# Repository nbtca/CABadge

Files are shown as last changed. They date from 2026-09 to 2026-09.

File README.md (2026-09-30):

# CABadge · 计协电子吧唧

CABadge 是为计算机协会设计的可自定义电子徽章。项目希望将传统吧唧的身份表达与电子屏幕的可变内容结合，让佩戴者通过壁纸、图案和协会名片展示个人喜好与社团归属。

它以日常佩戴和内容展示为核心：平时展示喜欢的画面，需要时通过触摸操作切换内容，通过无线连接或电脑工具更新壁纸、管理设备。界面尽量简洁，让展示内容本身成为主角。

这里收录硬件设计、固件源码、配套电脑工具和实板测试记录，供复刻、改进和协作开发使用。

**当前正式版本：v1.2.0 / 内部固件 7.9.16-eaf-transition。** 包含统一缓存位图转场、Direct Compositor 和内存优化。已完成编译、烧录及基本功能检查；长期稳定性与完整人工验收仍在完善。

[下载 v1.2.0](https://github.com/nbtca/CABadge/releases/tag/v1.2.0) · [发布与升级说明](docs/RELEASE-v1.2.0.md) · [已知问题](docs/KNOWN_ISSUES.md) · [实板测试记录](首板测试记录.md)

当前 `main` 源码版本为 **7.9.16-eaf-transition**，包含 BlueMap 下载/缓存改进、统一壁纸库、EAF Direct 动态壁纸与逐资源 timing、冻结当前帧的页面转场，以及 [动态壁纸转换说明](docs/EAF_TIMING.md)。上方 v1.2.0 下载链接对应同版固件；最新源码构建方法见 [BUILD](docs/BUILD.md)，验证范围见 [HANDOFF](firmware-v7/HANDOFF.md)。

## 可以做什么

- **展示与切换壁纸**：圆形触摸屏展示静态图片，支持浏览、选择和保存上传的壁纸。
- **展示协会名片**：内置计协风格名片页面。
- **连接与管理设备**：Wi-Fi、BLE 连接管理，通过 USB 或本地 HTTP 上传壁纸。
- **基础交互**：触摸操作、亮度设置、息屏后摇晃唤醒，以及可选 FPS 显示。
- **小应用**：Grok 表情、MC 二维地图、奶蛙矿工；使用说明见 [应用](firmware-v7/APPS.md)。
- **电脑端调试**：Windows 原生 NBTCA Badge TOOL 提供固件安装与设备联调入口。

44ebd1ad073642b58210a89b23977e9f
2ba59d724997cc1bf2ca568b1a78c989
10e58efb694e944809ac0757480d7f42

当前源码支持在电脑上将 GIF/视频转换为 EAF 动态壁纸，设备不直接播放 GIF/视频。BLE 传图和 OTA 尚未提供。完整的异常场景和长期稳定性测试仍在完善中。

## 硬件概览

|部分|当前方案|
|---|---|
|主控|ESP32-S3R8，8 MB Octal PSRAM|
|外部 Flash|W25Q128JVSIQ，16 MB|
|显示与输入|360×360 圆形 ST77916 屏幕、触摸输入|
|运动传感器|SC7A20|
|主电源|SGM62117 升降压至 3.3 V|
|充电|TP4056-MS，配合外围供电分配与充电使能电路|
|PCB|直径 50 mm、四层板、名义板厚 1.6 mm|

当前配套硬件为 **JXBadge_EVT_20260909_c7c59dff**。完整器件型号、封装及采购编号见 [BOM](hardware/BOM-DRAFT.csv)。

## 如何开始复刻

复刻需要自行采购、焊接和调试。板上包含 QFN 主控和细间距 FPC 连接器，建议具备贴片焊接与万用表排查经验，并准备放大观察工具及合适的焊接设备。

**流程：下载配套资料 → 核对采购 → PCB 打样 → 分阶段焊接与上电 → 烧录 → 功能检查。** 已有装配完成的同版硬件，可以从第 5 步开始。

### 1. 下载固件与配套硬件

固件下载 [v1.2.0 Release](https://github.com/nbtca/CABadge/releases/tag/v1.2.0)，硬件生产包沿用 [v1.0 Release](https://github.com/nbtca/CABadge/releases/tag/v1.0)。固件版本与 PCB 修订独立编号，v1.2.0 没有改板。

|文件|用途|
|---|---|
|`CABadge-v1.2.0-firmware.zip`|当前三个 BIN、安装说明、原始验证清单与校验值|
|`CABadge-v1.2.0-debug.zip`|ELF、有效构建配置，仅排查问题时需要|
|`CABadge-v1.0-hardware-c7c59dff.zip`|冻结 PCB 生产包、可选钢网文件与下单说明|
|v1.2.0 的 `Source code (zip)`|该次发布源码、硬件设计与文档|

首次点亮直接使用发布固件，无需先搭建编译环境。下载后可通过 Release 的 `SHA256SUMS.txt` 核对附件完整性。

### 2. 核对器件与装配

先查看 [BOM](hardware/BOM-DRAFT.csv)、[采购料号表](hardware/LCSC_IMPORT_LIST.csv) 和 [交互式 BOM](hardware/bom/ibom.html)。交互式 BOM 下载到本地后用浏览器打开，可对照板上位置检查元件。

需要看电路时，用 KiCad 10 打开 [JXBadge_V1.kicad_pro](hardware/JXBadge_V1.kicad_pro)，保留同目录的原理图、符号库、封装库及 3D 模型。

采购时重点核对屏幕完整型号、排线引脚定义、FPC 座的接触方向与封装，不能仅凭“360×360”或“18 针”判断兼容。电池也需核对极性、保护、尺寸与安装空间。BOM 文件保留 `DRAFT` 名称，采购前应结合原理图和 [首板测试记录](首板测试记录.md) 复核，不能当作已验证的即买即装套件清单。

### 3. PCB 打样

解开硬件附件，将其中的 **`JXBadge_EVT_20260909_c7c59dff_PCB.zip`** 交给板厂；不要上传外层发布压缩包，也不要把钢网包当作 PCB 包。

按 [下单说明](hardware/fabrication/JXBadge_EVT_20260909_c7c59dff/下单说明.md) 核对四层、1.6 mm 板厚、50 mm 圆板及目标叠层 `JLC04161H-7628`。叠层、孔工艺和局部间距要求需由板厂确认。需要钢网时，另外使用 `TOP_STENCIL.zip`。

### 4. 分阶段焊接与首次上电

按 [焊接与分阶段上电检查](焊接与分阶段上电检查_首板.md) 分组完成：USB 输入 → 3.3 V 电源 → 主控与 USB 下载 → 屏幕与触摸 → 电池与充电。

首次排查可以只用 USB 供电、不接电池。每增加一组先断电检查焊接与短路，再上电测量；不要带电插拔屏幕排线。确认主电源和主控正常后再接入屏幕。

首板换装的 J1 规格为 **FFC/FPC 0.5 mm、18P、抽屉式上接触**，换座后已成功显示。当前 [BOM](hardware/BOM-DRAFT.csv) 与 [采购表](hardware/LCSC_IMPORT_LIST.csv) 已按截图更正；厂家型号和尺寸图仍未提供，采购前须核对封装与接触方向。**v1.0 旧源码、原理图和交互式 BOM 中仍有原 J1 条目，采购请以 [J1 连接器更正](docs/J1-CONNECTOR.md) 为准。**

### 5. 烧录当前固件 7.9.16-eaf-transition

解压固件包，按包内 `README.md` 或 [安装与构建说明](docs/BUILD.md) 操作。烧录前核对校验值和硬件版本，使用支持数据传输的 USB 线，并释放被其他程序占用的串口。

|文件|烧录地址|
|---|---|
|`bootloader.bin`|`0x0`|
|`partitions.bin`|`0x8000`|
|`firmware.bin`|`0x10000`|

可以用 esptool 直接烧录，也可以使用 v7 工作台的固件安装入口。使用工作台时，将固件解压到源码根目录下的 `outputs/cabadge-v7.9.16-eaf-transition/`；具体 Python 依赖见安装说明。

烧录完成后 RESET，确认启动的固件版本为 **7.9.16-eaf-transition**。不要为了普通升级额外执行全片擦除，以免清掉已有设置和壁纸。

### 6. 检查自己的板子

依次检查开机显示、触摸与翻页、壁纸切换、Wi-Fi/BLE 基本连接，再检查上传壁纸及重启后的保留情况。遇到问题时记录固件版本、触发步骤和现象，附上照片或串口日志，方便复现与修复。

当前背光已使用平方曲线调节实际 PWM，旧 5% 测试上限已取消；CHG_ALLOW 仍保持 LOW。成功开机不代表充电、电流温升或长期运行已完整验收。显示 TE 未连接，动态画面仍需观察是否撕裂；具体待办见 [已知问题](docs/KNOWN_ISSUES.md)。

## 继续开发

完成首次点亮后，再按 [安装与构建说明](docs/BUILD.md) 恢复开发环境。当前工程使用 LVGL 9.4.0；桌面预览基于 SDL2，板端使用 ESP-IDF / PlatformIO。构建脚本仍有 Windows 和 F 盘路径限制，尚未整理成跨平台的一键构建流程。

|目录|内容|
|---|---|
|`firmware-v7/`|当前固件、UI、工作台、协议与测试|
|`hardware/`|KiCad 工程、项目库、BOM 与生产文件|
|`tools/flasher/`|共用烧录工具|
|`docs/`|安装、构建、发布与已知问题说明|

历史实验固件、原始日志和本地备份没有全部随仓库上传，旧文档中的部分研究链接仅保留为历史出处。`v1.0`、`v1.2.0` 标签固定各次发布快照；主分支继续更新。文档分类见 [仓库索引](docs/INDEX.md)。

## 许可

本项目原创内容采用 [MIT License](LICENSE)。第三方字体、库、模型和素材仍遵循各自许可，不因本项目采用 MIT 而改变；字体许可见 [FONT-LICENSE.txt](firmware-v7/ui/FONT-LICENSE.txt)。

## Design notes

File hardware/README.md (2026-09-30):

# CABadge c7c59dff 硬件复刻

当前固件 v1.1.0 使用原硬件基线，未改板。KiCad 10 打开 [JXBadge_V1.kicad_pro](JXBadge_V1.kicad_pro)，保持本目录结构。

## 必须一起保留的文件

- 项目、根原理图、Controls_Test / Display_Sensor / USB_Power 子页、PCB 和设计规则。
- JXBadge.kicad_sym、JXBadge.pretty、JXBadge.3dshapes 及两份 lib-table：工程使用 KIPRJMOD 相对引用，不随意移动或删减。
- [BOM](BOM-DRAFT.csv)、[采购表](LCSC_IMPORT_LIST.csv)、[交互式 BOM](bom/ibom.html)：后者下载后在浏览器打开，辅助焊接定位。
- [冻结生产包与下单说明](fabrication/JXBadge_EVT_20260909_c7c59dff/下单说明.md)：PCB ZIP 和顶层钢网 ZIP 分开使用；MANIFEST 中的文件整组保持一致。

## 采购与装配

3D打印外壳：[V6 三个打印模型（STL）与实物照片](enclosure/releases/V6_20260930/README.md)。用户反馈总体可用、细节仍有瑕疵；打印及装配前先读包内的拨片入口修边说明。

首板换装 J1 为 FFC/FPC 0.5 mm、18P、抽屉式上接触。厂家精确型号及尺寸图仍待提供；[J1 连接器更正](../docs/J1-CONNECTOR.md) 优先于原理图/库/交互式 BOM 中的旧采购标识，不可直接将原 C2856802 当成已验证替代。

### 电池与屏幕连接器

2026-09-30 用户确认当前装配用料，已同步 [BOM](BOM-DRAFT.csv) 和 [采购表](LCSC_IMPORT_LIST.csv)：

- 电池：**450mAh，42×30×4mm，每台1只**；正负两根线直接焊接，**J3电池座不装**。`BAT_EXT` 是整机外购件的清单标识，不是PCB新增位号。容量及尺寸为用户提供，厂家型号、保护板参数和尺寸公差未提供，不推定料号，也不据此宣称充电或挤压验证通过。
- J1：**FFC/FPC 0.5mm、18P、抽屉式上接触，每板1只**，沿用首板换装规格，不是翻盖下接。现用件厂家型号和立创编号仍未提供，不以原 C2856802 代填。

BOM中J3标为DNP、采购数量为0；其旧料号和J1旧封装名仅保留追溯。原理图、PCB、交互式BOM及冻结生产包保持原设计快照，以当前两份CSV的采购/装配状态为准。

板为 50 mm 圆形、四层、名义 1.6 mm，目标叠层 JLC04161H-7628；订单工艺须由板厂确认。制造 ZIP 的正确性检查不等于机械适配、射频、充电或产品可靠性验收。

按[焊接与分阶段上电检查](../焊接与分阶段上电检查_首板.md)逐组断电检查与上电，使用板上 VBUS/3V3/GND/BAT/PWR/EN 丝印。不要带电插拔屏幕排线。

## 固件与证据

下载 [v1.1.0](https://github.com/nbtca/CABadge/releases/tag/v1.1.0)，按[安装说明](../docs/RELEASE-v1.1.0.md)烧录。当前实板结果与历史故障见[首板测试记录](../首板测试记录.md)，不把历史 CAD 检查等同于实板全部通过。

运行 `python docs/check_repository.py` 可核对制造 MANIFEST 文件字节数和 SHA-256。冻结验证目录中的原始源快照用于追溯制造包，不是另一个现行硬件版本。

[精简前硬件设计与 CAD 历史](https://github.com/nbtca/CABadge/blob/d1fe9716b383dcb6fd292d683265beacd92fde64/hardware/README.md)

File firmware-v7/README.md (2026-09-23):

# CABadge 当前实体固件

项目发布 **v1.1.0**，内部版本 **7.9.2-memory**；发布说明、安装与已知边界以 [Release](../docs/RELEASE-v1.1.0.md) 为准。`run.cmd` 打开原生工作台，默认包为 `outputs/cabadge-v7.9.2-memory`，不是旧 USB 画面预览。

## 使用入口

- 展示页：壁纸与蓝色名片；下拉控制中心，上滑功能面板。
- 功能面板：壁纸管理、设置和应用入口；[应用说明](APPS.md)、[Grok 操作](GROK.md)。
- 连接：Wi-Fi、BLE、手机管理；同网或开放直连热点上传/应用/删除壁纸，无授权码和倒计时。
- 设置：显示、设备信息和息屏；亮度驱动实际背光，减少动态直接切终态。设备信息包含外部 16 MB Flash 容量信息。
- USB 保留烧录、状态/控制和壁纸传输；旧像素投屏与壁纸读回已移除。

## 当前显示与内存架构

ESP32-S3R8、8 MiB PSRAM、ST77916 360×360 RGB565、QSPI 40 MHz、CST816D；ESP-IDF 6.1.0、LVGL 9.4.0、esp_lvgl_adapter 0.7.1。PARTIAL、双 360×360 PSRAM 绘图缓冲、DRAW_UNIT=1、DMA queue=2。

静止显示真实 LVGL 控件；静态/半静态转场使用单份 LCD-native RGB565 缓存与 Direct Compositor。缓存未 READY 时走安全路径，动态 App 本体实时绘制。缓存预算 NORMAL 最高 3 MiB，HIGH 软目标 1 MiB，CRITICAL 512 KiB；保护在用缓冲，内存压力下暂停预热。Flash L2 未启用。

LVGL 与 Direct 互斥共用两块 11,520 B 内部 DMA staging；最后 DMA 完成后才通知 LVGL。无 TE，不保证所有动态画面无扫描撕裂。LCD 提交次数不是面板扫描 Hz。

BlueMap 使用 16 KiB HTTP + Pngle 流式采样，不创建整张 RGBA；用户缩略图五项 LRU 加至多一张待提交图。内置壁纸使用 Flash 原图；名片没有独立常驻快照。

## 开发与验证

板端入口：`usb_screen/build.ps1`；[完整构建说明](../docs/BUILD.md)。源码路径：`ui/` 为页面/cache/compositor，`usb_screen/device/src/` 为驱动与服务。`usb_screen` 是沿用的目录名。

最小检查：`test_map_stream.py`、`test_physical_display.py`、`test_transition_compositor.py`。实板检查记录见 [R63/R64](../首板测试记录.md)，软件检查不能替代目视验收。

旧桌面模拟器、像素投屏与废弃测试已移出当前树。保留三个当前内存/DMA/compositor 最小检查和工作台 USB framing 自检；历史工具可从 Git 旧提交恢复。板端构建仍使用 `usb_screen/build.ps1`。

[当前交接与历史演进](HANDOFF.md) · [文档索引](../docs/INDEX.md) · [已知限制](../docs/KNOWN_ISSUES.md)

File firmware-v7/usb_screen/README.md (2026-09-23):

# CABadge 板端服务与 USB 工具

当前版本 **v1.1.0 / 7.9.2-memory**。本目录名称沿用早期 USB 屏幕阶段；现固件直接驱动实体 ST77916，旧 USB 像素投屏及壁纸读回已移除。

## 使用

- 安装：见 [正式发布与升级](../../docs/RELEASE-v1.1.0.md)，或运行 `../run.cmd` 的工作台安装入口。默认包为 outputs/cabadge-v7.9.2-memory。
- USB：烧录、状态/控制、壁纸上传；不提供实时画面镜像。
- 手机管理：在设备“连接 → 手机管理”打开。同一网络访问设备显示的地址；直连模式连接 CABadge-xxxx 开放热点并访问 http://192.168.4.1/ 。无访问码或 300 秒授权窗口。
- 壁纸：手机/电脑裁剪为 360×360 RGB565 后上传，支持保存多张、应用与删除。wallpaper 分区从 0x710000 起，长度 0x8f0000，最多 31 张用户图片；恢复默认不删除图库。旧分区升级注意事项见正式发布说明。
- Wi-Fi：扫描、连接、保存历史网络和重连；手机热点要允许设备访问所需网络。
- BLE：NimBLE 状态/控制、广播与扫描连接；不提供经典蓝牙音频或 BLE 图片传输。
- SC7A20：仅息屏时摇晃唤醒，亮屏不跳页；不是主控深度睡眠。

## 源码导航

|路径|职责|
|---|---|
|device/src/main.c|Adapter 接入、GUI 调度与 USB 服务|
|device/src/physical_display.c|ST77916、触摸、显示 ownership、共享 DMA staging|
|device/src/wifi_service.c / ble_service.c|无线任务与状态|
|device/src/wallpaper_service.c / wallpaper_store.c|HTTP/USB 壁纸库、异步缩略图与持久化|
|device/src/wallpaper.html|手机本地管理页面|
|device/src/app_service.c / map_png.c|BlueMap 网络与流式解码|
|../ui/ui_transition_cache.c / ui_transition_compositor.c|缓存、预热及 Direct 转场|
|../workbench.py / framing.py|当前原生工作台与 USB 编解码|

构建入口 `build.ps1`，实际环境见 [构建说明](../../docs/BUILD.md)。当前有真实背光 PWM 和 LCD/触摸驱动，不再采用早期“只在电脑显示”的接法。不要按旧说明拔屏或烧录 v4/v5 预览包。

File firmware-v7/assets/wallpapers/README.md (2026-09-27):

# EAF 动态壁纸

7.9.14-eaf-direct 保留 `espressif/esp_lv_eaf_player 0.3.0` 的底层格式解析、RLE 解码和调色板转换，旁路 `lv_eaf` 对象/定时器。目标 33,333 us/帧（30 FPS），无限循环；首页逐帧由 Direct Compositor 输出，不经过 LVGL renderer。完成提交率不等于面板扫描刷新率。

`live_test.eaf` 是 360×360 测试动画。资源**不编进应用**；导入后作为 `EAF` 条目存入现有 `wallpaper` 分区的普通壁纸槽，和静态壁纸一样选择、删除、保存当前选择。开机不会重新导入已删除资源。

在项目根目录使用：

```powershell
python tools/upload_eaf.py firmware-v7/assets/wallpapers/live_test.eaf --port COM3
```

其他素材的格式、转换与 timing 要求见 [动态壁纸转换说明](../../../docs/EAF_TIMING.md)。转换工具不随仓库发布，上传工具保留。7.9.15起可用配套 timing metadata 保留原始播放节奏；没有 metadata 的旧 EAF 默认30FPS。

## 读取与生命周期

- 组件的文件路径 API 会完整读文件入 RAM，因此本项目使用 `esp_partition_mmap` 和 `esp_eaf_format_init`，直接引用 Flash 压缩数据，不注册第二套文件系统。
- 正常只保存一张 259,200 B RGB565 解码帧及 8,640 B 可复用索引块；帧索引、后端及解析临时缓冲使用 PSRAM。每帧调用官方 RLE 解码器，按调色板直接写入 LCD 字节序的当前帧；不复制完整帧到 LVGL buffer。构建时仅对固定版本组件关闭分配失败后回退内部 RAM 的路径；软件 JPEG 关闭。
- 干净首页实时播放；按下开始手势、菜单/应用、转场、息屏，以及状态入口/提示/HUD 显示时暂停并交回 LVGL；返回干净首页恢复。切换壁纸删除旧播放器后再解除旧 Flash 映射。暂停保留当前解码帧，不重复创建播放器。
- 动态首页不进入 Raster Cache。需要该背景的转场安全回退到暂停帧的 LVGL 路径，其他静态页面的 Direct Compositor 不变。
- 动态缩略图在首次选择后从已解码帧生成，纳入已有缩略图 LRU；尚未选择/已淘汰的动态项仍可按文字选择，不在后台另开播放器制作预览。
- USB 管理状态 `wallpaper.types` 给出 STATIC/EAF；`wallpaper.eaf` 提供 loaded/playing/frame/creates 和创建时堆差额，便于基本检查，不开启串口文本日志。

Flash 格式：保留旧静态 `JXWL` 记录，新增 `JXWE` EAF 记录；每槽大小、已有图片 ID、分区表均不变。7.9.13 起，大 EAF 使用连续空槽（一个 3 MiB 文件占 12 槽），静态图片仍用一槽。空间不足或没有足够连续空槽时拒绝上传，不移动或覆盖其他壁纸。EAF 上传按接收进度逐扇区擦除、分块写 Flash，校验后才发布记录，不申请完整文件大小的 PSRAM；未完成上传在重启扫描时清理。删除正在播放的 EAF 时先暂停源读取，再擦除与释放。旧版固件不识别 EAF 槽，回退旧版后请勿继续上传，以免旧版把动态槽当作空闲覆盖。

## 直出所有权与内存（7.9.14）

复用 `ui_transition_compositor` 的现有 4 KiB 栈任务和 `physical_display` 的两块 11,520 B DMA staging。worker 在上一帧 DMA 排空后才解码下一帧；每帧按 16 行分块搬运到 staging，共 23 次 draw 提交。无另一张完整中转 framebuffer，不把完整压缩动画读入 RAM。

暂停由 GUI 发送停止消息并等待 worker 确认，依赖真实 LCD drain 完成；再恢复 LVGL 显示所有权。在 GUI 锁内把同一当前帧原地转为 CPU RGB565，供冻结画面、缩略图和转场使用。恢复后 worker 直接解码下一帧为 LCD 字节序。真实页面及触摸仍由 LVGL 管理，worker 不调用 LVGL。动态背景涉及的旧安全转场路径保留。

USB `wallpaper.eaf.timing` 提供聚合耗时，无逐帧文本日志：`decode_us`、`staging_us`、`submit_us`、`dma_drain_us`、`interval_us`。submit 包含前一块 DMA 等待；dma_drain 仅为最后一块剩余等待，不能当成整帧 DMA 时间。统计在每次直出恢复时重置。

本轮短时实板：罗小黑 210 帧素材，最后 180 帧完成间隔平均 33.378 ms（约 29.96 次/秒），最差 39.319 ms。菜单/息屏暂停、恢复不重建、静态/动态切换经 USB 状态确认；没有长期压力及物理扫描率测量，无 TE 下视觉撕裂仍需实屏确认。详见主测试记录 R79。

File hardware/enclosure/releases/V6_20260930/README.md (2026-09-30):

# CABadge V6 外壳打印文件

2026-09-30 实物试装版本。用户反馈：**“总体可以的，有些细节有瑕疵。”** 保留当次打印文件，不是消除全部瑕疵后的定版。

## 三个打印模型

- [上壳 V6_Upper.STL](V6_Upper.STL)
- [下壳 V6_Lower.STL](V6_Lower.STL)
- [电源拨片 V6_Slider.STL](V6_Slider.STL)

三个模型合计323252字节（约316 KiB）。单位mm，切片保持100%比例。不上传SW装配、PCB参考件或其他模型。

名义最大外径62mm、总高13.9mm，中段外鼓，两片壳体胶粘。叠层为屏幕—42×30×4mm电池—PCB，元件朝屏幕；不装电池座，两根线直接焊接。BOOT/RESET不留外部孔。这些是设计参数，不是照片实测。

## 已知装配注意

原上壳拨片外侧宽凹槽底部两侧各有约0.4mm薄挡边，CAD复核发现会阻挡装入。若拨片装不进去，仅将这两处薄边修通至下沿，不剪内导轨或拨片限位片；对空壳少量修整并去毛刺，不带着屏幕、电池剪。用户曾表示必要时修剪，但未明确反馈是否已剪。

先干装：屏幕FPC先穿过上壳并接好，整理绝缘片、电池及内部走线；**拨片先从外侧套到开关柄，再将上壳罩下**，最后屏幕落在背胶承托台阶。封胶前确认USB线插到底、开关两端到位、线不夹缝、电池不受压。

## 用户实物照片

照片展示打印外壳及装入点亮的屏幕，不单独证明内部无顶压、USB/拨片全功能或长期使用通过。具体瑕疵尚待反馈。

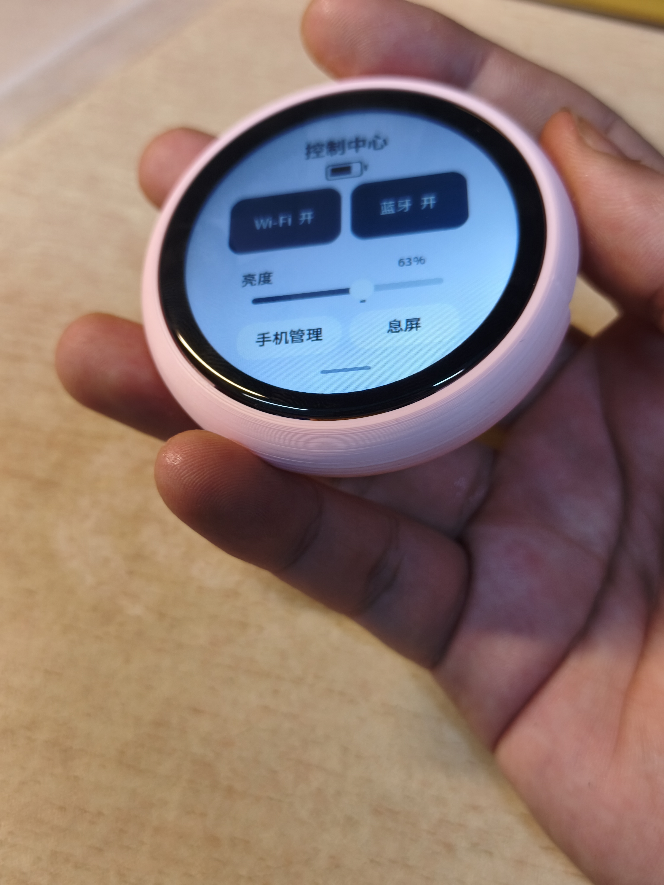
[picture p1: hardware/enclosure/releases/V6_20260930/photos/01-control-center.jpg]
控制中心与手持外观


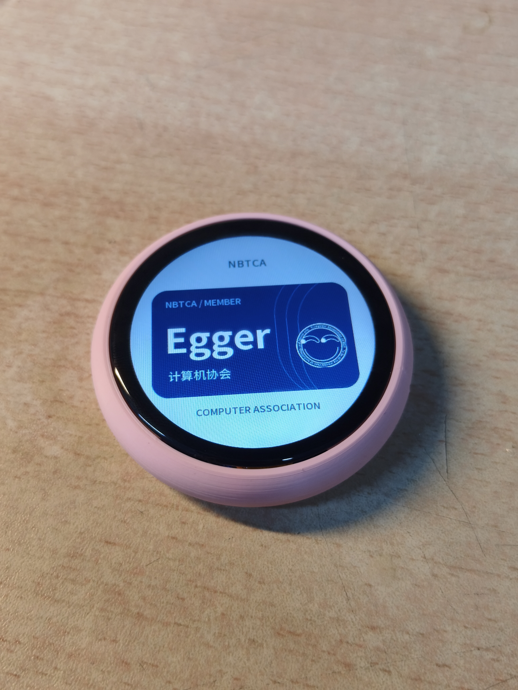
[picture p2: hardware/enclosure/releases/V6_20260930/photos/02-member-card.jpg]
会员名片与外壳正面


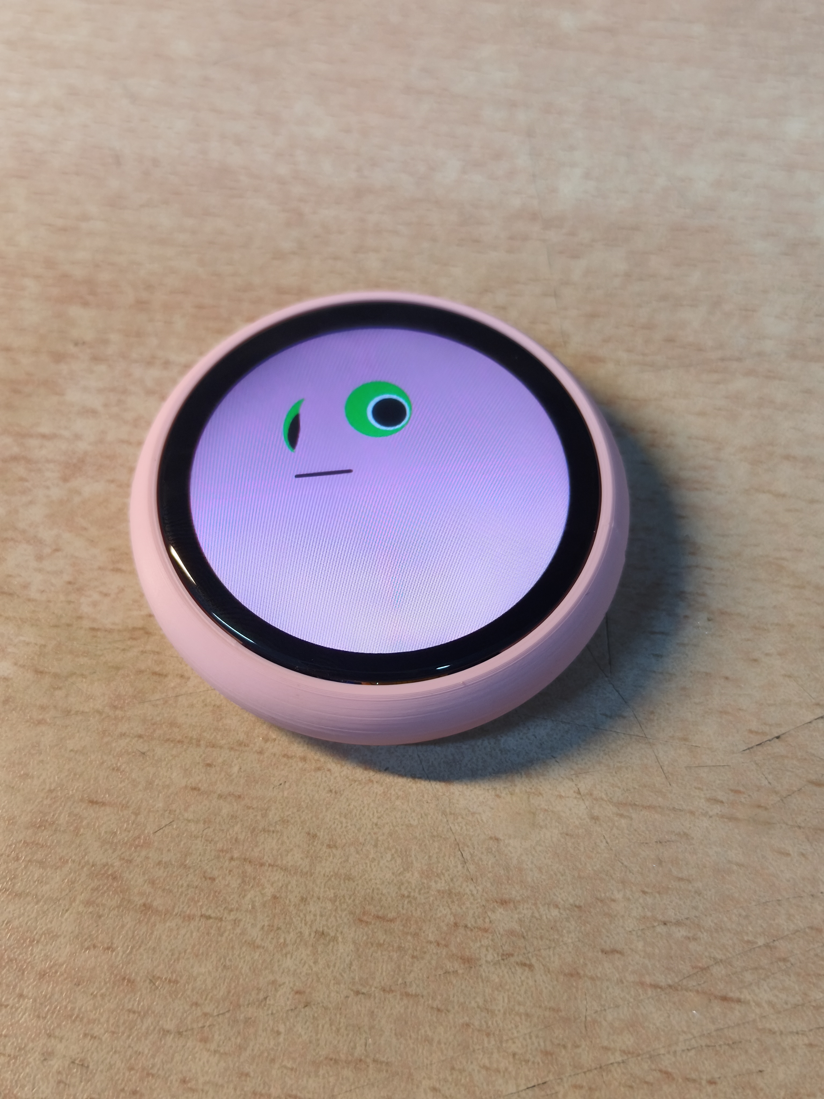
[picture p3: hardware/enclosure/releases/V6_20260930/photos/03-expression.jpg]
表情画面与外壳正面


`SHA256SUMS.txt`用于校验3个STL及3张原照片的下载完整性，不代表实物验收。本次不修改PCB或固件。

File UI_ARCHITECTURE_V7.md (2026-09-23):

# CABadge 当前 UI 与转场架构

版本：v1.1.0 / 7.9.2-memory。本文以当前源码为依据，描述实现和所有权，不是最初 PC 预览方案，也不宣称完整性能/交互验收。

## 运行链路

```text
CST816D / 服务状态
        ↓
GUI task：真实 LVGL 页面、输入、业务状态、缓存预热
        ├─ 静止/普通刷新 → esp_lvgl_adapter → physical_display → ST77916
        └─ 合适的页面转场 → 已就绪 LCD-native RGB565 cache
                            → Direct Compositor worker
                            → physical_display → ST77916
转场结束：排空 DMA → 交还 LVGL → 恢复真实目标页
```

平台为 ESP32-S3R8、8 MiB PSRAM、360×360 RGB565、QSPI 40 MHz；ESP-IDF 6.1.0、LVGL 9.4.0、Adapter 0.7.1。PARTIAL 模式、两个 360×360 PSRAM draw buffer、DRAW_UNIT=1、transaction queue=2。配置依据在 [sdkconfig.defaults](firmware-v7/usb_screen/device/sdkconfig.defaults) 与 [组件清单](firmware-v7/usb_screen/device/src/idf_component.yml)，发布实际配置同时保存在 Release 调试包。

## 页面职责与导航

展示页包括壁纸与蓝色名片；下拉控制中心、上滑功能面板。功能入口连接壁纸管理、设置和应用。设置/连接相关页面包含显示、设备信息、Wi-Fi、BLE、手机管理。应用包括 Grok、BlueMap 和奶蛙矿工。

[badge_ui.c](firmware-v7/ui/badge_ui.c) 中 `badge_ui_create()` 创建对象，`badge_ui_page()` 处理页切换，`navigation_prewarm()` 维护实际导航预热优先级。缓存 page ID 与业务页索引是不同概念，不应直接用同一数值猜测对象。

设置↔连接使用 `(50,28)`、250×272 局部 viewport；`connection_wrap()` / `connection_enter()` / `connection_leave()` 负责内容组织。其他页面按实际 surface 大小注册，不应把这个局部尺寸套给所有转场。

## 模块边界

|模块|责任|
|---|---|
|badge_ui.c / wifi_panel.c|真实页面、控件、手势与视觉状态更新|
|apps.c / grok.c / miner.c|应用页面与各自实时逻辑|
|ui_transition_cache.c|surface 注册、revision、预热、预算、淘汰、在用引用|
|ui_transition_compositor.c|offset 对应图层、裁剪/stride、分块合成、worker 生命周期|
|physical_display.c|LCD 提交、显示所有权、触摸和共享 DMA staging|
|main.c|Adapter 接入、GUI/service 调度、USB 协议|
|app_service.c / map_png.c|BlueMap 网络与解码 worker、结果交接|
|wallpaper_service.c|上传、持久化、后台缩略图与 GUI 提交|

模块路径及入口见 [板端服务说明](firmware-v7/usb_screen/README.md)。业务页面不直接调用 SPI API。

## 缓存生命周期

`ui_transition_cache_register()` 注册真实不透明 subtree；视觉变化调用 invalidate，导航调用 plan/request。`ui_transition_cache_poll(idle)` 在 GUI 线程空闲时每轮最多构建一张：布局 → LVGL snapshot RGB565 → 一次 byte swap → READY。

构建是 GUI 内的受控空闲工作，不是从独立线程调用 LVGL。存在触摸、动画、活动转场、暂停或高内存压力时停止预热。透明根/ext-draw 等不适用对象保留 fallback。

缓存仅长期保存一份 LCD-native RGB565；revision 匹配才有效。动画使用期间 pin，完成后才释放使用权。hide/show/reparent 不应直接等同于视觉变更。页面真正销毁或预算压力可以释放缓存。

当前 NORMAL 预算最高 3 MiB，HIGH 软目标 1 MiB，CRITICAL 512 KiB；优先保留当前/hot/在用资源，故软目标不是绝对占用上限。按 priority/LRU 选择淘汰，低空闲内存停止非必要预热。退出高内存 App 并确认 worker cleanup 后恢复导航热集。Flash L2 未启用。

相关实现：`ui_transition_cache_plan()`、`ui_memory_pressure_set()`、`ui_transition_cache_poll()`、`ui_transition_cache_direct()`。缓存 miss 不同步截图等待用户，回到现有真实控件安全路径；不能将 LCD-native 数据当普通 lv_image 像素使用。

## Direct 与 DMA 所有权

`ui_transition_compositor_begin/present/stop()` 接收最多四层不可变缓存描述，保留 stride、位置及裁剪信息。worker 按块读取/合成，不每帧分配完整 framebuffer。它仍有 staging copy，不能称为零拷贝。

`physical_display_transition_acquire()` 在实际传输完成后交接；`physical_display_transition_release()` 在 Direct 最后一批传输结束后交还。普通 LVGL 与 Direct 不能同时向 LCD 提交。

两条路径共享两块 11,520 B 内部 DMA buffer。普通 LVGL 路径逐 16 行复制/提交，只在最终块完成后通知 Adapter/LVGL；缓冲复用和所有权释放依赖真实 completion/drain，不用固定 delay 猜测。

Direct stop 等待 worker 完成后才能解除源缓存 pin。取消、cache miss、源不可用和内存不足走安全退化；减少动态直接到终态。转场结束恢复真实页及输入，状态变化不能被旧截图永久覆盖。

## 动态资源与服务

Grok、BlueMap、游戏本体不冻结为长期截图。进入/退出的转场仅在合法 surface 可用时使用缓存，否则走安全路径。

BlueMap：16 KiB HTTP 输入 → Pngle 增量解码 → 128×128 RGB565 tile（最多九张）→ 360×360 输出。保留上/下半图结构识别与完整性校验，不创建完整 RGBA。worker 完成后由 GUI 接收结果，退出等待实际 cleanup；旧/新 framebuffer 在交接期可并存。

内置壁纸使用 Flash 原图；用户缩略图采用五项 LRU、最多一张待提交图，三张可见图受保护。正常页面通过真实服务状态刷新，视觉变化使关联缓存失效。

## 调试与验证边界

正常使用直接观察实体屏；旧 SDL2/USB 像素镜像不是当前验收路径。详细性能统计由 CABADGE_DISPLAY_PERF 控制，正式包为关闭；轻量 cache debug 开启。无 TE，DMA 完成不等于面板扫描完成。

当前实板证据见首板记录 R63，构建/安装见 [BUILD](docs/BUILD.md)。旧桌面实验工具已删除；长期稳定性和人工目视范围见 [仓库检查（历史）](https://github.com/nbtca/CABadge/blob/d1fe9716b383dcb6fd292d683265beacd92fde64/docs/REPOSITORY_CHECK.md)。本架构说明不引入新的 API、参数或功能。

[重写前 PC 预览架构（历史固定快照）](https://github.com/nbtca/CABadge/blob/107f518cade6b85d44fc918d985363973a5d8b22/UI_ARCHITECTURE_V7.md)

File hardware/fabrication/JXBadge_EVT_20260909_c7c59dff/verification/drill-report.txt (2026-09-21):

Drill report for JXBadge_V1.kicad_pcb
Created on 2026-09-09T21:08:26

Copper Layer Stackup:
    =============================================================
    L1 :  F.Cu                      front
    L2 :  In1.Cu                    in1
    L3 :  In2.Cu                    in2
    L4 :  B.Cu                      back

Drill file 'JXBadge_V1-PTH.drl' contains
    plated through holes:
    =============================================================
    T1  0.200mm  0.0079"  (15 holes))
    T2  0.250mm  0.0098"  (219 holes))
    T3  0.800mm  0.0315"  (4 holes)  (with 4 slots)

    Total plated holes count 238

Drill file 'JXBadge_V1-NPTH.drl' contains
    unplated through holes:
    =============================================================
    T1  0.600mm  0.0236"  (6 holes))
    T2  1.000mm  0.0394"  (2 holes))

    Total unplated holes count 8

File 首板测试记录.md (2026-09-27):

> **当前索引（2026-09-24）：正式发布 v1.1.0 对应 7.9.2-memory；当前开发实板已烧录 7.9.7-maplod。** BlueMap LOD2/3 大图修复与一次实板检查见 R70，正式发布归档见 R64；[当前固件](firmware-v7/README.md)、[安装说明](docs/RELEASE-v1.1.0.md)。下面的 R39/R38 等摘要均为历史阶段。单次实板检查不代表长期稳定或完整目视验收。

> 2026-09-23 R39：直接迁移ESP-IDF 6.1的7.4.0候选已编译/烧录，但用户反馈仅背光、无图像，F11显示失败。已回退7.3.10-mem（IDF5.5.0），用户确认图像恢复；工作台仍默认7.3.10。正在排查6.1的SPI兼容性，不能把MCU提交计数当作实屏通过。

> 2026-09-23 R38：基于7.3.7完成分阶段内存优化，当前实板读回7.3.10-mem。13场景内部空闲最低采样36951→72511 B（增加34.73 KiB），静态BSS减少12288 B；壁纸/抽屉/名片提交FPS约28.21/25.09/21.71，无明显帧率提升。BLE授权读写/通知与USB上传取消通过；按用户要求移除工作台预览入口及固件壁纸读回。Wi-Fi未连接，真实HTTP及新版本目视/长期验证仍待测；保留F09，新增F10记录7.3.9一次USB采样超时。详见firmware-v7/MEMORY_OPTIMIZATION_REPORT.md。

> 历史v7实测：2026-09-21 R37：7.3.6-anim16实验失败并已回退7.3.5。动画周期33→16ms使壁纸28.38→51.31FPS，抽屉24.34→23.97、名片20.40→20.74基本不变；用户报告“壁纸页面壁纸缩略图有略微撕裂”，记录F08。已烧录7.3.5、校验哈希并读回版本；源码也撤销动画16ms，保留显示16ms，默认安装一直为7.3.5。本次回退后的目视恢复仍待确认。候选数据保留在firmware-v7/ANIM16_REPORT.md，不能作为通过版。

> 历史v7实测：2026-09-21 R36：7.3.5-refresh16已烧录/读回，实体显示刷新周期33→16ms，用户反馈没有撕裂、重复或触摸异常，工作台默认切换。观测壁纸28.08→27.74、抽屉19.10→24.23、名片21.07→20.82内容提交FPS；静态均0。旧Wi-Fi未连接、新版自动连接，且启动历史不同，非严格受控A/B；不将内存差异归因于改动。LVGL动画定时器仍33ms。详见firmware-v7/REFRESH16_REPORT.md，TE/长期/触摸仪器延迟仍有限制。

> 历史v7实测：2026-09-21 R35：独立v7双绘图缓冲异步版7.3.4-async已烧录/读回，用户确认“显示正常，没有发现撕裂或重复”。工作台默认安装已切换。基于同轮7.3.3，壁纸26.31→26.74、抽屉17.95→19.29、名片16.91→21.26内容提交FPS；静态0。两块整屏容量PSRAM PARTIAL缓冲、core1传输worker，保留40MHz连续CS及原DMA所有权。内部周期最低9027B、main/LCD剩余栈5168/2060B。第二轮受用户触摸干扰，保留但不纳入正式对照。详细探针有帧末等待，与常态异步FPS分开解释；未运行模拟器。无线扫描通过，手机连接上传/长期稳定仍待测，TE未接不承诺绝对零撕裂。证据见firmware-v7/ASYNC_DMA_REPORT.md；Article分支R34失败/待测记录保持独立。

> 历史实测：2026-09-21 R33：流畅度优先版 7.3.3-fluid 已烧入 COM3 并读回版本，工作台默认安装已切换。取消 Carousel，改为原生定尺寸横向分页；保留蓝色名片、无线/壁纸/USB服务和FPS开关。PSRAM改80MHz/64字节缓存行，LCD仍40MHz。实板壁纸浏览5.55→28.40、抽屉13.42→17.61、名片11.90→17.37内容提交FPS；不是面板Hz。内部32行绘图试验变慢已回退，原DMA完成后复用规则保留。10/10软件回归通过；无线扫描场景通过，手指跟手/目视、手机连接上传和长期稳定待用户验收。内部周期采样最低7331B，余量仍紧。详见 firmware-v7/FLUID_PERFORMANCE_REPORT.md 和主记录R33。

> 历史实测：2026-09-21 R32：用户要求定位影响帧率的无用任务并增加实体 FPS 开关。已烧录并读回7.2.3-monitor；静态 main 单核CPU 97.31%→4.51%，修正pdMS_TO_TICKS(5)=0忙轮询；旧USB像素投屏已移除，5Hz状态查询没有测出主要帧率影响。设置→显示→FPS可开关，默认关闭；排除自身刷新和LVGL内部取整事件，最终静态/HUD静态均0。Carousel/抽屉/名片完成提交率 6.6/13.72/11.88 FPS，未达30FPS；内部空闲最低11803 B。用户确认前轮跳页因自己触摸，菜单/名片静态重测为0。Wi-Fi/BLE扫描和广播通过；手机连接、上传、长期稳定与FPS目视待复测。详见firmware-v7/RUNTIME_PERFORMANCE_REPORT.md和outputs/performance/runtime-20260921-164334.json。

# JXBadge V1 首板测试记录

最后更新：2026-09-27 · 记录版本：R75（新增外壳试装反馈，未改变固件测试结论）· 持续维护的主测试文档

## R74机械补充索引（2026-09-27）

用户提供屏幕与PCB合拢侧照、卡尺读数8.4mm照片，并要求整机含电池和底壳厚度小于15mm、上下壳胶粘、取消螺丝柱、上壳Type-C缺口向下敞开。侧照可辨PCB元件面朝屏幕；8.4mm暂按不含电池的屏幕+PCB叠层解释，但卡尺照片未同时呈现测量接触面，不虚构精度或重复测量结果。此前反向叠层仅为CAD假设，本次撤销；不是硬件或固件故障。

原始图片：`F:/xwechat_files/wxid_0f7c15tbuo7i22_ef23/temp/RWTemp/2026-09/9e20f478899dc29eb19741386f9343c8/d17d4e78b8b9579f3fc5727e4318691e.jpg`（侧照）、同目录`d119063381486dc64ab04bf5b9f1212d.jpg`（卡尺）。电池42×30×4mm仍为用户设计假设，不升级为实测。

本机读取J2封装`hardware/JXBadge.pretty/TYPE-C-31-M-12_C165948.kicad_mod`及其STEP模型：模型外宽8.940mm、相对板面Z=-0.850到3.251mm（主体顶3.250mm，标记高0.001mm）；封装禁布区宽10.36mm不等于器件金属外宽。这是库数据，不是实物卡尺尺寸。V4设计预算14.6mm及Type-C下开口10.0×3.6mm属于CAD草稿，打印公差、插头塑壳空间、胶层和最终实装仍待确认。没有修改固件、PCB或烧录；电气与软件状态沿用历史记录。

R74本机CAD检查补充：V4名义总厚14.6mm、无螺丝柱、Type-C下开口已在SolidWorks实现。原生文件重开无错误；上下壳STEP及原KiCad整板模型等15组组合无实体重叠，两片STL为单个封闭实体。SW导入PCB参考件存在约1.01%体积差，未宣称等价；干涉检查使用原始PCB STEP而非该显示参考。证据`hardware/enclosure/sw_v4_glue/verification.json`、`native_audit.txt`、`mesh_audit.json`。上述均为软件检查，不代表实物装配通过。

R74外壳几何纠正：用户指出V4上壳排线处断成C形，以及两侧零碎槽。原贯穿切口属于建模错误，“封闭STL/无干涉”未覆盖环形连续性和局部结构合理性。现仅重建上壳该区域：排线位置下方保留3.1mm高连接壁，上方局部避让覆盖两侧台阶，消除槽和尖薄片；Ø53、14.6mm名义总厚及Type-C下开口保持。新增STEP连接壁实体检查和STL环形拓扑检查，原生上壳重开错误/警告为0。旧版保存在`hardware/enclosure/sw_v4_glue/before_fpc_fix/`；仍未进行实际打印、胶粘或排线弯折验收。

## R75外壳试装反馈（2026-09-27）

用户提供4张黄色上壳实物试装照片，报告电池导线被原壳卡住，必须手剪缺口才能引出；屏幕下部与排线区域侧向裸露，要求增加遮挡外圈。照片可见PCB背面外露、电池外置，不能视作上下壳和内置电池总装验收。用户更正已购电池为52×34×4mm，并补充导线含绝缘皮外径1.2mm；均按用户反馈记录，未冒充本机测量。

原照片位于`F:/xwechat_files/wxid_0f7c15tbuo7i22_ef23/temp/RWTemp/2026-09/9e20f478899dc29eb19741386f9343c8/`，文件为`f741140219e767d58c93557880fbb3c6.jpg`、`8ca7d282f60b786cbaa58be18b7b69be.jpg`、`07ff0e27b1b64bf9e2b596f8501fb6e7.jpg`、`cc729ebfa4b67eb0738ff1882dd3aafa.jpg`。这些反馈推翻“仅凭无实体干涉即可判断布线可用”的假设；R74的CAD结果保留其原始范围，不升级为实装通过。

V5在`hardware/enclosure/sw_v5_rim_wire/`另存修订：外径56.4mm、总厚14.6mm，恢复连续屏幕遮挡外圈，增设绕PCB边缘的内部双线通道，取消电池固定尺寸限位条并核算仓内最大长宽组合。保留V4文件。52×34矩形对角线约62.13mm，紧凑圆壳无法容纳；不默认扩大整机来迁就误购电池。实际打印、1.2mm导线弯折和胶粘装配仍待复测。本轮不修改固件或PCB。

R75本机CAD复核：初版检查发现绝缘片角部与定位台阶约0.398mm³重叠、线槽底转向包络约0.156mm³重叠，均修正后复查；装入路径复核还发现整圈定位环缩口问题，最终下壳改为90°/180°/270°三处PCB支撑/定位台。最终SW上下壳各1个有效实体，44/36个特征，重开错误和警告均0；6部件装配坐标检查通过。15组STEP部件交集为0，Type-C下开口、FPC连接壁、屏幕遮挡圈连续性、电池仓净空、两根1.2mm线的Ø1.6mm余量包络检查通过。六组电池包络42×30×4、46×25×4、43×30×4、40×34×4、39×35×4、37×37×4均通过仓内空间和从上方直放的扫掠检查；尺寸含封边/保护板，额外出线和实际弯折仍待实装。此处检查没有完整柔性线缆或FPC变形模型，不能代替物理装配验收。

电池仓名义Ø53.4mm；单边0.3mm余量下，宽30时长≤43.16mm，宽34时长≤40.07mm，正方形考虑所选走线出口约37.05mm边长；厚度预算4.0mm。52×34×4按相同余量/壳壁需最低约Ø65.96mm，此版不适配。证据为V5目录下`verification.json`、`native_audit.txt`、`mesh_audit.json`；用户4张原照片原样归档至`evidence/`。原PCB哈希仍为c7c59dff，PCB的SW导入差异沿用R74限制，干涉检查仍使用原KiCad STEP加U6包络。

## 当前结论

2026-09-23 R38：基于7.3.7完成分阶段内存优化，当前实板读回7.3.10-mem。13场景内部空闲最低采样36951→72511 B（增加34.73 KiB），静态BSS减少12288 B；壁纸/抽屉/名片提交FPS约28.21/25.09/21.71，无明显帧率提升。BLE授权读写/通知与USB上传取消通过；按用户要求移除工作台预览入口及固件壁纸读回。Wi-Fi未连接，真实HTTP及新版本目视/长期验证仍待测；保留F09，新增F10记录7.3.9一次USB采样超时。详见firmware-v7/MEMORY_OPTIMIZATION_REPORT.md。

历史R37：板端曾从7.3.6回退并读回7.3.5；7.3.6因壁纸缩略图撕裂判失败，回退后目视恢复待确认；以下Article记录属于另一条独立固件，不能把其中失败当作本版失败，也不能用本版通过结论关闭Article的F07。

2026-09-21 Article后续反馈：用户报告“滑动时上下画面错位，停下恢复”。按当前对话推定为8.0.0 Article测试版，未读回板上版本/哈希。记录动态显示失败F07；此前7.1.2恢复结论保留。源码确认Article每10行绘制后立即写屏，与旧整帧合成后连续传输不同；TE未接下的扫描/写入不同步是首要解释，尚无新视频或时序测量。8.0.1整帧提交候选已构建、两种配置各22/22通过，未烧录、实屏待复测，不能预先判恢复。

首板已完成供电直流初筛、USB 下载、Flash/PSRAM 诊断、加速度计基本读数、电池 ADC 对表，以及 Wi-Fi 连接收发和 BLE 连接/断开重连。Wi-Fi 与 BLE 同时保持连接期间，已提供的日志中未见异常重启。

**整机测试尚未完成。** 此前屏幕黑屏；2026-09-21 换座后用户反馈“正常显示成功”，显示点亮按用户反馈通过。后续 v7 实屏视频确认基础触摸交互能响应，历史曾出现动画撕裂、标题重复（D04/F04）；R26用户确认7.1.2已消失，主要剩帧率低；触摸全范围/中断、背光实际电流、完整充电过程、纯电池无线负载和长时间运行尚未通过验证。

本文件记录实际结果；[焊接与分阶段上电检查](焊接与分阶段上电检查_首板.md)是操作参考，两者不要混作一份实测报告。

2026-09-20 新反馈：用户报告 nRF 搜不到设备（L05）。代码确认 UI v1 未启动 BLE；当时板端版本未提供，不能据此断定硬件故障。已发布 UI v2，加入双角色 BLE 和仅息屏摇晃唤醒；软件验证归 T05，尚未烧录或取得新版实板复测结果，原诊断通过范围保持不变。

后续 02:47 用户截图复测：工作台 COM3 已连接并显示蓝牙页，累计接收 320 帧；页面显示“对方已连接本机”，来访地址 `7E:F3:BF:77:6F:3F`，附近设备列表可见“未命名设备”。据此确认该时刻实板 UI 投屏和 BLE 来访连接显示；没有固件哈希读回，按 v2 功能界面记录，不扩展为主动连接、摇晃或 Wi-Fi 图形配网通过。

2026-09-20 无线 P0 v4 软件更新：新增短时设备授权、Web 管理及 BLE 状态/控制协议；沿用既有上传和存储。只记录软件检查 T07，新实板项目 N16 待测。没有新增测量值、串口日志或自动烧录，既有实测结论不变。

2026-09-20 后续实板反馈（R12）：用户对上一轮四步操作整体回复“正常”。按该轮操作范围记录 v4 安装并连接 USB 屏幕、打开手机管理页、手机上传壁纸后在 USB 屏幕显示、完全断电再上电后壁纸保留为用户反馈通过。未提供逐项日志、截图、固件哈希或网络路径，不能分别认定同网和直连热点两条路径均通过；授权拒绝、Web 控制、BLE GATT 等仍待测。

2026-09-20 后续实板反馈（R13）：用户对手机网页控制四步整体回复“正常”。按该轮范围，设备页电池电压/Wi-Fi 状态与实际一致、网页息屏/唤醒作用于 USB 投屏且壁纸保留、预览亮度变化、工作台关闭管理后手机操作被拒绝及重新开启使用新入口恢复，记为用户反馈通过。未提供逐项日志或数值；不扩展为实体背光、自然满 5 分钟过期、错误码输入或 BLE 授权通过。

2026-09-20 后续实板反馈（R14）：用户对上一轮 BLE 四步整体回复“正常”。按该轮范围，nRF 连接 CABadge、未授权 Status 读取被拒绝、Session 写入当前授权码后读取 20 字节状态并收到状态变化通知、Control 息屏/唤醒/50% 预览亮度、断开重连后须重新授权，记为用户反馈通过。操作要求保持 Wi-Fi 连接，按此范围记录 BLE 基本读写时连接共存；没有同时 Wi-Fi 数据流、持续时长、原始 ATT 数据或错误码截图，不能升级为并发负载/长期稳定性通过。自然满 5 分钟过期未包含在本轮操作中，仍待测。

2026-09-20 UI v5 软件更新（R15）：依据《用户端设计准则.md》完成壁纸优先、三入口菜单、计协蓝配色和静态壁纸选择记忆。软件验证归 T08，新版实板回归 N17 待测；没有新增测量或实板通过结果，R12～R14 仍仅代表 v4 用户反馈。上轮提出的 5 分钟自然到期测试尚未收到结果。

2026-09-20 v7 核心预览软件更新（R16）：用户确认受限 PC LVGL + USB 实板服务架构后，独立发布 `7.0.0-preview`；新增 T09 软件检查和 N18 实板待测。原 v6 工作区及旧工作台入口未覆盖；未打开 COM 端口或烧录，本轮没有新增硬件通过结论。

2026-09-21 R24：核对用户Baidu目录厂家资料，9文件与项目旧资料一致。发布 **7.1.2-lcd**（`outputs/cabadge-v7-lcd-refresh-20260921`）：PSRAM完整帧合成，40MHz QSPI一次窗口/RAMWR、CS保持、双内部DMA排队，传完再复用缓冲；实体端省掉软件圆形裁切/亮度遮罩。新增含实体输出的性能采样，结果不覆盖无屏校准。构建、9/9 CTest、DMA生命周期/错误/字节序、协议和工作台检查通过。未打开COM、未烧录，F04/D04失败保留，N21待实测；TE仍未接，不承诺纯软件零撕裂。入口 `firmware-v7/run.cmd`；v6代码未改，仅同步交接摘要。

2026-09-21 R27：发布7.1.3-lcd（`outputs/cabadge-v7-render-fast-20260921`），工作台安装源已切换。实际编译UI/LVGL为-O2，内置壁纸RGB565/RAM缓存、180px圆角缩略图缓存、蓝色名片整页缓存；动效/手势保留。约新增1.11MiB缓存；QSPI40MHz和物理驱动与7.1.2相同。10/10 CTest、缓存替换/失败回退、DMA、协议、烧录预检/工作台烟测通过；PC对照仅为软件路径证据，实机提升待N22同场景采样。用户R26确认7.1.2撕裂已消失，历史失败保留。50MHz请求在当前80MHz APB整数分频下仍得到40MHz，未超频。本轮未打开COM、未烧录；v6代码未改。

## 1. 样机、环境与证据口径

2026-09-20 v7 联调反馈（R18）：用户 07:32 截图显示“实板已连接”，但点击 Wi-Fi、蓝牙出现“设备忙”。关闭旧 PC 预览后，通过 COM3 实际取得 v7 握手及状态：`reduced_motion=true`、板端报告 `7.0.0-preview`。Wi-Fi/BLE 扫描命令 ACK 均为 0；后续扫描结束，网络列表 6 项、BLE 列表 12 项，服务错误码均为 0（BLE 列表容量为 12，不代表周边设备总数）。代码及真实鼠标事件回归证实减少动态分支漏掉置顶操作，详情页被连接页遮挡；继续点击入口可能重复扫描而收到忙回执。PC 修复后 8/8 检查通过，用户界面复测待反馈；不重刷板子。本次实际访问串口、发起扫描，但未复位、未修改配网凭据或烧录。

2026-09-20 v7 安装失败反馈（R17）：用户截图 `屏幕截图 2026-09-20 072803.png` 显示 `No module named 'esptool'`。本机确认工作台误用不含 esptool 的编译虚拟环境；失败发生在导入阶段，未进入 esptool 烧录调用，不能认定 USB/下载模式故障。启动环境及安装前检查已修复，本机验证通过；真实安装与 v7 联调仍待用户重试，保留本次失败历史。

|项目|记录|
|---|---|
|样机|用户手焊首板；独立样机编号尚未指定，当前记录针对本次同一块板|
|PCB|JXBadge_EVT_20260909_c7c59dff，已打板版本；未修改生产文件|
|PCB SHA-256|`c7c59dff5e6f2065a2157a81414d9d21c5cb1196a7b277656e15007753801a8d`|
|主控|实读 ESP32-S3 QFN56，revision v0.2；8 MB 内置 PSRAM（AP_3v3）|
|Flash|实读 16 MB，厂商 ID `ef`、器件 ID `4018`；诊断使用 DIO 40 MHz|
|晶振|esptool 实读 40 MHz；未用仪器测频偏|
|识别信息|主控 MAC `7c:4f:ad:1c:eb:0c`；Windows USB Serial/JTAG，COM3|
|工具|万用表、Windows 电脑、USB 数据线、手机热点与 BLE 调试应用；ESP-IDF 5.5.0、esptool 5.4.0|
|供电|早期 USB；随后用户反馈完成电池供电检查；无线串口测试在电脑 USB 连接条件下进行|
|无线测试距离|用户补充：手机“就在旁边”；属于近距离条件，未提供厘米/米数及固定朝向|
|屏幕状态|历史诊断黑屏后拔除；2026-09-21 用户报告新座已焊好，随后按屏幕诊断 r2 流程反馈“正常显示成功”。新座型号、照片及串口日志尚未提供；历史无线测试均不接屏|
|装料记录|用户报告全部焊接完成；R14/R15 使用 5.1 kΩ；充电芯片实装型号、电池具体规格及其余采购替代未形成完整核对表|

证据分为：**日志**（用户贴出的实际输出或已有日志文件）、**用户测量/观察反馈**、**本机代码检查**。只有“符合区间”的反馈保留原表述，不反推具体测量值。对话贴文仅在下文摘录关键行，不冒充完整连续日志。时间统一记本次测试日期；未提供的具体时刻不补写。

状态：“通过”仅针对该行测试范围；“初步通过”表示仍缺少完整测量；“未通过/阻塞”保留失败现象；“待测”表示没有足够证据。编译成功不等于实板通过。

## 2. 测试项目与当前结果

|编号|项目 / 条件与检查方法|实际结果与证据|状态 / 范围|
|---|---|---|---|
|P01|断电，新增焊点检查与 3V3—GND、BAT—GND 明显短路初筛|用户对整组检查回复“这几项都通过”；未提供逐点阻值或焊点检查照片|初步通过；不证明所有隐藏焊点质量|
|P02|USB 供电，VBUS 对 GND|参考约 5 V；用户反馈符合区间，未给出具体值|初步通过；直流输入检查|
|P03|USB 供电开机，3V3 对 GND|第四组明确反馈 3.3 V；全部焊接后再次确认在 3.20～3.40 V 区间|通过；已检查状态下直流电压|
|P04|电源开关、PWR/3V3 开关响应及供电路径检查|用户对前序相关电压检查反馈符合区间；未保存每个开关状态的数值|初步通过；下次需定量比较时补表|
|P05|断 USB、仅接电池的供电检查|按前序交接记录，用户反馈电池供电相关电压符合指导区间；未给出完整逐点值|初步通过；不包含无线峰值负载|
|U01|电脑 USB 枚举|识别 Espressif USB JTAG/serial debug unit，USB 串口 COM3|通过；当前电脑/数据线组合|
|U02|ROM 下载通信与芯片识别|`flash-id` 成功，识别 ESP32-S3、40 MHz、8 MB 内置 PSRAM、16 MB Flash|通过|
|U03|烧录并校验诊断固件|多次 bootloader、分区表和 application 写入后 `Hash of data verified`；headless r1 三段日志完整提供|通过；新无线版随后成功运行，但未单独保存其完整烧录输出|
|U04|RESET 后从 Flash 启动并运行|用户手动 RESET 后多版诊断启动、持续 ALIVE；早期自动复位后需手动 RESET 才取得日志|通过；不表示所有自动复位情形均已验证|
|M01|Flash 容量检查|`FLASH detected=16777216 bytes`|通过：16 MB|
|M02|专用 Flash 末尾 4 KB 擦除、写入、读回比较|`FLASH last-sector erase/write/read: PASS (ESP_OK)`|通过；不是整片 Flash 全地址/寿命测试|
|M03|PSRAM 容量及数据测试|8,388,608 bytes；三轮各 8,192,000 bytes 模式测试 PASS，启动 SRAM memory test OK|通过；未覆盖系统占用区域及所有运行频率|
|S01|SC7A20 I²C 配置与三轴原始数据|拔屏后 `ACCEL=CONFIGURED`；例如 x=1152、y=-1472、z=16400，随后持续输出变化数据|通过；基本通信与采样，未做六面校准/轴向/中断验证|
|S02|I²C 线路拔屏后恢复|此前 SCL=1、SDA=0；拔屏后 R15 两端均实测 3.28 V，加速度计恢复通信|通过：拔屏条件下基本线路恢复；接屏故障未解决；R23 视频已见基础触摸响应，接屏原始 I²C 电平/加速度计共存仍待测|
|B01|电池分压链路，GPIO8 / R36=200 kΩ、R37=100 kΩ|前序检查反馈符合区间；软件按 BAT/3 输入、三倍换算；没有逐点分压原始测量值|初步通过；由 B02 对整条采样链路进一步验证|
|B02|电池 ADC 初始化、校准、32 点平均及万用表对照|`BAT calibration=ESP_OK`；首轮 4005～4020 mV；用户确认“准确的我测过了，误差忽略”|通过：本次电压点的用户对表；未给精确误差，不宣称全量程精度|
|C01|关机、接电池和 USB 的初步充电电压检查|用户回复“也通过，符合电压区间”；未提供电流/电压随时间变化曲线|初步通过；不能据此确认实际充电电流及终止行为|
|W01|无屏 r1，被动扫描 2.4 GHz 热点|`found=12 showing=10`，最强 RSSI -54 dBm|通过；基本接收|
|W02|连接手机热点 Egger，WPA2，DHCP|频道 6、BW20；IP `10.11.180.139`，网关 `10.11.180.51`|通过；本次热点组合|
|W03|向热点网关发送 20 次 ping|`sent=20 received=20`，本轮丢包 0%；日志时延 3～169 ms|通过；局域网双向收发，不包含公网/吞吐量测试|
|W04|Wi-Fi 连接维持|后续持续 `WIFI LINK=UP`，包括 BLE 首次连接、断开及重连前后；所贴日志无重启|通过：已观察片段；无连续长稳测试证据|
|L01|BLE 广播|`BLE advertising name=JXBadge-Test status=0`，随后手机成功连接|通过|
|L02|BLE 首次连接|`BLE CONNECT status=0 (0=connected)`；随后 ALIVE 与 Wi-Fi LINK=UP 继续|通过|
|L03|BLE 断开与恢复广播|用户操作后 `BLE DISCONNECTED reason=531`，紧接广播 `status=0`|通过；原样保留原因码，不据此推断其他故障|
|L04|BLE 再次连接|sample 76 后再次 `BLE CONNECT status=0`，sample 77～79 继续 ALIVE/Wi-Fi LINK=UP|通过|
|L05|2026-09-20 当前用户层使用期间，nRF 发现设备|用户反馈“为什么nrf搜不到设备了”；未提供当时板端版本/读回。代码核查 UI v1 没有初始化 BLE，若运行 v1 即会没有 JXBadge-Test 广播；不能据此认定天线或焊接故障|保留历史失败；L06 截图已确认后续来访连接，发现/断开重连完整流程仍见 N13|
|L06|02:47 用户截图：新 UI 的 BLE 来访连接和扫描列表|显示“对方已连接本机”、地址 `7E:F3:BF:77:6F:3F`，附近列表可见“未命名设备”。来源：用户本轮截图 `屏幕截图 2026-09-20 024757.png`|来访连接及列表显示初步通过；对 L05 追加复测，尚无本版断开重连、主动连接和双角色并存证据|
|U05|02:47 用户截图：实板 USB UI 投屏|工作台 COM3 已连接，计数 320 帧，蓝牙页完整可读|初步通过：该时刻板端画面与状态显示；无帧率、连续时长或全部输入检查数据|
|U06|v7 USB 服务握手与状态读取|07:32 用户截图和本机 COM3 帧验证：BR_READY 硬件/协议匹配，状态报告 7.0.0-preview|通过：此轮握手及状态读取；未读回固件全量哈希，不扩展为全部联调通过|
|W05|v7 通过 USB 服务发起 Wi-Fi 扫描|请求 1001 ACK=0；后续 scanning=false、列表 6 项、error=0|通过：该轮扫描；未测试 v7 配网连接/密码/重连|
|L09|v7 通过 USB 服务发起 BLE 扫描|请求 1002 ACK=0；后续 scanning=false、列表 12 项、error=0|通过：该轮扫描；列表上限为 12，未测试 v7 双角色连接|
|X01|Wi-Fi 与 BLE 同时连接及断开重连期间共存|BLE 连接/重连后 Wi-Fi 保持 UP；电池采样 4026～4032 mV；所贴片段无异常重启|通过：基础连接共存；20 次 ping 在 BLE 首次连接前完成，不算双链路同时数据压测|
|D01|显示面板初始化及实际点亮|历史：r1 SPI 参数错误重启，r2 写入完成但仍黑屏。复测：2026-09-21 换座并收到 r2 操作步骤后，用户反馈“正常显示成功”；未提供照片、串口日志或烧录哈希|通过（用户反馈、基础显示范围）；未分别确认全部图案、色序/方向、刷新率或长期稳定性|
|D02|触摸识别、坐标与中断|历史接屏 SDA 被拉低，拔屏后恢复。2026-09-21 换座后视频可见手指拖动/点击使抽屉和壁纸页响应；无原始坐标/中断日志|基础触摸交互初步通过（视频）；方向、四角/边缘精度、松手、中断及接屏加速度计共存仍待专项测试|
|D03|实际背光点亮、PWM 调光/关断、R13 电流|历史屏幕未亮；2026-09-21 用户已确认显示可见，未单独提供亮度、自动关断或背光电流结果。r2 程序设定 5%/60 秒不作为实测值|显示可见已获反馈；PWM 调光/关断、R13 电流仍待测|
|D04|v7 实体屏动态刷新完整性|用户提供 15.267 秒/30fps 手机视频，抽屉转场有分段混合及重复标题；随后确认肉眼也可见。冻结 PCB 的 J1 TE 未连接，当前 16 行串行绘制/发送无扫描同步；详见 `outputs/lcd-tearing-analysis-20260921/分析.md`|R26用户观察复测通过：7.1.2撕裂/重复标题已消失；帧率仍低，R25完成FPS 3.42/10.42/9.88。非全场景长期无撕裂证明，面板扫描频率未测|
|D05|v7实屏动画帧率|R37板端7.3.6：壁纸51.31、抽屉23.97、名片20.74完成提交FPS；本轮7.3.5为28.38/24.34/20.40；静态0|动画16ms提升壁纸，main约94%；无线状态一致，用户报告缩略图撕裂，已回退7.3.5；见ANIM16_REPORT.md|
|T01|Windows 图形烧录助手的软件检查|四版固件文件/哈希、固定写入地址、凭据边界、模拟串口分段与释放、模拟烧录成功/失败、原生界面热点交互与密码遮蔽、打包 EXE 启动和 ESP32-S3 stub 加载均已检查|软件检查通过；未用新应用实际烧录板子，不能替代 U03 实板回归|
|T02|2026-09-20 原生 LVGL 用户层重设计与 USB 日志处理的软件检查|编译及 `ui_interaction`、`usb_telemetry` 两项通过，最终 2/2、23.08 秒；五页四向导航、模拟状态、电压/RSSI、亮度、减少动态、摇动、息屏唤醒、图片导入，以及日志解析、未知状态、只读输入与 GUI 日志回放绑定已检查。修正优化编译关闭断言的问题，改用始终执行的 CHECK 后重跑；截图复核电压 4.03 V、Wi-Fi -31 dBm 和 BLE 连接回放，修正大字下沿裁切。证据：`firmware/build/R6-LastTest.log`、`ui-review.png`、`usb-replay.png`（后两图同在 build）|软件检查通过；当次没有检测到真实串口，日志回放不等于实板 USB 端到端通过，后者单列 N10；LCD/触摸继续按 D01～D03 跟踪|
|T03|2026-09-20 板端 UI / USB 替代屏幕 / 图形 Wi-Fi 的软件检查|新增共用列表/密码页、ESP32 Wi-Fi 服务、RGB565 USB 显示与鼠标/键盘回传、原生 Windows 显示端。ESP-IDF 编译成功；CMake 三项回归通过；Python 两项检查通过；软件串口替身收到握手/像素，RGB565 红绿蓝及输入报文检查通过。最终发布哈希/打包检查见 `outputs/usb-screen-v1-20260920/software-validation.json`|仅软件验证；没有检测到真实串口，未烧录，投屏、配网、重启记忆均待 N11 实测；不新增硬件通过结论|
|T04|2026-09-20 烧录与 USB 屏幕整合的软件检查|三个 Python 检查通过（含真实 Tk 控件、显示线程退出后烧录、重复点击阻止、烧录时关闭保护、成功自动连接、失败保留日志且不连屏）；原烧录助手回归通过。打包 EXE 检查加载五版固件与 ESP32-S3 stub 7832 bytes，默认 UI 固件与自动连屏开关正确，证据 `outputs/usb-screen-viewer/JXBadgeUSBScreen/integration-validation.json`；新增测试日志 `firmware/build/usb-screen-integrated-tests.log`|软件检查通过；本轮端口枚举识别 COM3，但没有打开串口或实际烧录。板端固件未修改，首次集成实测见 N12|
|T05|2026-09-20 UI v2 蓝牙双角色与息屏摇晃的软件检查|ESP-IDF 构建成功，启用 NimBLE peripheral/central/observer、两连接及 Wi-Fi 共存。四项 CTest 通过，覆盖 BLE 列表扫描/连接/两类断开/开关/拒绝仅广播设备、亮屏摇晃无页面和像素变化、息屏摇晃恢复原画面；独立检测检查静置、短促单次变化、有效两次变化、超时和清空状态。三个 Python 工作台检查通过。发布证据：`outputs/usb-screen-v2-20260920/software-validation.json`|仅软件检查；真实传感器阈值、BLE 双角色与 UI 投屏运行仍待 N11～N14；本轮未打开串口或烧录|
|T06|2026-09-20 NBTCA Badge TOOL 重构与 UI v3 壁纸上传|原生三页工作台，减少常驻说明、圆形屏幕显示、折叠安装日志；USB 应答上传、手机浏览器裁剪上传、独立 Flash 双槽存储、授权上传码、手动 WPA2 热点。验证产物见 `outputs/usb-screen-v3-20260920/software-validation.json`，包含 CTest 五项、Python 六项、Edge 手机视口、真实原生窗口截图、打包应用加载检查|软件验证，v3 未烧录；浏览器请求对本地 HTTP 替身、Flash 对内存替身，不冒充板端传输/掉电实测|
|T07|CABadge 无线 P0 v4 软件检查|ESP32/Windows 构建；管理协议窗口/参数；直接包含生产管理与 HTTP 服务的宿主检查（认证、撤销、过期、命令队列、长度/CRC、互斥、取消、失败回退）；手机浏览器状态与控制、恶意名称文本化、USB 和既有 UI 回归。原始结果见 `outputs/usb-screen-v4-20260920/software-validation.json`|仅软件；ESP I/O、任务与 Flash 在宿主检查中被替代，BLE ATT 栈/无线并发/手机上板链路未实测|
|T09|CABadge v7 核心预览与 USB 服务桥软件检查|Windows/ESP32 构建、8/8 CTest、原生工作台启动/关闭、固件清单校验、实际 LVGL 动效；证据 `outputs/cabadge-v7-preview-20260920/software-validation.json`|软件通过；命名管道和宿主 I/O 是软件替身，v7 实板 N18 待测；未扩大旧版实测结论|
|T10|v7 烧录运行环境修复|用户首次安装报缺少 esptool；修正启动器环境，新增 esptool/ESP32-S3 stub 检查、缺依赖拒绝及模拟烧录调用回归；证据 `outputs/cabadge-v7-preview-20260920/flasher-runtime-validation.json`|本机软件复测通过；未打开串口或烧录，实际安装待重试。T09 当时只检查固件清单，未覆盖此运行依赖|
|T12|v7.1 动效与性能诊断的软件验证|Liquid 反向/减少动态、Slosh 固定亮度、Notify 回执、三场景渲染、统计百分位、浏览器原地确认/取消/选中底板；串口替身验证完整采样/取消保留旧校准；证据 `outputs/cabadge-v7-motion-perf-20260920/software-validation.json`|软件通过；本轮未烧录新版、未取得 MCU 或 LCD 性能实测|
|T13|v7.1.1 实体屏适配软件检查|QSPI 40 MHz；r2 初始化表复用；16 行 DMA 中转与 RGB565 字节序；共享 I2C 触摸和加速度计；9/9 CTest、传输错误/触摸边界/背光上限主机检查、原烧录预检/本地控制/采样协议检查通过；证据 `outputs/cabadge-v7-lcd-20260921/software-validation.json`|软件通过；未烧录，本版实体显示/触摸/40 MHz 稳定性待测|
|T14|7.1.2刷新修复软件检查|全帧/40MHz连续DMA；9/9 CTest；延迟DMA读取验证缓冲生命周期、字节序、窗口/CS、失败排空关灯；实体采样/校准隔离、烧录预检、工作台烟测；证据 `outputs/cabadge-v7-lcd-refresh-20260921/software-validation.json`|软件通过；未访问COM或烧录|
|T15|7.1.3绘制优化软件验证|-O2编译选项、RGB565/RAM壁纸和缩略图/名片缓存；10/10 CTest，源替换/恢复/缓存失败回退、连续DMA、采样/烧录预检和工作台烟测；证据 `outputs/cabadge-v7-render-fast-20260921/software-validation.json`|软件通过；PC耗时对照非实板FPS，未自动烧录|
|T11|减少动态模式下的详情页层级修复|新增真实鼠标点击 Wi-Fi、BLE、手机管理入口及返回回归；修复前失败，修复后 8/8 CTest 通过；证据 `outputs/cabadge-v7-pc-panel-fix-20260920`|PC 软件通过，用户界面复测待反馈；ESP32 发布 BIN 保持原版，不将源码修改冒充板端更新|

## 3. 关键证据摘录与时间顺序

以下摘自用户本次对话日志，省略中间行；以此保留判定依据，不保存热点密码。

### 3.1 主控及存储

```text
Chip type: ESP32-S3 (QFN56) (revision v0.2)
Crystal frequency: 40MHz
USB mode: USB-Serial/JTAG
Manufacturer: ef
Device: 4018
Detected flash size: 16MB

FLASH detected=16777216 bytes, expected=16777216
FLASH last-sector erase/write/read: PASS (ESP_OK)
PSRAM detected=8388608 bytes, expected=8388608
PSRAM pattern 1: PASS (8192000 bytes)
PSRAM pattern 2: PASS (8192000 bytes)
PSRAM pattern 3: PASS (8192000 bytes)
RESULT: PASS | FLASH=PASS PSRAM=PASS
```

早期原始持续运行日志：serial-reset-check.log（本地历史资料，未入库：`outputs/bringup-20260919/serial-reset-check.log`）。对应本机验证记录给出的连续观察时间为 125 秒；不要扩大成长期稳定结论。

### 3.2 显示异常与拔屏后的传感器恢复

```text
STAGE4 r2: QSPI 10MHz; I2C 100kHz; charge/radio OFF.
I2C idle before driver: SCL=1 SDA=0 (both should be 1; external pull-ups only)
I2C line LOW: skip touch/accelerometer transactions; LCD test will continue.
LCD writes completed (not proof of visible display). BL=5% for 60s, then OFF.
```

用户观察：“没亮保持黑屏”；拔屏后 R15 两边均为 3.28 V。随后日志：

```text
ACCEL raw x=1152 y=-1472 z=16400
STAGE4 +13s | BL=5% TOUCH=NOT_DETECTED ACCEL=CONFIGURED touch_errors=0
```

### 3.3 无屏 ADC 与 Wi-Fi 扫描

```text
BAT calibration=ESP_OK; GPIO8; divider=3; compare with BAT-to-GND meter
BAT init=ESP_OK
WIFI scan OK: found=12 showing=10
WIFI result=ESP_OK; RESET repeats scan
BAT sample=1 raw=2981 voltage=4020 mV (battery must be connected)
BAT sample=7 raw=2973 voltage=4005 mV (battery must be connected)
```

用户对表结论：“准确的我测过了，误差忽略”。因此保留 `BATTERY_GAIN=1.0`；不填写未提供的万用表具体值或百分比误差。

### 3.4 Wi-Fi 收发

```text
WIFI CONNECTED IP=10.11.180.139 GATEWAY=10.11.180.51
PING reply seq=1 time=21 ms
PING reply seq=20 time=169 ms
PING SUMMARY sent=20 received=20; no replies alone do not prove a hardware fault
HEADLESS ALIVE sample=5 | BL=OFF CHG_ALLOW=LOW
WIFI LINK=UP RSSI=-35 dBm
```

日志中的密码长度/WPA2 阈值提示后已成功连接，没有据此认定认证故障。射频校准数据首次加载提示后已执行完整校准并保存，后续扫描/连接成功。

### 3.5 BLE 与共存

```text
HEADLESS ALIVE sample=53 | BL=OFF CHG_ALLOW=LOW
WIFI LINK=UP RSSI=-31 dBm
BLE CONNECT status=0 (0=connected)
HEADLESS ALIVE sample=54 | BL=OFF CHG_ALLOW=LOW
WIFI LINK=UP RSSI=-31 dBm

BLE DISCONNECTED reason=531
BLE advertising name=JXBadge-Test status=0 (0=OK)
HEADLESS ALIVE sample=69 | BL=OFF CHG_ALLOW=LOW
WIFI LINK=UP RSSI=-37 dBm

HEADLESS ALIVE sample=76 | BL=OFF CHG_ALLOW=LOW
WIFI LINK=UP RSSI=-33 dBm
BLE CONNECT status=0 (0=connected)
HEADLESS ALIVE sample=77 | BL=OFF CHG_ALLOW=LOW
WIFI LINK=UP RSSI=-32 dBm
BAT sample=79 raw=2986 voltage=4026 mV (battery must be connected)
HEADLESS ALIVE sample=79 | BL=OFF CHG_ALLOW=LOW
WIFI LINK=UP RSSI=-40 dBm
```

### 3.6 根据现有结果评估天线效果（2026-09-19）

**判定：手机就在板子旁边的近距离无线通信初筛通过；天线效率、匹配与有效距离尚不能定级。** 本节为已有数据的分析及用户补充的测试条件，不是新增距离测试。

|已有证据|支持的判断|不能由此推出|
|---|---|---|
|手机热点连接期间 RSSI 约 -27～-44 dBm；用户确认手机就在旁边|该近距离条件下收到的热点信号较强|未定量测距，也无固定方向、遮挡和对照板信息；不能由强信号判定天线高效率或匹配合格|
|20 次 ping 全回复，3～169 ms|该位置和条件下已完成 Wi-Fi 双向通信|样本少，不能证明远距离、低丢包长期通信；单次较大延迟也不能单独归因天线|
|扫描见 12 个热点，显示列表约 -54～-90 dBm|接收链路能够发现多个强弱不同的热点|不同热点的距离/发射功率未知，-90 dBm 扫描条目不等于该强度下可稳定连接，也不是灵敏度测量|
|BLE 能连接、断开重连，Wi-Fi 保持连接|BLE 基本通信与连接共存工作|没有 BLE RSSI、固定距离或数据流量记录，不能评定 BLE 覆盖能力|

用户随后明确补充手机“就在旁边”，因此本轮按近距离通信结果解释；具体距离和朝向仍未测量。手机很近时，即使天线系统存在较大损耗，也可能正常连接，故现有结果不足以排除匹配或效率问题；同样也没有证据表明天线性能差。屏幕尚未装回，电池最终安装位置和外壳/佩戴状态也未形成可复现条件；当前结果不能代表最终装配射频性能。强信号下可连接不能代替天线馈点、焊接和匹配测量，不能断言天线匹配已最优。

建议维持现有匹配元件，先补可复现对比：同一热点/频道，记录约 1 m、3 m、5 m 无遮挡位置；每个位置固定朝向后采集 RSSI，并以更多 ping 样本观察丢包/断连。现版仅启动时发送 20 次 ping，若做连续距离测试需先改为重复/持续发送，不可把后续 LINK=UP 当作持续 ping 通过。再比较板子四个方向、装屏装电池前后与实际佩戴状态；若有已知正常的同芯片开发板，可同位置同配置对照。该距离列表仅是建议测试点，不是已验证覆盖范围或产品指标。

如需量化匹配/效率，应分别做正确参考面的天线端口 S11/阻抗测量及辐射性能测试；S11 好也不能单独证明效率高。乐鑫说明射频匹配参数随板级设计变化，并建议结合实际测试验证天线：[原理图射频检查](https://docs.espressif.com/projects/esp-hardware-design-guidelines/en/latest/esp32s3/schematic-checklist.html)、[射频布局与天线验证](https://docs.espressif.com/projects/esp-hardware-design-guidelines/en/latest/esp32s3/pcb-layout-design.html)。

## 4. 问题追踪

|问题|发现与处理|目前状态 / 关闭条件|
|---|---|---|
|F01 LCD 命令触发软件 abort|display r1 对零长度命令仍给非空 tx_buffer，触发 ESP_ERR_INVALID_ARG；r2 在共享 lcd_tx 中修正。实际 C 传输回归覆盖 192 条命令、其中 3 条无数据命令及像素发送；后续实板已进入持续图案循环|软件故障已修复并复测；不代表屏幕已点亮|
|F02 屏幕黑屏、接屏 SDA=0|原 BOM 座子 FPC-05F-18PH20 下接触；用户确认金手指朝 PCB 插入。前序照片/脚序核对指出该装配姿态下脚序反向，板 SDA16 对屏 GND3，与拔屏后恢复的现象吻合。用户此前选购替换上接触座子；2026-09-21 报告座子已焊接完成，实际型号/装配照片未提供。随后用户反馈“正常显示成功”|黑屏子项按换座后用户复测恢复；SDA 低/触摸异常子项仍待日志与触摸复测，不将整条显示/触摸链路判为全部修复；R23 视频已见基础触摸响应，接屏原始 I²C 电平/加速度计共存仍待测|
|F03 早期接屏时触摸和加速度计 I²C 失败|接屏时总线异常；拔屏后上拉读数恢复，加速度计配置及数据恢复|传感器在拔屏条件下恢复；接屏总线问题仍归 F02，不能称整条显示/触摸链路修复；R23 视频已见基础触摸响应，接屏原始 I²C 电平/加速度计共存仍待测|
|F04 v7 实屏撕裂/重复标题|R23 视频及用户肉眼确认；手册 TE 同步机制、冻结 PCB TE 悬空和当前分块同步发送共同支持刷新不同步的判断；软件能先改善完整帧提交/传输间隙|R26按用户反馈已恢复：7.1.2撕裂/重复标题消失，历史失败保留；TE仍未接，不扩大为任意负载长期无撕裂保证。低帧率继续优化|
|F07 Article 动态画面撕裂|用户反馈滑动时上下画面错位、停下恢复；对话推定8.0.0 Article，无板端版本读回。源码为双10行PARTIAL缓冲，逐块立即发送，TE未接|失败待复测；8.0.1恢复整帧合成/连续DMA的候选，未烧录，不能写成已修复通过|
|F08 v7动画16ms壁纸缩略图撕裂|7.3.6已读回；用户直接反馈“壁纸页面壁纸缩略图有略微撕裂”。约51FPS提交率不等于无撕裂视觉帧；TE未接下扫描/写入不同步是待验证解释，无波形证据|本版验收失败，已烧录/校验/读回7.3.5；撤销动画16ms，保留显示16ms。回退后目视恢复待确认|
|F11 ESP-IDF6.1首轮黑屏|7.4.0-idf61编译、烧录与USB握手正常，但用户确认只有背光，没有图像|已恢复7.3.10，用户确认图像恢复。6.1兼容性排查中，候选未验收|
|F09 v7手机Web管理页面无法加载|7.3.5版本已读回；用户截图微信浏览器访问10.11.180.139停在空白加载页。USB确认Wi-Fi连接/IP正确、http=true、httpd任务存在；内部RAM历史最低283B、DMA最低279B，资源不足为重点嫌疑。首页无需授权，授权过期不能单独解释首页空白|未修复，系统浏览器复测待回复；PC在其他子网，HTTP连接超时不能据此定位手机链路。先处理/验证内存余量，再继续双绘图任务实验|
|F10 7.3.9一次USB采样超时|runtime-20260923-101659在前6场景后packet41→42超时，恢复命令也超时；随后新握手成功，未证明重启或根因|7.3.9整轮重测及7.3.10全部13场景通过；保留失败原始日志，长期与根因待核实|

### T08：CABadge v5 圆屏 UI 软件检查

共用 LVGL/SDL2 构建与 ESP32-S3 固件构建；7 项 CTest（新菜单/返回、左右换壁纸、浏览/应用/启动恢复、状态浮层到期、滑条隔离、无线/管理和既有协议/存储检查）；6 项 Python 原生窗口/输入/烧录交接/上传与真实浏览器替身检查；打包 EXE 离线启动。最终原始日志与哈希见 `outputs/usb-screen-v5-20260920/software-validation.json`。实际共用 UI 渲染截图见 `outputs/ui-v5-20260920`，设计说明见 `firmware/UI_DESIGN_V5.md`。

这些是本机软件检查，测试中的无线/电压为模拟输入或日志回放，HTTP/Flash 宿主替身不能证明实板行为。未访问串口或烧录；新版本实板状态仍为 N17 待测。

### T09：CABadge v7 核心预览软件检查

- 版本 `7.0.0-preview`，独立 `firmware-v7`；原工程 52 个基线文件哈希保持相同。
- 软件：CMake/ESP-IDF 构建成功，8/8 CTest。覆盖固定按钮 R176/44px、静态字库、真实鼠标手势、Carousel 预览/应用、唤醒不跳页、减少动态；Windows 命名管道运行生产异步 USB 客户端的分片握手/请求/失败回执/版本拒绝；既有协议、双槽与生产管理服务宿主回归。新增资源读回的 generation、范围、内容与 BLE 7/0 字段检查通过。
- 连续整屏 PC 刷新：30 FPS/40 MHz 候选预算档 29.31 FPS；10 MHz 保守档 18.66 FPS。本机测量，不是 MCU 渲染或实体 LCD 刷新。MCU 渲染附加耗时默认未校准。
- 链接期静态 RAM 98056 B，应用统计 3893497 B / 7340032 B。不是运行时 RAM/PSRAM 峰值。
- 工作台预览启动/关闭与固件文件/哈希/分区检查通过；只做端口枚举，未打开 COM3、未烧录。记录与录像见 发布目录（本地历史资料，未入库：`outputs/cabadge-v7-preview-20260920`）。
- 手机 Web 视觉、动态中文完整覆盖、二维码实扫和所有 v7 新实板链路待后续；不以此宣布完整 v7 或整机测试通过。

## 5. 待测项目与下一步

|编号|待测项目|完成时应留下的证据|
|---|---|---|
|N01|换 FPC 座子后复核连接|实际座子型号/照片、接触面、屏/板 1～18 脚对应及断电连通检查；随后记录接屏 SCL/SDA 状态|
|N02|显示、背光、触摸|部分通过：换座后基础显示及视频中的触摸交互可用；动画撕裂失败归 D04/F04。图案细节、PWM 关断、背光电流和触摸专项仍待测|
|N03|完整充电过程|实装芯片与电池条件、起始 BAT、实际充电电流、过程温升、满充/终止、开关机充电允许状态；约 300 mA 是设计目标而非当前实测|
|N04|纯电池无线负载及供电切换|无 USB 时无线连接/通信证据与 3V3；USB 插拔是否复位；先提供无需 USB 串口输入即可配置/观测的测试方式，不能直接拔线丢日志后声称通过|
|N05|BLE 服务读写/数据传输（基本读写通过）|R14：用户反馈自定义 Session 授权、Status 读取/通知、Control 息屏/唤醒/预览亮度及重连撤销授权正常，详见 N16。未提供原始 ATT 数据/吞吐量；Device Name 特征读取与持续传输未单独验证|
|N06|无线持续运行与并发数据|明确起止时间、连续日志、断连/重启次数，Wi-Fi ping/流量与 BLE 数据交换时间重叠；既有日志覆盖连接共存，R14 用户反馈在保持 Wi-Fi 连接的操作条件下 BLE 基本读写正常，仍无同时数据流或长期运行证据|
|N07|最终装屏装电池后的射频表现|相同距离/方向下信号、收发/丢包与必要的天线匹配测试；当前近距离结果不代表整机装配后的射频性能|
|N08|其他功能与电源性能|加速度计轴向/中断、充电指示灯等实际行为；待具备工具再测纹波、瞬态、峰值电流及温升，不能用万用表直流读数代替|
|N09|图形烧录助手首次实板使用|应用选择实际串口并烧录后的校验日志、自动打开串口、RESET 启动与热点输入结果；此前 CLI 烧录成功不算新 UI 全流程验证|
|N10|USB 实板日志驱动电脑用户层的端到端验证|复用板上现有无线诊断固件，不新增烧录；烧录助手完成热点输入并等到 Wi-Fi 已连接，关闭串口后模拟器接管同一端口，期间不按 RESET；记录实际串口、BAT/Wi-Fi/RSSI 对照、手机 BLE 断开重连事件、15 秒无更新标记及 USB 断线/重连清状态；未收到 BLE 新事件时等待状态正常。当前仅列待测，T02 回放不能替代|
|N11|ESP32 运行共用 UI，电脑替代屏幕；图形 Wi-Fi 配网|最初发布 v1，目前使用 NBTCA Badge TOOL 和 v4。记录完整画面、点击/滑动、实际网络列表、密码错误提示、正确密码后已连接、RESET/断电重启后自动连接、USB 断线重连。蓝色已连接项必须来自实际 DHCP 成功。U05 已提供旧 UI 投屏截图，其余图形配网/断电记忆和 v3 回归仍待实测|
|N12|整合工作台首次实板烧录与投屏交接|打开同一个 `JXBadge USB屏幕.lnk`，选择实际串口，在“固件烧录”页默认 UI 固件点击烧录，记录校验日志、成功后自动连接结果、板端画面与输入。若需要手动 RESET，记录现象；不将软件串口替身检查作为通过。N11 的图形配网/断电记忆继续在此新入口完成|
|N13|新 UI 双角色 BLE、nRF 发现与共存复测|L06 已有来访连接和附近列表显示的截图；继续测试 nRF 发现、断开重连，以及徽章主动连接外设、主动断开、关闭开关断开两类连接、恢复广播、一条来访与一条主动连接并存以及 Wi-Fi 同时保持。记录外设型号和错误，不以仅广播设备无法连接判断故障；其余及 v3 回归待测|
|N14|SC7A20 息屏摇晃唤醒|亮屏时摇晃应保持原页面和图片；点息屏后静置不应误唤醒，摇晃应恢复原页面/图片。先用工作台“模拟摇晃”验证 UI，再摇实物验证传感器链路，分别记录。阈值和两次变化时间窗尚未经实物调校；本版只是 UI 息屏，实际 LCD/背光仍关闭；当前待测|
|N15|NBTCA Badge TOOL / UI v3 壁纸与新工作台回归|新入口 `NBTCA Badge TOOL.lnk` 安装“日常固件 v3 · 壁纸”；USB 选图、裁剪、上传并应用，断电重启检查保留。取消/拔线后确认旧有效壁纸可用；恢复默认后再断电确认。手机同网扫码上传，再开启直连热点、手机连接后扫码上传；测试错误/过期上传码及同时请求。关闭 Wi-Fi 确认热点停止；回归投屏输入、Wi-Fi/BLE、息屏摇晃。记录每种传输成功/失败、耗时与固件哈希；当前均待实板验证|
|N16|CABadge 无线 P0 v4 上板联调（部分通过）|R12：v4 安装/USB 投屏、手机管理页、上传显示、完全断电后保留。R13：Web 电压/Wi-Fi 状态、息屏唤醒/壁纸保留、预览亮度、主动关闭管理后拒绝及新入口恢复。R14：nRF 未授权读取拒绝、Session 后 Status 20 字节读取/通知、Control 息屏/唤醒/50% 预览亮度、重连须重新授权；在保持 Wi-Fi 连接条件下操作。以上均为各轮四步整体反馈“正常”，无逐项日志/截图/板端哈希，网络路径未注明。剩余待测：错误授权码/自然过期拒绝、USB/HTTP 互斥、两种网络路径分别覆盖、Wi-Fi/BLE 关断/并发负载、旧 UI/摇晃回归|
|N17|CABadge v5 圆屏 UI 回归|新版烧录/投屏、上滑菜单和返回、左右切换/浏览后应用、内置与上传壁纸选择后完全断电恢复、从 v4 升级保留上传壁纸、Wi-Fi/BLE 状态及 Web/USB 上传/控制回归、亮度/减少动态/息屏摇晃。软件 T08 不代替上板；当前全部待测，N16 未完成的授权自然到期/错误码、异常与无线负载项目继续保留|
|N19|7.1.0-preview 实板无屏性能采样及新动效复测|待测：安装新版后通过工作台采集 Carousel/抽屉/蓝色名片，核查样本完整性、取消/断连恢复及校准档；实屏仍断开。此前 7.0.0 的扫描成绩不扩大为新版通过|
|N20|7.1.1-lcd 40 MHz 实屏联调|部分通过/存在失败：视频显示壁纸、抽屉及壁纸页能响应触摸，用户确认肉眼撕裂、同标题频繁重复；无固件哈希/实际时钟或 FPS 测量。F04 待修复复测；无线并行、息屏关灯/摇晃、触摸精度、LED 电流仍待测|
|N21|7.1.2-lcd刷新修复复测|部分通过：三场景采样完成，R26用户确认撕裂与重复标题消失，主要剩帧率低；完成FPS 3.42/10.42/9.88，30FPS目标未达。触摸专项/息屏等仍待测|
|N23|7.2.3日常任务与实体FPS复测|R32：13场景实板采样完成，静态及HUD静态均0；Wi-Fi/BLE扫描有列表、error=0，广播正常。FPS开关软件回归通过、板端已开启；实体目视、手机连接/上传和长期稳定仍待复测。每秒抽样内部最低11803 B，启动以来多堆最低汇总3179 B，峰值余量紧|
|N22|7.1.3-lcd绘制优化复测|部分通过：R28三场景实体采样完整，FPS为6.59/11.15/12.56，确认性能有所改善；30FPS未达。新版撕裂是否复发、触摸、外观、上传/默认恢复及长期稳定仍待观察|
|N18|CABadge v7 Preview 实板联调|部分通过：U06 握手/状态、W05 Wi-Fi 扫描、L09 BLE 扫描。详情页遮挡已修 PC、待用户复测；配网密码、BLE 双角色、摇晃、壁纸同步/保存/重启、错误与过期、可靠断连重连等仍待测。真实 LCD/触摸/背光及 MCU 渲染时延仍未验证|

N18 安装尝试历史（R17）：首次尝试被 PC 端 `esptool` 缺失阻塞，未进入烧录调用；启动器和环境检查已修复，等待用户重新打开工作台后重试。不得以本机 T10 通过提前标记实板安装成功。

当前入口为 NBTCA Badge TOOL，最新预设 CABadge v5 · 圆屏界面；N11～N17 延续验证。R12～R14 记录 v4 用户反馈，U05/L06 只覆盖截图当时的投屏/来访连接范围。N10 保留历史定义，旧串口手输流程不再作为操作入口。连接器到达后继续 N01；相关固件改动需要回归，保留旧结果。

2026-09-20 用户提出先以 USB 连接实板、在电脑模拟用户层。本轮为原生 LVGL/SDL2 模拟器增加只读诊断日志入口，界面和鼠标触摸在电脑运行；亮度、息屏与图片仍仅供电脑预览。未编写或烧录新板端固件，未新增实板测量结果。当前无线诊断固件等待热点输入时尚未进入持续遥测，复用烧录助手的“仅打开串口 / 发送热点信息 / 关闭串口”完成交接；两应用不能同时打开 COM3，不要求 RESET。桌面验证归 T02，真实 USB 链路归 N10，均须取得对应证据后更新状态。

2026-09-20 后续纠正：用户要求板端运行 UI、电脑只替代显示和触摸，并要求手机式图形 Wi-Fi 配置。本轮已编译新固件并打包独立电脑显示端；Wi-Fi 扫描、连接及成功配置保存由板端执行。没有检测到真实串口，未烧录、未新增硬件实测。软件验证归 T03、实际验证归 N11；旧 N10 流程不再作为当前入口。新固件不启动 BLE，保持背光/充电允许 LOW，不驱动实际屏幕。

### 2026-09-21 14:48 实体屏性能采样（R25）

用户反馈“采样完了”，读取工作台保存的 原始 JSON（本地历史资料，未入库：`outputs/performance/20260921-144846-577025.json`），采集时间 `2026-09-21T14:48:46.576747+08:00`。设备报告 `7.1.2-lcd`、PCB `c7c59dff`、`lcd_transfer=true`，三个场景顺序及结束标志完整；协议校验、帧数字节量一致性检查通过。由用户操作设备采样，本轮助手只读文件，未打开串口或烧录；版本为设备报告，未做Flash哈希读回。

|场景|采样时长|完成帧数 / FPS|绘制 P50 / P95|flush P95|整帧 P95|最大完成帧间隔|
|---|---|---|---|---|---|---|
|Carousel|4093 ms|14 / 3.42|252.977 / 260.892 ms|14.862 ms|275.651 ms|295 ms|
|上下抽屉|4029 ms|42 / 10.42|42.941 / 88.372 ms|14.649 ms|102.978 ms|242 ms|
|蓝色名片|4050 ms|40 / 9.88|59.261 / 108.628 ms|14.624 ms|123.080 ms|159 ms|

全部刷新为259200字节整帧。字节序拷贝P95分别12.311/12.077/12.057ms，已包含于flush并与另一缓冲DMA重叠，不能再加到flush上。CPU/QSPI配置报告240/40MHz，不是示波器测频。

结论：本次场景中绘制墙钟耗时显著高于传屏，尤其Carousel；当前动画更新未达到30FPS目标，下一步应定位并优化绘制热点，而非仅提高QSPI。渲染计时包含线程调度干扰，不能据此认定某一个缩放/透明函数已被单独测定；整帧合成的性能代价需要继续评估。SPI完成FPS不是面板扫描Hz；没有旧版相同采样对照，也不能由新数据定量宣称相对7.1.1提速。TE未连接，是否还撕裂/重复标题仍待用户观察；F04保持未闭环。

每场景结束状态：Wi-Fi开启但未连接、BLE关闭，无线并发负载没有覆盖。完成帧采样点内部最少空闲31355B（约30.6KiB）、PSRAM最少7860440B（约7.50MiB）；不是瞬时峰值，也不能据此判内存已不足。三个场景采样流程通过，N21更新为部分通过，图像质量/触摸/息屏等仍待复测。

原JSON SHA-256：`81d47886f8ba609eaa01084ff2c50fe73012f4a0b16338fde76bd38588f2338d`。不修改原始采样、历史发布verification.json或PC无屏校准。

### 2026-09-21 15:06 7.1.3实体采样与7.1.2对比（R28）

用户反馈“采好了”。读取 7.1.3原始JSON（本地历史资料，未入库：`outputs/performance/20260921-150631-457426.json`），采集时间15:06:31；设备报告7.1.3-lcd/c7c59dff、lcd_transfer=true。三个场景与结束标志、帧数字节一致性均通过；对比 7.1.2基线（本地历史资料，未入库：`outputs/performance/20260921-144846-577025.json`）。本轮助手仅读文件，未打开COM或烧录；版本由设备报告，未做Flash哈希读回。

|场景|7.1.2 FPS|7.1.3 FPS|本次相对提升|绘制P95：旧→新|新版flush P95|新版整帧P95|新版最大完成间隔|
|---|---|---|---|---|---|---|---|
|Carousel|3.42|6.59|92.7%|260.892→143.220 ms|14.510 ms|157.691 ms|259 ms|
|上下抽屉|10.42|11.15|7.0%|88.372→82.176 ms|14.597 ms|96.729 ms|229 ms|
|蓝色名片|9.88|12.56|27.1%|108.628→57.584 ms|14.467 ms|71.995 ms|143 ms|

新版各场景27/45/51帧，采样4097/4036/4062ms；绘制P50为108.934/43.742/55.522ms。每帧259200B。copy P95为10.571/10.636/10.430ms，属于flush内部、可与DMA重叠，不重复相加。

两次记录中CPU/QSPI配置均240/40MHz，各场景结束状态均Wi-Fi开启但未连接、BLE关闭。比较条件在已记录字段上相同；并非多次统计实验，也不能证明每次动画相位、环境干扰和无线状态全程完全一致。FPS为SPI整帧提交率，包含脚本停顿，不是面板扫描Hz。

结果：Carousel本次接近翻倍，名片改善，抽屉改善有限；三项都未达到30FPS目标，不将其称为已经流畅或优化完成。绘制仍明显慢于约14.5ms传输；后续应对实际绘制任务分项计时，再确定剩余缩放/混合/重复绘制/内存访问占比，不能仅凭总耗时断言单一根因。

新版最低观测内部空闲39047B（约38.1KiB）、PSRAM6680768B（约6.37MiB）；旧版相应31355B/7860440B，PSRAM多使用1179672B，符合新增缓存量级，但不是峰值分配证明。没有无线并发负载覆盖。

N22更新部分通过：实屏采样与性能改善获得数据支持；新版外观、触摸、上传后缓存正确性、长期稳定和撕裂是否复发仍待观察。R26“撕裂已消失”是7.1.2用户反馈，不自动扩大到7.1.3。

补充屏幕刷新能力核对：全志官方 [V821显示模组验证列表](https://docs.aw-ol.com/docs/soc/v821/hardware/support_list/) 将同型号W180TE010I-18Z（360×360 RGB565、QSPI、ST77916）列为60Hz，这是同型号在另一平台的正常刷新验证，不是本板实测，更不是厂家保证的绝对最高频率。当前厂商初始化C0=0x80/C1=0x10/C2=0x37；依ST77916手册p238公式，若取Y_Res=360、BPFPA=16、RTNA=55、tcon_clk=400ns，推算约60.44Hz；内部时钟条件未经本板测量，不能写成实测值。控制器表格列出更高数值不代表该玻璃模组允许超规格刷新。当前LVGL默认33ms调度约30次/秒为软件设定，屏幕60Hz和QSPI40MHz也不能代替实测UI FPS。

原文件SHA-256：`2f251997484145baf6296682562a14f00e915f8d699f743c3614b16b1269b4bd`。不改原始采样、历史发布verification.json或PC校准。

### 2026-09-21 LCD 性能专项，基线与新回归（R29，进行中）

- COM3 实读 7.1.3：`outputs/performance/20260921-151826-153443.json`，Carousel/抽屉/名片为 6.46/11.16/12.52 FPS，绘制 P95 143.725/82.284/58.095 ms，Flush P95 14.537/14.588/14.467 ms。
- 已实际烧录纯计时 7.1.4-profile，仅写应用 0x10000，esptool 哈希校验通过；分区、NVS、壁纸分区未重写。`outputs/performance/20260921-152831-450351.json` 六场景采样成功；静态壁纸预热后零重绘，动画 DMA 回调区间约 13.013 ms。第六场景扫描返回 MG_FAILED，扫描时间为零，不能算 Wi-Fi 扫描负载通过。
- 用户授权删除旧 USB 像素投屏，7.1.5-usb 已烧录和采样：`outputs/performance/20260921-153206-174527.json`。静态 RAM 104732→96516 B，减少 8216 B。两轮 BLE 状态不同（前轮未启用、后轮广播启用），不能直接归因 FPS 或运行堆变化。此时内部空闲内存最低仅 1411 B，需先解决无线内存问题。
- 用户配合实体触摸，`outputs/performance/20260921-153401-832857.json`：约8秒，29个输入变化样本，输入读取至下一次LCD提交完成 P95 186.987 ms。不是光学端到端触摸延迟，不包含触摸控制器扫描与面板扫描。
- 用户补充上一固件蓝牙无法使用，照片显示“蓝牙初始化失败，请重启”。记录为新增功能回归 F05；照片没有版本号，不能精确锁定到某次发布。内部 RAM 不足为待验证根因；正在构建无线主机内存迁移版本，尚不能判修复通过。
- 当前仍为单PSRAM整帧LVGL缓冲、内部双32行DMA缓冲、QSPI实际分频API读回40MHz、RGB565；TE未接，`completed_fps`仅统计SPI更新完成率，非面板扫描Hz。旧像素USB链路删除不影响实体屏输出、原生PC LVGL服务、烧录及壁纸USB上传。

### 2026-09-21 内存配置试验失败与回退（R30）

- 7.1.6-memory 同时启用 ESP-IDF 的 NimBLE 外部 PSRAM 分配及 Wi-Fi/LwIP 优先 PSRAM 分配。应用写入、哈希校验成功，但 USB 业务握手无响应并发生写超时，用户报告屏幕不显示。记录 F06：此试验版实机失败，不能作为正常发布。
- 原配置关闭应用控制台；串口仅取得 ROM `rst:0xc (RTC_SW_CPU_RST), boot:0x29 (SPI_FAST_FLASH_BOOT), Saved PC:0x40377694`。没有完整异常回溯，暂未确定具体失败函数，不武断归因于某一个分配选项。
- 已立即只回刷7.1.5-usb应用，日志 `F:/CABadgeBuild/temp/lcd-rollback-flash.log` 确认 `Hash of data verified`。实读服务握手和状态恢复：firmware=7.1.5-usb、asleep=false、Wi-Fi enabled=false/error=0、BLE enabled=true/advertising=true/error=0。证据 `F:/CABadgeBuild/temp/lcd-rollback-state.json`。用户随后回复“恢复”，实体屏目视恢复按用户反馈通过；BLE状态不等同手机连接通过。
- 工作台默认安装源已改到 `outputs/cabadge-v7-perf-usb-20260921`；失败试验包新增 REJECTED.md。源码撤回上述两项内存配置；暂停继续实板试验，先恢复可用状态。NVS、壁纸分区和分区表未重写。
- 电脑 Bluetooth 适配器存在但处于关闭状态；Bleak 实际扫描被系统以 POWERED_OFF 拒绝。这不构成板端扫描或连接失败的证据。

### 2026-09-21 小步内存与局部刷新复测（R31，研究暂停点）

- 延续R30：用户确认回退后屏幕恢复。失败的7.1.6-memory保留，不再使用其无线内存配置。
- 7.1.7-ram仅将USB协议解析/报文/状态缓冲移入PSRAM，保持无线默认内存策略。实读Wi-Fi与BLE均enabled=true、error=0，BLE广播正常；六场景采样内部空闲最低18699 B。此结果不是手机BLE连接或Wi-Fi数据通信复测通过。
- 7.1.8-partial将LVGL单PSRAM绘图缓冲改为PARTIAL；缓冲仍259200 B，双内部DMA传输块未变。PC十张FULL/PARTIAL对照图逐像素一致，属于软件绘制证据。实板六场景采样完成，内部空闲最低18703 B；实体目视、长期稳定及上传回归仍待测。
- 实板证据：`outputs/performance/20260921-154735-410345.json`（7.1.7）和`20260921-155121-266669.json`（7.1.8）。两次均Wi-Fi/BLE开启，场景5扫描请求返回0且记录实际扫描活动，未连接热点/未做吞吐测试。

|场景|7.1.7完成提交FPS|7.1.8完成提交FPS|7.1.7/7.1.8绘制P95 ms|
|---|---:|---:|---:|
|Carousel|6.73|6.39|137.853 / 137.869|
|壁纸与抽屉面板切换|10.91|15.00|83.985 / 82.717|
|蓝色名片切换|12.51|12.33|58.197 / 57.784|
|静态页面|0|0|0 / 0|
|菜单切换|10.34|10.02|82.468 / 75.377|
|Wi-Fi扫描时Carousel|6.34|6.22|140.987 / 142.122|

- 静态0表示采样窗口内没有新提交，不是面板停止扫描。单轮样本不能证明小幅升降有统计意义；抽屉提交率约提升37.5%，Carousel未改善。完整帧传输回调区间约13.013 ms，flush约14.5 ms；这些口径有重叠，不能机械相加。
- 源码定位：Carousel每次布局都依次move_foreground，LVGL9.4的move_to_index在实际改变层级时invalidate父对象；疑似持续扩大脏区。尚未修复或实测该项收益。不得写成已解决。
- 7.1.9-async异步NVS候选已完成一次编译，尚未烧录；之后USB延迟ACK缓存逻辑还有一处小修，当前源码不等同已编译包。原生10/10 CTest、LCD DMA检查及采样协议自检通过，但不代表候选实板通过。
- 用户要求先阅读两篇LVGL优化文章，暂停固件修改及刷写；板端最后一次已验证版本7.1.8-partial，工作台默认安装仍7.1.5-usb。文章研究见`firmware-v7/LVGL_OPTIMIZATION_REVIEW.md`。

### 2026-09-21 日常任务与实体 FPS（R32）

2026-09-21 R32：用户要求定位影响帧率的无用任务并增加实体 FPS 开关。已烧录并读回7.2.3-monitor；静态 main 单核CPU 97.31%→4.51%，修正pdMS_TO_TICKS(5)=0忙轮询；旧USB像素投屏已移除，5Hz状态查询没有测出主要帧率影响。设置→显示→FPS可开关，默认关闭；排除自身刷新和LVGL内部取整事件，最终静态/HUD静态均0。Carousel/抽屉/名片完成提交率 6.6/13.72/11.88 FPS，未达30FPS；内部空闲最低11803 B。用户确认前轮跳页因自己触摸，菜单/名片静态重测为0。Wi-Fi/BLE扫描和广播通过；手机连接、上传、长期稳定与FPS目视待复测。详见firmware-v7/RUNTIME_PERFORMANCE_REPORT.md和outputs/performance/runtime-20260921-164334.json。

保留7.2.0～7.2.2计数误差与手动干扰证据；仅最终7.2.3静态验证用于结论。10/10软件回归和专用计数检查通过；没有把传输完成率称作面板扫描Hz。发布时verification.json保持原义，新增hardware-verification.json记录烧录后验证。

### 2026-09-21 流畅度优先重构与逐项对照（R33，7.3.3 已烧录，人工验收待测）

用户明确授权以流畅和跟手为先，允许取消 Carousel 并重构；保留原有实际服务。COM3 完成以下应用分区烧录/哈希校验与自动采样，未覆盖用户手指主观体验或手机端完整回归：

|版本/改动|壁纸浏览提交 FPS|抽屉 FPS|名片切换 FPS|证据|
|---|---:|---:|---:|---|
|7.2.3 本轮基线|5.55|13.42|11.90|runtime-20260921-181902.json|
|7.3.0 原生定尺寸横向分页、RGB565 缩略图、输入定时器 10 ms|26.11|13.25|11.66|runtime-20260921-182601.json|
|7.3.1 复用内部 DMA 缓冲绘图试验|27.03|13.08|8.58|runtime-20260921-182858.json|
|7.3.2 恢复 PSRAM 绘图、实体根背景与抽屉取消大圆角|27.01|15.23|12.06|runtime-20260921-183145.json|
|7.3.3 Octal PSRAM 80MHz / 64字节缓存行、输入中断清理|28.40|17.61|17.37|runtime-20260921-183931.json|

基线及中间版每场景约 6 秒，最终版约 8 秒；是自动场景窗口内的内容提交率，不是面板扫描 Hz。7.3.1 名片性能退步，已明确否决并恢复原缓冲路径；不能把内部缓冲试验列为成功优化。第一阶段 Wi-Fi/BLE 扫描请求成功、错误码为 0；扫描期间壁纸分页约 26 FPS，不代表已验证手机连接/GATT/上传。历史失败与旧发布文件保留。最终版已烧入 bootloader 与 app、哈希校验通过并读回7.3.3；分区与用户数据未擦除。新版 Wi-Fi/BLE 扫描窗口27.59/27.89 FPS，静态/HUD静态内容刷新为0。基线BLE关闭、新版广播开启，不能声称完全同条件。

新版平均绘制：壁纸12.04、抽屉20.85、名片24.46 ms；对应 flush 5.11/7.79/13.97 ms。PSRAM周期空闲增加196608 B；内部周期最低7331 B，最大连续块最低4608 B，低水位汇总出现159 B（非同时瞬时总空闲），余量仍紧。10/10 CTest及驱动/输入取消/协议/工作台检查通过；真实手指延迟、目视、手机GATT/上传及长期稳定待验收。详情见 [FLUID_PERFORMANCE_REPORT.md（历史）](https://github.com/nbtca/CABadge/blob/d1fe9716b383dcb6fd292d683265beacd92fde64/firmware-v7/FLUID_PERFORMANCE_REPORT.md)，发布包独立保存hardware-verification.json。

当前候选入口：7.3.3-fluid 使用说明（本地历史资料，未入库：`outputs/cabadge-v7-fluid-20260921/使用说明.md`），[工作台](firmware-v7/run.cmd)。

### 2026-09-21 双绘图缓冲与异步 DMA 对照（R35，已完成本轮实板/目视复测）

用户授权继续基于7.3.3实现，明确要求防撕裂，并取消模拟器验收前置。开始时COM3实际读回8.0.0-article-dev；用户确认继续独立7.3.3后，恢复既有7.3.3 bootloader/app并取得本轮基线。8.0源码和发布包不改；版本握手不是8.0功能通过的证明。

基线 `outputs/performance/runtime-20260921-205348.json`：壁纸26.31、抽屉17.95、名片16.91内容提交FPS；静置0。使用本轮基线比较，不替换R33历史数据。

7.3.4-async候选编译/烧录哈希校验通过：两块360×360 RGB565 PSRAM绘图缓冲、core1传输任务，沿用40MHz连续CS内部双32行DMA；GUI通过等待回调/非阻塞轮询确认完成后通知LVGL。主任务栈16→12KiB（依据此前高水位余量），新增LCD栈3KiB；实测剩余栈高水位main5168B、LCD2060B。没有改UI页面/手势或带入8.0服务重构。

生产代码检查通过：显示worker所有权、GUI完成通知/失败路径、原DMA分块/字节序/错误排空、跨帧运行统计、采样器自检。未运行模拟器。本版首轮13场景完成：壁纸26.74、抽屉19.29、名片21.26内容提交FPS；静态/HUD静态为0，内部周期空闲最低9027B。证据runtime-20260921-210103.json/.jsonl。用户明确反馈“显示正常，没有发现撕裂或重复”，本轮目视复测通过，工作台默认切到7.3.4；不扩大为硬件同步或长期零撕裂保证。

第二轮runtime-20260921-210405.json/.jsonl静态场景跳页，用户确认“我刚刚在摸”，整轮保留但不纳入正式性能比较。专项20260921-210335-859618.json带帧末等待标记，与常态流水线FPS区分。手机GATT/连接上传和长期稳定仍待复测。详见[ASYNC_DMA_REPORT.md（历史）](https://github.com/nbtca/CABadge/blob/d1fe9716b383dcb6fd292d683265beacd92fde64/firmware-v7/ASYNC_DMA_REPORT.md)。

## 6. 固件与文件索引

|用途|入口与证据|状态|
|---|---|---|
|第 3 组最小系统|bringup-20260919（本地历史资料，未入库：`outputs/bringup-20260919`）、其中 verification.json 与 serial-reset-check.log|用户/日志确认运行通过|
|第 4 组显示诊断 r2|测试步骤（本地历史资料，未入库：`outputs/display-bringup-20260919/测试步骤.md`）|软件命令问题已修正；硬件显示阻塞，当前不按旧步骤接屏|
|无屏 ADC/扫描 r1|测试步骤（本地历史资料，未入库：`outputs/headless-bringup-20260919/测试步骤.md`）、发布检查（本地历史资料，未入库：`outputs/headless-bringup-20260919/verification.json`）|用户日志确认扫描和 ADC 读数，对表经用户确认|
|Wi-Fi/BLE r1，当前测试版|flash-and-connect.cmd（本地历史资料，未入库：`outputs/wifi-connect-20260919/flash-and-connect.cmd`）、测试步骤（本地历史资料，未入库：`outputs/wifi-connect-20260919/测试步骤.md`）、发布检查（本地历史资料，未入库：`outputs/wifi-connect-20260919/verification.json`）|连接、ping、BLE 重连及基本共存获本次日志验证|
|源码与交接|firmware/bringup（本地历史资料，未入库：`firmware/bringup`）、HANDOFF.md（本地历史资料，未入库：`firmware/HANDOFF.md`）|后续继续基于已打板引脚和当前源码|
|历史整片备份|flash-before-diagnostic.bin（本地历史资料，未入库：`outputs/bringup-20260919/flash-before-diagnostic.bin`）|早期 16 MB 空白 Flash 备份；不是当前运行固件的备份|
|Windows 烧录助手|JXBadgeFlasher.exe（本地历史资料，未入库：`outputs/flasher/JXBadgeFlasher/JXBadgeFlasher.exe`）、[使用说明](tools/flasher/README.md)、软件验证记录（本地历史资料，未入库：`outputs/flasher/JXBadgeFlasher/validation.json`）|可双击运行；内置四版固件，可选择新版输出目录；软件检查通过，实际烧录待用户验证|
|Windows 用户层预览|run.cmd（本地历史资料，未入库：`firmware/run.cmd`）、使用说明（本地历史资料，未入库：`firmware/README.md`）、自动开发预览（本地历史资料，未入库：`firmware/preview.cmd`）|原生 LVGL/SDL2；离线预览与只读 USB 诊断日志入口；软件检查见 T02，真实 USB 链路见 N10，界面尚未运行于实板|
|板端 UI 与 USB 替代屏幕 V1|USB 屏幕说明（本地历史资料，未入库：`firmware/usb_screen/README.md`）、新固件（本地历史资料，未入库：`outputs/usb-screen-v1-20260920`）、电脑显示端（本地历史资料，未入库：`outputs/usb-screen-viewer/JXBadgeUSBScreen/JXBadgeUSBScreen.exe`）|软件验证 T03；先烧录新固件再连显示端，真实链路与图形配网待 N11|
|板端 UI v2：BLE 与息屏摇晃唤醒|新固件（本地历史资料，未入库：`outputs/usb-screen-v2-20260920`）、软件验证（本地历史资料，未入库：`outputs/usb-screen-v2-20260920/software-validation.json`）、根目录 `JXBadge USB屏幕.lnk`|历史版本；软件检查 T05，用户截图 U05/L06 覆盖部分投屏与 BLE 显示；其余 N11～N14 待测|
|NBTCA Badge TOOL 与 UI v3|应用（本地历史资料，未入库：`outputs/badge-tool/NBTCA_Badge_TOOL/NBTCA_Badge_TOOL.exe`）、固件（本地历史资料，未入库：`outputs/usb-screen-v3-20260920`）、验证（本地历史资料，未入库：`outputs/usb-screen-v3-20260920/software-validation.json`）|历史 v3，软件 T06，实板 N15 待测；v1/v2 保留历史|
|CABadge 无线 P0 v4|应用（本地历史资料，未入库：`outputs/badge-tool-v4/NBTCA_Badge_TOOL/NBTCA_Badge_TOOL.exe`）、固件（本地历史资料，未入库：`outputs/usb-screen-v4-20260920`）、协议与审计（本地历史资料，未入库：`firmware/usb_screen/WIRELESS_P0.md`）|历史预设；软件 T07；实板 N16 部分通过（R12～R14 用户反馈上传/保留、Web 控制与撤销、BLE 授权/读写/通知/重连）|
|CABadge v5 圆屏界面|应用（本地历史资料，未入库：`outputs/badge-tool-v5/NBTCA_Badge_TOOL/NBTCA_Badge_TOOL.exe`）、固件（本地历史资料，未入库：`outputs/usb-screen-v5-20260920`）、设计说明（本地历史资料，未入库：`firmware/UI_DESIGN_V5.md`）|当前预设；软件 T08；新版上板 N17 待测|
|CABadge v7 核心预览|[工作台入口](firmware-v7/run.cmd)、[交接](firmware-v7/HANDOFF.md)、独立固件及软件证据（本地历史资料，未入库：`outputs/cabadge-v7-preview-20260920/software-validation.json`）|新增独立预览入口；软件 T09，通过范围不含新硬件；上板 N18 待测，旧预设未改|

无屏 r1 应用 SHA-256：`1129e0d6298dd4cf0f531a950388a51b3e861e3afc39ed113884776d6f9ef1e3`。

Wi-Fi/BLE r1 应用 SHA-256：`95510b96f38768fd5e9590372c479276f483af73b57dbebb839d18264417db49`。

上述是本机发布产物哈希，用于追溯对应目录；并非后来实板全片读回哈希。部分目录的 `verification.json` 中 `NOT_TESTED`/`flashed_this_run=false` 是当时编译发布时的快照，保留原样；发布之后的实板结果以本文件为准。每次诊断启动会擦写专用最后 4 KB 测试分区。

## 7. 后续更新规则与记录模板

用户要求：以后每次测试，在分析日志/测量结果的同时更新本文件；不另外生成互相冲突的“最终测试报告”。项目根目录 AGENTS.md 与固件交接已指向本文件。

每次更新：

1. 对照样机、PCB、供电、固件版本/哈希和装配变化，确认本次测试条件。
2. 更新第 2 节对应编号的当前状态；新项目追加编号，不重用旧编号。
3. 追加日期、操作、原始结果或日志摘录、结论与范围；如保存日志，链接真实文件。
4. 失败修复后保留失败过程，补上修复与复测证据；不能直接删除失败记录。
5. 更新待测清单和修订记录；若影响后续工作，同步 HANDOFF.md 的最新摘要。
6. 未提供的数值写“未记录”；用户自测通过注明反馈来源；仅有编译/模拟结果不能升级为实板通过。后续测量名称使用 **VBUS、3V3、GND、BAT、PWR、EN** 等真实丝印。

追加记录模板：

```text
日期/时间：
项目编号、样机：
PCB、固件版本/哈希：
供电与装配条件、与上次的变化：
操作与通过条件：
原始实测值/日志/照片或文件路径：
结果：通过 / 初步通过 / 未通过或阻塞 / 待测
证据来源与结论范围：
处理与复测、下一步：
```

## 8. 修订记录

|日期|版本|内容|
|---|---|---|
|2026-09-19|R1|汇总本次对话的供电、下载、存储、显示故障、传感器、电池/充电、ADC、Wi-Fi、BLE 与共存结果；BLE 已完成首次连接、断开恢复广播与重连；保留未验证边界，建立持续更新入口|
|2026-09-19|R2|根据已有 RSSI、ping 与 BLE 日志补充天线评估；明确距离/方向未知、功能初筛通过而天线效率/匹配/覆盖待测；新增固定距离、方向及最终装配对比建议，无新增实测结果|
|2026-09-19|R3|用户确认手机“就在旁边”，补记近距离条件；收紧为近距离通信初筛通过，不据此评定天线效率或匹配；具体距离仍未测量，无新增通信测试|
|2026-09-19|R4|新增 Windows 原生图形烧录助手的软件验证与首次实板待测项；四版内置诊断固件保持原内容，未新增硬件通过结论|
|2026-09-20|R5|新增原生 LVGL 用户层重设计的桌面软件检查项 T02，先记待运行；依据既有 ADC、加速度、近距离 Wi-Fi/BLE 结果整理界面范围，未新增实板通过结论，保留显示/触摸阻塞历史|
|2026-09-20|R6|补充 USB 只读实板日志与电脑用户层预览流程；T02 编译、始终执行的自检 2/2 和截图目检通过，新增真实 USB 端到端待测 N10；明确烧录助手配网后释放串口、不 RESET、BLE 事件等待及电脑预览边界，未新增实板通过结论或修改发布 verification.json|
|2026-09-20|R7|纠正为 ESP32 运行共用 UI、电脑经 USB 替代屏幕/触摸；增加手机式 Wi-Fi 列表与密码页，新增软件检查 T03 和实板待测 N11；保留历史 N10，不再作为当前流程；原诊断通过结论未扩大，新固件尚未烧录|
|2026-09-20|R8|烧录整合进 USB 屏幕工作台，默认内置 UI 固件，复用旧校验/烧录逻辑，成功自动连接；新增 T04 软件证据与 N12 实板待测。本轮识别 COM3，未访问板子或改动板端固件；保留 R7 发布验证含义|
|2026-09-20|R9|记录用户反馈 nRF 无法发现 L05，核对 v1 未启动 BLE 但不假定用户当时固件。发布 UI v2：图形 BLE 开关/广播/来访连接/主动扫描连接，取消摇晃跳转并接入 SC7A20 仅息屏唤醒。四项 CTest、三项 Python 检查、ESP32 编译及打包应用五预设/stub 检查通过；新增 T05、N13、N14，未烧录、未新增实板通过。当前工作台验证文件随 v2 更新，历史 v1 固件 verification.json 保留原样|
|2026-09-20|R10|新增用户 02:47 截图实测 U05/L06：USB UI、BLE 来访连接及扫描列表显示；保留 L05 失败和其余待测边界。按用户要求重构原生工作台、更名 NBTCA Badge TOOL，发布 USB/Wi-Fi 壁纸上传与双槽保存 v3；软件 T06、实板待测 N15。没有自动烧录，历史 v1/v2 发布清单保留|
|2026-09-20|R11|按用户确认先执行无线 P0：短时授权、真实状态、Web/BLE 控制、上传会话完善与后台提交；软件 T07、实板待测 N16。不自动烧录、不新增硬件通过结论，v1/v2/v3 历史证据保留|
|2026-09-20|R12|用户对上一轮四步整体回复“正常”：v4 安装/USB 投屏、手机管理页、手机上传并显示、完全断电重启保留按反馈通过；N16 更新为部分通过。网络路径、固件哈希和逐项日志未提供，Web 控制、授权边界及 BLE GATT 等继续待测；同步 HANDOFF|
|2026-09-20|R13|用户对手机网页控制四步整体回复“正常”：状态对照、息屏唤醒/壁纸保留、预览亮度、关闭管理后拒绝及新入口恢复按反馈通过。N16 更新，BLE GATT、自然过期等继续待测；同步 HANDOFF，不修改发布 verification.json|
|2026-09-20|R14|用户对 BLE 四步整体回复“正常”：未授权拒绝、Session 授权、Status 读取/通知、Control 三项控制、重连重新授权按反馈通过；同步 N05/N06/N16 和 HANDOFF。没有新增原始日志/时长/并发流量证据，自然过期等仍待测|
|2026-09-20|R15|按 UI 准则及计协品牌色重构 v5 共用界面，新增软件检查 T08、新版上板待测 N17；旧 v4 实板证据和发布元数据保留。未收到自然到期的新反馈，未自动烧录；同步 HANDOFF 与设计说明|

|2026-09-20|R16|发布独立 v7 核心预览、受限 PC LVGL 与 USB 实板服务桥；新增 T09 软件证据和 N18 实板待测。记录 PC 帧率与链接期占用，明确不是实屏或运行时峰值；未打开 COM 端口、未烧录，旧硬件结论保留|
|2026-09-20|R17|记录用户 v7 安装因缺少 esptool 失败；纠正启动器 Python 环境，新增烧录依赖/stub 预检与缺模块回归 T10，本机通过。失败保留，真实安装和 N18 仍待重试；未自动烧录或新增硬件通过结论|
|2026-09-20|R18|追加用户 v7 握手后无线入口忙提示；实际 COM3 探测确认握手、Wi-Fi/BLE 扫描通过（6/12 项）。减少动态层级回归先失败后修复，PC 8/8 通过；N18 更新为部分通过。保留 R17 安装失败历史；本轮未重烧，原固件清单不改|

|2026-09-20|R19|发布独立 7.1.0-preview：补齐既定动效，新增板端绘制时间/脏区字节/内存采样与 PC 校准入口。新增 T12 软件检查、N19 实板待测；区分实际 PC 更新率、板端待测绘制与 QSPI 估算。未打开串口采样、未自动烧录；R18 实板证据及旧发布清单保留|

|2026-09-21|R20|用户报告屏幕座子已焊接完成，记录为维修进展；未提供新型号、连通/电压或显示触摸复测。核对 v7.1 源码仍为 USB 服务/无屏采样，背光 GPIO1 LOW、无实体 LCD 输出，不能用该固件黑屏判定换座失败。D01～D03/N01/N02 继续待复测，未改代码或烧录|

|2026-09-21|R21|换座后用户在收到屏幕诊断 r2 烧录/测试步骤后反馈“正常显示成功”。D01 基础点亮按用户反馈通过，F02 黑屏子项恢复，N02 部分通过；无新照片、日志、固件读回哈希或具体测试时长，不扩大为触摸/背光电流/PWM 关断/帧率通过。同步交接；未改固件或发布时 verification.json|

|2026-09-21|R22|用户要求直接复用昨天 v7 固件并使用 40 MHz QSPI；发布 7.1.1-lcd，新增 T13 软件证据及 N20 实板待测，工作台安装入口切到新包。原 r2 点亮通过不扩大为本版通过；未自动烧录、未改变历史发布清单；同步交接|

|2026-09-21|R23|分析用户测试视频并收到肉眼确认撕裂/重复标题；D02 基础触摸按视频初步通过，新增 D04/F04 失败项，N20 部分通过但动态刷新不通过。核对手册 QSPI Max50MHz、TE 同步及冻结 PCB J1 TE 悬空；记录分块同步发送事实与后续测量/优化方向。未测实际 FPS、未改固件、未烧录；同步交接|

|2026-09-21|R24|核对用户新增资料目录与厂家驱动，发布7.1.2-lcd完整帧/连续DMA候选及实体采样；新增T14软件通过、N21实板待测，D04/F04失败保留。更新工作台与交接；未访问串口、未自动烧录、未改历史发布证据|

|2026-09-21|R25|读取用户14:48实体采样JSON，7.1.2-lcd三场景完整，记录绘制/flush/整帧/内存及无线状态。N21部分通过，完成FPS为3.42/10.42/9.88，主要耗时在绘制；无撕裂结论仍待观察，F04保留。仅读文件、更新记录，未访问COM、未改固件或历史发布证据|

|2026-09-21|R26|用户确认7.1.2撕裂/重复标题已消失，主要是帧率低。D04/F04按用户观察恢复，保留历史和TE边界，N21部分通过；开始针对绘制热点优化，后续新固件另记待测|

|2026-09-21|R27|发布7.1.3绘制优化：-O2、RGB565/RAM壁纸、圆角缩略图和名片缓存，保持40MHz与7.1.2物理驱动；T15软件通过、N22实板待测，D05低帧率待改善。记录PC对照边界和50MHz分频事实。未开COM、未自动烧录、未改历史发布证据|

|2026-09-21|R28|读取15:06的7.1.3实体采样，与7.1.2比较：Carousel/抽屉/名片6.59/11.15/12.56FPS，提升92.7%/7.0%/27.1%；仍未达30FPS。更新D05/N22部分通过与内存/条件边界；新版撕裂视觉复测待反馈。本轮仅读文件/维护记录，未开COM或修改固件|

|2026-09-21|R29|LCD专项测量开始：新增实际基线、六场景DMA计时及手动触摸数据；删除旧USB像素投屏并实测。发现内部RAM不足与用户报告BLE初始化失败F05，修复和后续优化进行中；扫描失败不计通过|

|2026-09-21|R30|新增F06：7.1.6-memory启动/黑屏失败；立即回退7.1.5-usb并读回版本、USB握手及BLE广播状态；用户已回复“恢复”，实体目视恢复按反馈通过。失败包撤离默认安装入口，保留全部失败证据|

|2026-09-21|R31|记录用户确认恢复、7.1.7/7.1.8六场景实测及边界；7.1.9未刷入。按用户指示暂停固件实验，核对两篇优化文章与LVGL9.4官方文档/本地源码|

|2026-09-21|R32|完成任务/内存对照和可关闭FPS；修复主循环忙轮询与HUD自计数；7.2.3已刷入，记录无线扫描、静态重测、内存余量及未测边界，未宣称动画大幅提速|

|2026-09-21|R33|完成流畅度优先7.3.3并烧录/采样；原生分页、PSRAM80MHz/64字节行、大圆角简化；小内部绘图缓冲退步已回退。人工跟手/目视、手机连接上传与长期稳定待测，保留内存余量限制|
|2026-09-21|R34|用户报告Article滑动时上下错位、停止恢复，新增F07；8.0.1恢复整帧合成后连续DMA提交，测试/Release各22/22及两套ESP32构建通过；明确偏离文章局部传输并增加约492KiB PSRAM。未访问COM或烧录，实屏待复测；保留8.0.0产物和历史失败|

## Article 独立固件软件阶段（2026-09-21，实板待测）

- 独立目录 `firmware-article`，开发版本 `8.0.0-article-dev`；本条不改变 R33 及其他固件的实测结论，也不替换默认烧录入口。
- 用户要求测试固件开启 LVGL 内置性能面板、正式固件关闭：已通过默认测试配置 / `-Release` 编译开关落实。两套原生、两套 ESP32 构建成功，CTest 各14/14通过；实际ELF符号检查证实测试版含监控面板和定时更新回调，Release不含。
- 证据：`firmware-article/build/profile-audit.json`，复核脚本 `firmware-article/check_build_profiles.py`；源码/产物哈希一致。测试和Release导出分别为 `outputs/cabadge-article`、`outputs/cabadge-article-release`，均为开发候选。
- 未访问COM、未烧录；本版实板启动、显示/触摸、监控可读性、无线并发、内存余量与性能全部待测。完整IO隔离及文章逐项验收未完成，不能宣称重写目标已完成。内置CPU值不是双核总负载，FPS不是屏幕扫描Hz。

## Article 独立固件 IO 隔离阶段（2026-09-21，实板仍待测）

- 仅更新独立 `firmware-article`：触摸/SC7A20/ADC后台采样，USB回复后台发送；GUI通过快照与有界队列交接。NVS/部分无线服务仍未隔离，整版文章对照未完成。
- 两套原生和ESP32构建成功；测试/Release软件检查各16/16通过。实际ELF、暂存源码和导出哈希检查通过，详见独立HANDOFF和 `build/profile-audit.json`。测试内置监控开启、Release关闭保持有效。
- 当前测试固件SHA256：`6c2ff2234c70e4a9252ad93b47347a14b550d58a1fde1357b7f7a135cdd32def`；Release：`93fdb7319729cd8dfd23124d9590c39807c8223effb6ed237d5fbbac43857e0e`。均为开发候选。
- 未访问COM、未烧录、无本版实测日志；新增任务栈/队列的实板余量、并发、触摸延迟、无线功能仍待测。其他对话固件及历史实板结论不变。

## Article UI 设置异步保存阶段（2026-09-21，实板待测）

- 独立 `firmware-article` 的亮度/动效/壁纸选择改为后台NVS保存，带版本单记录兼容读取旧键；USB ACK、手机结果及壁纸“已应用”等待实际完成。繁忙、重复、失败和新会话路径完成软件检查，失败恢复界面最后确认值，不据此保证Flash已撤销写入。
- 两种原生与ESP32构建成功；测试/Release各17/17检查通过，最终ELF/源文件/产物哈希审计通过。日志为 `F:/CABadgeBuild/article-save-*.log`；详细说明见 `firmware-article/HANDOFF.md`。
- 测试firmware.bin SHA256：`6420b367ab617cfb6ca0c6d552c01b9549345391d50084e393396d2a5b712925`；Release：`8a10a7bb60bbf3518333c635550eabd9ee741a424e48f3b1e09f915c385ab84b`。均为开发候选。
- 未访问COM、未烧录。实板启动/并发/内存余量/保存后重启及掉电恢复待测；Wi-Fi等剩余隔离和整版文章验收未完成，历史实板结论保留。

## Article Wi-Fi 与服务 IO 阶段（2026-09-21，实板待测）

- 独立分支已把Wi-Fi驱动/凭据NVS移到core0，GUI使用快照和延迟结果；热点关闭可覆盖在途开启。BLE复用NimBLE队列，USB壁纸读取复用RAM；管理锁内不再JSON格式化，壁纸worker创建失败不再让GUI等锁。
- 两种原生和ESP32构建成功，测试/Release各18/18检查通过，最终ELF/源/哈希审计通过；见 `firmware-article/HANDOFF.md`、`build/profile-audit.json` 和 `F:/CABadgeBuild/article-wifi-*.log`。
- 测试firmware.bin SHA256 `d9879a961801e8d7764baf6aa7d354fd77e0fbb6518ab5b5c7f135cc97142e7a`；Release `ec5dc4d2f7203c3f2aec7a482235d5db242db16b2572d2e20d71806f3dcb5c88`。开发候选未开COM、未烧录；真实无线并发、内存/任务栈余量、响应和持久化待测。严格调度、性能工具、页面/进阶项和最终文章验收仍未完成。

## Article 监控与并行采样阶段（2026-09-21，实板待测）

- 独立`firmware-article`测试配置默认开启LVGL内置性能面板，Release编译移除；专项采样暂停内置与自定义监控，完成/取消/错误后恢复。GUI按1000Hz RTOS每轮让出5ms，输入任务仍10ms；异步DMA探针不再把重叠耗时相加。
- 两套原生/ESP32构建成功；全量CTest各19/19通过，新增局部刷新检查后的定向复测各2/2通过，当前共20项注册。Python性能/运行期工具与工作台自检通过；ELF确认测试有内置监控、Release无，目标tick配置/源码/产物哈希核验通过。见独立HANDOFF、`build/profile-audit.json`及`F:/CABadgeBuild/article-probe-*.log`。
- 测试firmware.bin SHA256 `d244f0969840600fd0616edde04f2c91c4ed78895f3077b923890218f18f3b79`；Release `2f0bfd8a632e59d897af5f450b62824d55399bfe10ea24f43c404dac4861bfe4`。面板可读性只做本机LVGL渲染检查，未开COM、未烧录；本版真实帧率/触摸延迟、调度开销、任务栈/堆余量、并发和监控实屏仍待测。
- 历史板端结果保留，未改默认安装入口。外部面板生命周期、进阶条目结论及整版文章最终验收仍在进行，不能将本阶段记为整版或实板通过。

## Article 最终软件交付（2026-09-21，本版本实板待测）

- 独立目录 firmware-article 已完成文章基础优化的软件实现与逐项对照；详情及无线/手机管理控件按需释放，新增壁纸直接位置导航，验证纵向惯性与横向阈值/时序。语音翻页未实现，冻结硬件无板载音频采集链路。详见 firmware-article/FINAL_AUDIT.md、ARTICLE_COMPLIANCE.md。
- 两套原生LVGL/SDL2及ESP32构建成功；测试和Release完整回归各22/22。实际ELF/源码/哈希审计通过，测试内置性能面板有、Release无；工具自检和离线工作台启动/退出通过，无COM访问。证据归档 outputs/cabadge-article/evidence/；同目录有源码快照和交付哈希清单。
- 测试firmware.bin SHA256：8e9221a49d624948d0e97b679535bad42fe8dfcb260e338eba0ace54a6f1e9b3；Release：5ed16d41b3a4452da850ff70ea411edcc6037c4bef90d51b242856bf03f6c611。均为8.0.0-article-dev开发候选，Release只指关闭诊断的构建配置。
- 本阶段未烧录，无本版实板日志/测量值。真实帧率、触摸延迟、栈/堆余量、无线并发、保存重启/掉电恢复、监控实屏均记待测。静态RAM链接统计和PC截图FPS不得作为对应实测值；保留全部历史实板结论，不修改硬件与默认安装入口。

## Article 8.0.1整帧提交候选（R34，实屏待复测）

直接证据：用户描述“滑动时上下画面错位，停下恢复”；无新视频、日志或固件哈希。按上下文推定8.0.0测试版，新增F07失败，保留此前v7恢复记录。

软件处理：8.0.1-article-frame将双10行PARTIAL改为双整帧PSRAM FULL，先合成再连续发送；内部DMA暂存仍10行、QSPI40MHz、c7c59dff引脚/初始化不变。额外PSRAM504000字节；局部变化整帧更新的开销需实测，不宣称硬件双缓冲同步或彻底零撕裂。

软件验证：原生/ESP32两套构建成功，测试/Release各22/22；真实ELF监控开关、源码和产物哈希检查通过。新增整帧一次提交/静止不强刷断言；工具自检无COM访问。证据在outputs/cabadge-article-frame-8.0.1/evidence，细节见firmware-article/TEARING_FIX.md。测试firmware.bin SHA256为0ac5d17cd745104b80229a2bfc7bc843effc0bed00c292b0f4c3f9f1e353c0da；Release为e3e29cbf4b7a5365151000f03d6c41a183f73caff82a10dd78a4c52993b397ce。

本轮未烧录，F07仍待用户复测。后续检查同样滑动是否仍有上下断层、静止恢复及FPS/无线入口；不能根据构建成功写成实板通过。

|2026-09-21|R35|完成7.3.4双PSRAM绘图缓冲/异步DMA及实板对照，用户确认显示正常无撕裂或重复，默认安装切换；触摸干扰第二轮排除正式对比；不混用Article R34结论|

## 2026-09-21 实体显示16ms刷新试验（R36）

2026-09-21 R36：7.3.5-refresh16已烧录/读回，实体显示刷新周期33→16ms，用户反馈没有撕裂、重复或触摸异常，工作台默认切换。观测壁纸28.08→27.74、抽屉19.10→24.23、名片21.07→20.82内容提交FPS；静态均0。旧Wi-Fi未连接、新版自动连接，且启动历史不同，非严格受控A/B；不将内存差异归因于改动。LVGL动画定时器仍33ms。详见firmware-v7/REFRESH16_REPORT.md，TE/长期/触摸仪器延迟仍有限制。

|场景|7.3.4 / 33ms|7.3.5 / 16ms|
|---|---:|---:|
|壁纸浏览|28.08|27.74|
|上下抽屉|19.10|24.23|
|蓝色名片切换|21.07|20.82|
|壁纸＋USB状态5Hz|28.18|28.51|
|壁纸＋Wi-Fi扫描|27.72|28.16|
|壁纸＋BLE扫描|28.15|27.76|
|壁纸＋FPS显示|27.97|27.63|

证据：outputs/performance/runtime-20260921-211759.json与runtime-20260921-212042.json及对应jsonl。每场景约8秒，周期最低内部空闲5691→7163B，PSRAM同为6581876B；启动/无线状态不同，不归因于参数。用户在自动测试结束后回答“没有”，对应提问中的撕裂、重复和触摸异常。未运行模拟器，未复测长期并发与上传。

|2026-09-21|R36|7.3.5实体刷新16ms完成构建/烧录和13场景采样，用户反馈无异常，默认安装切换；记录无线条件差异，不夸大全面帧率收益|

## 2026-09-21 动画定时器16ms试验（R37）

2026-09-21 R37：7.3.6-anim16已编译/烧录/读回，仅将LVGL全局动画定时器33→16ms，显示刷新仍16ms。同轮7.3.5→7.3.6：壁纸28.38→51.31、抽屉24.34→23.97、名片20.40→20.74内容提交FPS；静态0，双无线状态一致，扫描通过。壁纸main单核78.32%→94.06%，内部周期最低6367B，PSRAM不变。自动阶段原记待确认；后续用户报告缩略图略微撕裂，已回退7.3.5；未运行模拟器。详见firmware-v7/ANIM16_REPORT.md。

|场景|7.3.5 动画33ms|7.3.6 动画16ms|
|---|---:|---:|
|壁纸浏览/吸附|28.38|51.31|
|上下抽屉|24.34|23.97|
|蓝色名片切换|20.40|20.74|
|壁纸＋USB状态5Hz|27.65|49.89|
|壁纸＋Wi-Fi扫描|28.35|50.70|
|壁纸＋BLE扫描|28.13|49.47|
|壁纸＋FPS显示|28.35|49.26|

证据：outputs/performance/runtime-20260921-212629.json与runtime-20260921-212927.json及对应jsonl。两版每场景约8秒，Wi-Fi连接/BLE广播状态一致，启动历史不同，非多轮中位数。只改动画定时器；抽屉/名片另由10ms自定义tick推进。静态页编号与0刷新核对通过。主任务余量及实屏撕裂/跟手、长期/上传仍须按实际证据验收，不把完成提交FPS当作面板Hz。

|2026-09-21|R37|7.3.6动画16ms完成构建/烧录与13场景实测，壁纸约51FPS，静态0；用户报告缩略图撕裂，已回退7.3.5；保留CPU/RAM余量限制|

### R37 用户失败反馈与回退

2026-09-21 R37：7.3.6-anim16实验失败并已回退7.3.5。动画周期33→16ms使壁纸28.38→51.31FPS，抽屉24.34→23.97、名片20.40→20.74基本不变；用户报告“壁纸页面壁纸缩略图有略微撕裂”，记录F08。已烧录7.3.5、校验哈希并读回版本；源码也撤销动画16ms，保留显示16ms，默认安装一直为7.3.5。本次回退后的目视恢复仍待确认。候选数据保留在firmware-v7/ANIM16_REPORT.md，不能作为通过版。

补充核对：当前7.3.5主任务/LVGL在core0，LCD worker在core1；Wi-Fi、BLE host/controller在core0。LVGL配置LV_USE_OS=LV_OS_NONE、默认单软件绘图单元。本轮7.3.5名片main85.80%、core1 idle71.04%，没有双核并行绘图。详见代码main.c、display_worker.c、sdkconfig.verified.h及runtime-20260921-212629.json。

## 2026-09-21 v1.0 发布基线：7.3.7-mem 用户反馈

用户明确确认“目前正式上板的固件是 7.3.7-mem，基本正常使用，但是要备注还存在相当多 bug 后续修复”，并指定作为项目 1.0 Release。

本次按用户反馈记录为“已上板、基本可用，仍有较多 Bug 待修复”。未提供逐项故障、复现步骤、时长或新的仪器测量，因此不关闭历史全部失败/待测项，不推断长期、无线并发、上传异常及所有触摸场景通过。7.3.6 回退记录保持历史原意，当前用户报告版本更新为 7.3.7-mem。

发布整理仅核对文件与校验清单、记录状态，不重编译、不连接 COM、不烧录。原发布 verification.json 保留构建时 PENDING，后续用户反馈另记于 v1.0 发布说明。项目标签 v1.0 不修改固件内部版本号。

## J1 换座采购规格补充（v1.0 发布后）

用户提供商品选项截图，选中“FFC/FPC 0.5mm-18P-抽屉上接（5只）”。结合此前询问实际换装连接器的上下文，记录为首板换装规格：0.5 mm、18P、抽屉式上接触；5只为包装数量，单板用量1只。截图未提供厂家型号、料号或尺寸图，不推定与原 C2856802 为同一器件。

当前 BOM 与采购表已同步该规格，原理图/PCB/封装和冻结生产包不变。换座后显示成功沿用 R21 用户反馈，本轮无新增尺寸、电气或长期测试。截图含个人信息，未上传原图。详细差异与历史文件边界见 docs/J1-CONNECTOR.md。

## 2026-09-23 内存优化及预览退役（R38）

2026-09-23 R38：基于7.3.7完成分阶段内存优化，当前实板读回7.3.10-mem。13场景内部空闲最低采样36951→72511 B（增加34.73 KiB），静态BSS减少12288 B；壁纸/抽屉/名片提交FPS约28.21/25.09/21.71，无明显帧率提升。BLE授权读写/通知与USB上传取消通过；按用户要求移除工作台预览入口及固件壁纸读回。Wi-Fi未连接，真实HTTP及新版本目视/长期验证仍待测；保留F09，新增F10记录7.3.9一次USB采样超时。详见firmware-v7/MEMORY_OPTIMIZATION_REPORT.md。

证据：outputs/performance/runtime-20260923-100928.json（基线）、101254/101922/102156同名前缀数据分别对应7.3.8、7.3.9复测、7.3.10；失败首轮101659保留。每场景6秒，启动历史及无线发现数不同，非严格受控A/B；采样最低空闲不等于启动以来历史最低。最终快照内部空闲74419 B、最大块31744 B、历史最低49899 B。

BLE实际授权读取及7次20 B通知通过，板端断开后恢复广播；USB上传begin/chunk/cancel通过，存储元数据未变。协议/存储/管理4项软件检查、工作台smoke及两个probe self-test通过。未修改显示/触摸/DMA/UI逻辑，未用模拟器。无手机热点连接，不能凭http=true关闭F09；未获得新版本撕裂/触控目视反馈。

本次仅应用区0x10000烧录且哈希验证通过，保留用户存储及7.3.7/v1.0发布包。完整报告与内部RAM排行见firmware-v7/MEMORY_OPTIMIZATION_REPORT.md、firmware-v7/INTERNAL_RAM_RANKING.md；实板验证追加到新包hardware-verification.json，原verification.json保留构建时含义。

|日期|修订|内容|
|---|---|---|
|2026-09-23|R38|7.3.10内存优化实测、预览及壁纸读回退役、F10超时历史与待验证限制|

## 2026-09-23 ESP-IDF 6.1 升级首轮失败与恢复（R39）

7.4.0-idf61（ESP-IDF 6.1.0）构建/哈希校验、烧录、USB版本读回成功，自动连接Egger，BLE报告广播开启。但用户实屏反馈“光有背光没有图像”，记为F11显示失败，不能以MCU提交计数判显示通过。已烧回7.3.10-mem的bootloader、相同分区表和应用，校验哈希并读回7.3.10；用户确认“图像恢复正常”。保留6.1候选与失败数据，工作台默认仍为7.3.10。

证据：outputs/cabadge-v7-idf61-20260923/hardware-verification.json；outputs/performance/runtime-20260923-110627.json仅用于分析MCU处理，不作为实屏成功证据。升级前连接Egger的同场景基线runtime-20260923-105932.json。后续先排查SPI/显示兼容性，尚未完成SDK迁移验收。

R39追加：7.4.1仅改SPI数据线空闲高电平，用户仍反馈只有背光；该假设被否定，已撤销源码试改并再次回退/读回7.3.10。其BLE实际授权读写及6次20 B通知成功。7.4.2增加1MHz面板寄存器回读，ID=0xFFFFFF、电源=0xFF、格式=0xFF，SPI API返回0；不能认为屏幕初始化成功。后续单独验证IOMUX/GPIO Matrix路径差异。

R39追加：7.4.3-idf61改用公开GPIO Matrix路由，仍为40MHz QSPI；屏幕电源状态读回0x9C，像素格式0x55，用户明确确认“图像恢复正常”。F11由此记录为恢复，保留7.4.0/7.4.1黑屏历史。显示差异缩小到6.1原生IOMUX路径，尚无示波器证据，不臆测具体硅片输出使能机制。继续同版本功能与性能复测。

## 2026-09-23 手机管理、历史 Wi-Fi 与壁纸图库（R40）

本轮基于用户已确认显示和触摸正常的 7.4.3-idf61，构建并烧录 7.5.0-library，bootloader/分区表/应用写入哈希验证通过。实板 USB 读回版本7.5.0-library；用户开启原名称、原密码的Egger热点后，设备自动连接，IP 10.228.162.139，RSSI -32 dBm，未重新输入密码。当前用户要求“停下吧我来测试”，已停止自动测试，不继续烧录或操控板子。

原壁纸已迁移至31张图库：selected=2、items=[2]、size=259200、CRC=117737445，与迁移前原图校验值一致。分区从0x710000起扩展到0x8f0000，原1MB区域保留，图库新槽不覆盖已有图。新增缩略图显式分配外部PSRAM，180×180 RGB565每张64800 B；最多31张合计2008800 B。设置子页面转场使用两张显式PSRAM快照，共518400 B，首次使用时分配。

实板启动快照：内部空闲83575 B、最大块31744 B；PSRAM空闲6516976 B。此为启动后单次采样，尚未覆盖31张图库及设置快照分配后的峰值。面板电源寄存器0x9C、格式0x55、读取error=0，不据此代替7.5.0实屏目视验收。

软件检查通过：旧存储掉电/损坏回退；新图库迁移、删除后不重新导入旧图、多张追加、31张容量边界、提交头中断；生产HTTP服务鉴权、取消、CRC拒绝、会话保持24小时和手动撤销、后台选择与删除。以上是本机生产代码替身测试，不是手机实测。构建通过。

待用户实测：开放热点实际连接与Web操作、授权超过300秒、连续上传不覆盖、删除与重启持久化、左右循环滑动、设置子页面触控/转场及目视撕裂。真实HTTP图库自动测试在启动时被用户中断，未产生通过报告，不标记通过。旧版性能基线outputs/performance/20260923-113920-606000.json已保存，新版对比未执行，因此不宣称FPS提升。

发布包：outputs/cabadge-v7-library-20260923。升级前NVS/壁纸备份仅保存在F:/CABadgeBuild/temp/v750-board-backup；含用户数据，不作为公开发布产物。工作台默认包尚未在本轮同步，避免误以为已经完成发布切换。

R39补充：用户已明确反馈7.4.3“触摸和显示都正常”，SDK6.1显示/触摸恢复确认；历史黑屏记录保留。

## 2026-09-23 移除管理授权码（R41）

用户明确要求移除授权码机制，7.5.1-direct已取消HTTP密钥、网页授权表单、屏幕授权开关/代码展示，以及BLE Session授权特征；二维码只包含普通HTTP地址。已编译、烧入应用区并验证哈希，实板读回7.5.1-direct。工作台默认发布包同步为outputs/cabadge-v7-direct-20260923。

实测：电脑实际连接开放CABadge热点，无密码；GET首页200且无授权输入框/密钥头代码；不携带任何密钥读取/status成功；不携带密钥提交/control并收到设备成功执行状态。测试仅提交原息屏状态，未切换用户页面；图库列表和当前图片CRC与测试前相同。证据direct-access-test.json全部通过。测试后电脑恢复原WLAN，吧唧热点保留开启供用户操作。

本机生产服务替身检查覆盖直接HTTP访问、跨来源请求拒绝、BLE直接状态/命令、数据长度/CRC、取消、连接关闭后丢弃排队操作和图库加载/删除，全部通过。未重新开展性能采样或其他范围测试；7.5.x新增图库操作/触感的完整目视验收继续等待用户反馈。

## 2026-09-23 手机浏览器管理页兼容性失败（R42）

用户提供手机截图，管理页报“AbortSignal.timeout is not a function”，设备信息全部为空。确认7.5.1网页直接依赖该API，在该浏览器发出请求前失败。R41电脑HTTP访问成功不代表手机浏览器JavaScript兼容性通过，保留该失败记录。

修改管理页统一api请求为XMLHttpRequest，沿用现有上传传输方式，保留8秒超时、HTTP错误和JSON校验，不引入依赖。浏览器回归测试注入AbortSignal.timeout=undefined：修改前复现连接失败；修改后状态读取、控制、图片上传/恢复默认、取消全部通过。此为桌面浏览器模拟API缺失的验证，手机复测仍待用户确认。

R42复测追加：7.5.2-web已完成构建、应用区烧录与哈希验证，USB读回版本正确；电脑实际连接开放热点，确认板端返回的HTML已无AbortSignal.timeout且使用XMLHttpRequest，无密钥/status和/control均成功。壁纸列表及CRC保持。浏览器兼容性注入测试通过；尚未收到用户手机新版复测反馈，不将电脑结果记成手机通过。证据outputs/cabadge-v7-web-20260923/direct-access-test.json、browser-regression.json及前后测试日志。

## 2026-09-23 HTTP连接占满导致新页面等待（R43）

用户在连接CABadge-2590时访问192.168.4.1，反馈白屏后“网页无法访问”。USB确认7.5.2正常运行，HTTP服务与AP均启用，同时STA连接Egger。受控实板复现：保留3个HTTP连接后，第4个首页请求超时；释放连接后首页恢复200。证据outputs/cabadge-v7-web-20260923/http-connections-before.json。此复现证明连接耗尽缺陷，但不据此排除用户手机链路上的其他问题。

用户明确要求不再用电脑连接热点。已确认相关自动网络测试进程结束；后续仅USB烧录/读回，手机网络访问交由用户复测，不再改变电脑WLAN。

修复范围：保持max_open_sockets=3，启用ESP-IDF6.1原生lru_purge_enable，满额时回收最久未使用的连接。本地SDK httpd_sess.c的HTTPD_TASK_FIND_LOWEST_LRU分支排除for_async_req，异步上传中的连接不参与回收。未增加连接数量或RAM预算。编译后交付7.5.3-http，实测结果待追加。

R43 用户补充：吧唧连接手机 Egger 热点时，扫码上传壁纸正常；手机连接吧唧热点时无法打开管理页。两种路径应分别验收，不能把前者成功当作后者通过。代码核对：wifi_service.c 使用 APSTA；wallpaper_service_poll 在热点开启时使用 http://192.168.4.1/；本地 ESP-IDF6.1 httpd_main.c 监听 INADDR_ANY。两接口共享同一 HTTP 连接池，连接耗尽是已复现缺陷；尚不能证明它是手机直连失败的唯一原因。7.5.3-http 构建成功，等待 USB 烧录与读回。

## 2026-09-23 7.5.3-http：直连热点访问修复候选（R43）

用户实测区分：吧唧连手机 Egger 热点，扫码上传正常；手机连吧唧热点，管理页打不开。已复现 HTTP 3 个闲置连接占满后新请求超时，启用 SDK 原生 LRU 回收，连接数不变；本地 SDK 排除正在异步上传的连接。已编译并仅烧录应用区，哈希校验成功，USB 读回 7.5.3-http。板端报告 HTTP 启动、STA 已连接 Egger（10.228.162.139）、开放热点 CABadge-dfc7 已开启。此次没有连接或修改电脑 WLAN。手机直连 http://192.168.4.1/ 复测待用户确认；USB 状态不是 HTTP 可访问证据，不宣称全部原因已排除。证据 outputs/cabadge-v7-http-20260923/hardware-verification.json、connection-fix.json；旧版本失败记录保留。

## 2026-09-23 连续上传失败（R44）

用户反馈两种网络方式均为首次上传成功、后续失败。USB只读取得7.5.3-http当前图库4张/容量31、PSRAM空闲6320396字节，未满；此时received=7221但phase=4，不能仅凭该快照判断失败的时序。代码检查发现HTTP每块接收使用零等待互斥锁，界面/状态短暂持锁即可中止上传。新增生产C服务回归：首次成功后，在后续上传第8192字节注入短暂锁竞争，旧版非200；修复HTTP调用最多等待100ms后连续3次通过，逐张读回且首张保留。USB/GUI仍零等待，不改LCD。证据outputs/cabadge-v7-upload-20260923/upload-regression.json；手机真实连续上传待复测，不以软件替身当作实板通过。

## 2026-09-23 7.5.4-upload 已烧录（R44）

修复连续上传中HTTP零等待获取图片互斥锁、碰上GUI/状态短暂持锁即中断的问题：仅HTTP调用等待最多100ms，USB及GUI取消路径继续零等待。生产服务C回归先复现第2次上传非200，修改后连续3次注入竞争均成功，逐张读回且旧图保留；同一网页连续上传红/绿/蓝三图不刷新验证通过，并保留恢复默认、取消和控制检查。均为本机软件验证，未连接电脑到热点。

最终源码重新构建成功，USB仅烧录应用区并校验哈希，实板读回7.5.4-upload。原4张自定义壁纸、当前选择5和CRC750792874保持。HTTP状态已启用，Egger链路IP10.228.162.139，恢复开放热点CABadge-b0a6。手机连续上传效果仍待用户复测，不保证已排除所有手机链路问题。证据outputs/cabadge-v7-upload-20260923/upload-regression.json、hardware-verification.json、service-test.log、web-test.log。工作台默认发布包同步。

## 2026-09-23 用户复测通过：连续上传（R44）

用户在7.5.4-upload烧录后明确反馈“修好了”，据此将本次“首次上传成功、后续无法上传”问题标记为用户实板复测通过。未提供具体上传次数、持续时间或分别采用的网络模式，不补写这些覆盖数据；R43两种网络入口的独立验收不据此扩大。保留此前失败、软件验证及烧录记录。本轮仅更新记录，未修改固件或再次烧录。

## 2026-09-23 应用页：二维 MC 地图与奶蛙矿工（R45）

用户要求新增应用入口，明确 MC 实时地图不是游戏，吧唧需显示可拖动、缩放的二维地图；矿工移植以提供的 frog-miner 仓库为准。基于当前 7.5.4-upload 增加 7.6.0-apps，保留既有 LCD/DMA、无线、手机管理和壁纸功能。地图直接读取 BlueMap 瓦片/玩家数据，游戏使用原仓库素材和原规则改编；音效及大型剧情动画未移植。

本机规则回归通过，ESP-IDF 6.1/LVGL 9.4 编译通过（应用 4,049,307 B / 7,340,032 B）。检查本地 LodePNG 返回绘图缓冲对象，修正 API 和释放方式；网络与解码在独立任务，主要图像数据放 PSRAM。烧录前 USB 实测 7.5.4-upload，图库 6 张 [2,3,4,5,6,7]，选择 7，CRC 1173692038；PC 网络未改变。新固件实板加载与目视交互待测，不以本机回归判实屏通过。证据 outputs/cabadge-v7-apps-20260923/before-flash.json，规则及限制见 firmware-v7/APPS.md。

R45 首轮失败及修复：7.6.0 首次实板可读玩家数据，但地形瓦片为 0；本机用真实 PNG 与相同 LodePNG 复现 error 83，拒绝的预测扩容为 3,013,525 B。为 LodePNG 字节向量增加“预测扩容失败后按实际所需容量重试”的回退，保留 2,100,000 B 分配上限；三张服务器瓦片（含负坐标和 LOD2）解码通过。当前构建脚本包含该补丁的重现步骤，未关闭 HTTPS 校验。

R45 最终 USB 实板复测：重新构建并仅烧录应用区，哈希校验通过；读回 7.6.0-apps。主世界初始视野实际加载 4 张地形瓦片，玩家 JSON 返回 1 名在线玩家，无地图错误。地图加载期间 PSRAM 历史最低空闲 736,748 B，退出后空闲 6,187,200 B；回到壁纸时内部 RAM 空闲 72,747 B。游戏采样约 8.35 秒，渲染约 26.12 次/秒，LCD 提交约 26.24 次/秒，这是无实际出钩输入时的实板计数，不是液晶扫描频率或满负载游戏结论。原图库 6 张 [2,3,4,5,6,7]、当前选择 7、CRC 1173692038 与烧录前一致。测试未修改电脑 WLAN。屏幕留在应用入口。

地图手指拖动、按钮缩放、维度切换、游戏触控命中和目视撕裂仍待用户验收；没有用模拟器代替实屏。证据 outputs/cabadge-v7-apps-20260923/hardware-verification.json、apps-runtime.json、apps-runtime-png-failed.json、build.log、flash.log；功能范围及改编限制见 firmware-v7/APPS.md。

## 2026-09-23 Grok 表情球及全屏修正（R46）

用户要求移植 Grok Ball，明确不要自旋和彩带。7.6.1 原生版已编译并仅烧录应用区；USB 进入/退出、息屏停止绘制、唤醒恢复、PSRAM 回收和图库保持通过，约 28.32 次/秒渲染及 LCD 提交。用户提供实体照片，确认图像实际显示，但明确指出未铺满：原先 256×256 图像中的球体直径约 240 像素，属于尺寸实现问题，不能记为最终视觉验收通过。

7.6.2-grok 将图像改为 360×360、球面半径 180、位置 (0,0)，眼睛同比放大，取消整幅上下移动造成边缘留白；普通表情仅刷新新旧眼睛包围区域，配色改变全图刷新。两块图像缓存共 518400 B，明确放 PSRAM。保留 25 组原始眼形和 32 状态数据；原版复杂序列非逐项复刻，无 JS 引擎，无新增任务。长按显隐操作，轻点切换，拖动注视。详情 firmware-v7/GROK.md；BlueMap 优化继续搁置。

最终 ESP-IDF 6.1 / LVGL 9.4 编译通过，应用区写入和哈希校验通过，USB 读回 7.6.2-grok。扫描转换测试覆盖 32 配色、25 眼形和 5 个裁切偏移，缓冲哨兵通过；未运行模拟器。实板 USB 自动采样：渲染及 LCD 提交约 27.98 次/秒（不是面板扫描频率）；表情页 PSRAM 空闲 5663612 B，末次退出 6187908 B；两轮退出后内存差在检查阈值内。息屏期间无新增绘制，唤醒恢复。原图库条目、选择及 CRC 保持。最终留在 Grok 页面，工作台默认包同步至 outputs/cabadge-v7-grok-full-20260923。

实屏全屏贴边、长按/注视手感、连续切换与撕裂仍待用户确认；照片只覆盖旧版尺寸问题，不作为新版视觉证据。原始日志与 before.json、hardware-verification.json、render-test.log 均在该发布目录。7.6.0-apps 发布包保留，可仅回退应用区，不擦除壁纸/NVS。编译期间新中文字形使 56 号字体位图索引超限的失败已纠正：新增 Grok 字形只补入实际使用的 18 号字库，最终构建通过。

## 2026-09-23 亮度范围反馈与源码核对（R47）

用户反馈当前屏幕亮度从 10% 到 100% 变化幅度太小。核对当前 physical_display.c 的 backlight_duty：仍保留首板上限 brightness*51/100、10 位 PWM，因此 UI 10% 为 duty 5（约0.49%），UI 100% 为 duty 51（约4.98%）。这是代码计算，不是光学亮度实测，不能单凭该限制解释全部主观差异。另确认 badge_ui.c 的滑条 VALUE_CHANGED 只改数字及已隐藏的 dimmer，RELEASED 才提交真实背光，因此拖动中并不实时调背光。D03 仍没有背光导通电流测量记录。本轮未提高 PWM 上限、未修改固件、未烧录；后续需要核对背光额定参数和现有电路后确定工作范围，并修正滑条实时预览。

R47 实施与 USB 实板复测：查阅供应商模组规格书第11页，明确允许 LEDA 接3.3V串5.1Ω；PCB Q1 源极+3V3、漏极BL_SOURCE，R13=5.1Ω连接BL_SOURCE与LEDA，接法一致。基于此取消首板测试5%限制，改10位PWM平方映射，保留1kHz；这不是背光电流或温升已测结论。物理滑条拖动即时预览，松手才保存，失去按压/退出页面/息屏撤销预览；手机管理共用映射。LCD/DMA配置未变。

7.6.3-light最终编译通过，只烧录0x10000应用区并通过哈希校验。烧录前实际保存亮度100%，先调到20%以避免升级后突然全亮。USB逐级读取LEDC：10→10、25→64、50→256、75→575、100→1023、20→41，六档均符合新公式；息屏读回0、恢复41；图库条目/选择/CRC保持，最后保留20%。这是实板寄存器读回，不是光学亮度/示波器或电流测量。生产显示驱动回归通过（映射单调性、边界/息屏、DMA生命周期、传输失败/触摸边界）。实体手指拖动实时效果、亮度观感和长期温升仍待用户复测。证据 outputs/cabadge-v7-light-20260923；实现/规格依据见 firmware-v7/BACKLIGHT.md。工作台默认包同步。

## 2026-09-23 Grok 应用列表入口遗漏修复（R48）

用户反馈应用页只有 MC 实时地图和奶蛙矿工，没有 Grok。USB 确认板上为7.6.3-light、当前在应用列表；核对实际 show_list 确实只有两个 button 调用。Grok 模块/路由已存在，但遗漏第三项的创建。R46的自动测试通过诊断直接打开Grok，只证明模块运行，未覆盖正常菜单入口；此前对用户说第三项已在列表中不准确，保留此失败并修正验证范围。

7.6.4-entry在 show_list 增加第三项Grok（60,236,240,54），沿用已有choose id=2→show_grok回调。补充 test_apps_menu.py，提取实际菜单构造与分发函数，验证三项存在、不重叠和点击路由，回归通过；不以此代替实屏点击。顺带修正该模块分配失败提示中的问号乱码为英文。

最终编译通过、只写0x10000应用区、哈希校验通过，USB读回7.6.4-entry并确认应用列表page=0。本轮读回亮度50%、PWM256；亮度全范围修正保持，未改回旧测试档位。最后停在应用列表供用户确认第三项；实际目视与手指点击仍待用户反馈。证据 outputs/cabadge-v7-entry-20260923 的build.log、flash.log、menu-test.log、hardware-verification.json。工作台默认包已同步。

## 2026-09-23 全场景帧率审计进行中（R49）

当前实板版本 7.6.4-entry。本轮暂未修改生产源码、未编译或烧录。用户要求覆盖全部使用场景；现有自动基线不代表全场景验收，真实触摸、手机传输和连接场景仍需分组采样。

首批 USB 运行计数：静态展示 0 次/秒内容提交（正常无变化）；Grok 两次分别 26.83、26.81 次/秒 LCD 提交，主任务单核心 CPU 93.98%、94.33%，core1 空闲约95.6%～95.8%；平均 LVGL render 5.18/5.21ms，Flush 1.90/1.95ms。GUI工作段约94%，包含自定义定时器；render事件计时不包含 Grok 自行生成像素，因此不能把5ms当作完整画面生成耗时。Grok 自定义扫描转换和整图 memcpy 是待进一步分段量化的热点，不能直接称已测得各函数耗时。

自动壁纸列表、抽屉、名片往返场景窗口平均 LCD 提交分别11.11、23.30、19.89次/秒；这些包含自动触发间隔/静止段，不作为纯动画瞬时FPS。USB采样期间USB工作墙钟占比约1.1%～1.8%，未发现USB传画面负载证据。LCD提交率不等于面板扫描频率，未取得目视撕裂或真实触摸延迟结论。

证据：outputs/fps-audit-20260923/baseline.json、raw.json、baseline.py。扩展自动场景和真实手指操作继续记录到同目录，未完成项必须保留待测。不得将诊断直达页面记为正常菜单入口已验证，也不得把静态游戏当作出钩/结算完整覆盖。用户已表示方便配合接下来的手动分组操作。

R49 扩展采样：实板地图加载返回 error=3、tiles=3、players=1；按 app_service.c/get_tile 与 apps.c 的错误映射属于部分地形未加载，不能记为地图通过，下载/解码具体原因尚未区分。设置自动往返及 Wi-Fi/BLE 扫描负载等数据保存在 extended.json、extended-raw.jsonl；各项覆盖及待测项见同目录 COVERAGE.md。真实触摸分组尚未完成。

R49 第一组真实操作：用户报告“第一组完成”，范围为展示/名片拖动、上下抽屉、壁纸列表/预览返回、设置子页与亮度滑条。采样窗口 131.77 秒，包含阅读、停顿及操作，窗口平均内容提交 8.01 次/秒，不能当作动画运行帧率。内部RAM最低空闲 66543 B，PSRAM最低空闲 5668656 B。原始记录 manual-raw.jsonl，标签01_navigation_touch；汇总manual-summary.json。用户未报告具体视觉异常，也未明确确认无撕裂/无误触，因此只记操作完成，不记全部体验通过。下一组将分应用独立标记。

R49 Grok真实操作：用户报告“Grok完成”；02_grok_touch窗口91.03秒，含进入/退出及停顿，平均内容提交10.69次/秒，不等于Grok动画运行FPS。内部RAM最低空闲64003B，PSRAM最低空闲5144360B。尚无用户明确的无撕裂/无卡顿确认。用户明确要求剩下地图和矿工不用测，本轮停止这两个应用后续手动测试；已有自动数据保留，不能标成完整通过。后续仅继续无线与手机上传负载。

R49 阶段收尾：用户要求无线及上传组也不用测，已停止manual采样并关闭COM3。03_sta_upload_touch仅为等待标签，不计上传覆盖。未改生产源码或烧录。设置往返绘制均值55～66ms、传屏约17～18ms；Grok主任务约94%单核心而LVGL绘制约5.2ms，需分段确认自定义像素生成耗时；33ms应用/内置动画timer也是已确认限制。完整证据、口径与未测限制见outputs/fps-audit-20260923/REPORT.md和COVERAGE.md。不是所有场景通过，不承诺已解决卡顿。

## 2026-09-23 官方双软件绘制线程对照（R50）

用户同意逐步实施，每完成一步报告。第一步7.6.5-draw2，仅启用ESP平台LV_OS_FREERTOS与两个软件绘制单元，LVGL组件增加freertos依赖；构建暂存适配atomic.h→freertos/atomic.h，未改上游vendor源。首编包含路径失败保留日志，修正后构建SUCCESS；显示DMA生命周期与应用入口回归通过。未改QSPI40MHz、刷新周期、Grok算法或显示缓冲所有权。发布目录outputs/cabadge-v7-draw2-20260923；此时正在烧录/待测，不能提前判性能提升或防撕裂通过。

R50第一步完成：候选双绘制线程成功运行但性能退步，已恢复7.6.4-entry，恢复版同脚本七场景完成。设置/连接原版15.37→候选8.00次/秒，设置/显示11.47→5.45，设置/设备信息12.33→7.05，抽屉22.99→20.51，Grok27.84→27.31；窗口平均不等于瞬时/面板FPS。候选没有保留为当前固件。壁纸状态一致、亮度86保持，COM3已释放。详见outputs/cabadge-v7-draw2-20260923/RESULT.md；候选视觉未验收，原版目视也不以自动计数替代。

## R51 — 2026-09-23 官方 LVGL Adapter 迁移（进行中）

用户要求底层切换至官方 esp_lvgl_adapter。旧版 7.6.4-entry 已通过 COM3 确认，亮度86；迁移前状态及同轮9场景基线保存在 outputs/cabadge-v7-adapter-20260923/before.json、baseline/。基线包含静止、设置/连接、显示、信息、抽屉、壁纸、名片、Grok、退出，不包含用户此前取消的地图/矿工/手机上传人工验收。

候选7.7.0-adapter锁定 esp_lvgl_adapter 0.7.1、esp_lcd_st77916 2.0.2、LVGL 9.4.0、ESP-IDF 6.1。使用官方显示注册/双PSRAM绘图缓冲/GUI调度/触摸注册/esp_lcd SPI DMA；保留屏幕原始初始化表、CST816D寄存器读取、业务服务。移除自建LCD worker，所有UI更新由Adapter任务处理。TE仍未布线，不启用TE_SYNC。构建及主机生命周期检查已通过，最终构建进行中，尚未烧录与实屏验收；不预判防撕裂或性能提升。

### R51 追加：2026-09-23 Adapter 显示基线统计

7.7.0-adapter 已烧录；本轮仅新增可编译关闭的 display_perf 聚合统计并烧录统计包。SDK 配置与前一迁移包逐字节一致，共享 UI 源码哈希一致。CPU240/QSPI40MHz/queue2/双PSRAM缓冲/PARTIAL/display16ms 均未调参。构建成功、应用烧录 hash verified；计时分离和原有 DMA 生命周期主机检查通过。

用户确认保持不触摸后，受控实板有效窗口约10–11秒/场景：主页0次完整提交/秒；抽屉19.71；设置↔连接10.11；设置↔显示7.44；壁纸切换11.87；Grok25.11；退出后主页0。数字是窗口平均 refresh/DMA完整提交率，不是面板扫描Hz；切换场景含400ms触发间隔。设置连接/显示绘制均值58.86/48.35ms，flush回调占用17.58/18.17ms，panel提交至DMA完成13.71/14.19ms；这些区间重叠，不能相加。Grok渲染5.97ms、完成1.56ms、CPU1约95.62%；自定义像素生成不在LVGL render事件计时内。

证据：outputs/display-audit-20260923/AUDIT.md、raw.jsonl、summary.json、build.log、flash.log。BlueMap不测；USB虚拟屏已移除、开启场景N/A；动态壁纸未实现，不以Grok冒充。真实列表滚动待手动采样，防撕裂与长期泄漏尚未验收。此前受触摸干扰的迁移后数据保留并排除。统计开启/关闭均未替换工作台稳定包。

R51 用户目视反馈：已查看当前实板 7.7.0-adapter，报告“显示和触摸正常，无明显异常”；提问范围包含转场撕裂、重复画面和触控异常。记录为本次目视反馈，不扩展为 TE 同步、所有场景或长期无撕裂验收；未提供仪器测量或持续时长。

### R52：2026-09-23 Reduce Motion 单变量 A/B 实板

仅增加每次转场统计，显示配置不变，同一统计固件完成 OFF/ON 各设置↔连接10次往返、设置↔显示10次往返，总计80次单向完整转场，无中断。400ms相同触发节奏，未改动画/驱动。连接 OFF→ON：wall376.87→60.28ms，refresh5→1，累计render218.70→28.33ms，累计dirty648000→129600px。显示：wall251.35→63.09ms，refresh3→1，累计render93.85→30.75ms，累计dirty388800→129600px；页面切换调用65.88→1.75ms（OFF含双快照生成）。两组单帧dirty都100%，单flush提交→DMA完成约14.2ms。

证实这些设置转场的多帧全屏绘制及显示页准备是明显额外成本，不等于所有页面已优化；没有修改下一阶段结构。ON单帧无帧间隔样本，N/A，不能写0ms延迟。CPU1在转场活动窗口连接86.60→82.43%、显示88.17→82.94%，窗口时长不同。测试后已读回验证减少动态、息屏、亮度恢复原值；返回主页、释放COM3。

构建30.54s成功，应用烧录hash verified；计时分离及DMA生命周期主机检查通过。证据：outputs/reduce-motion-ab-20260923/REPORT.md、TABLES.md、results.json、raw.jsonl、audit-verification.json。显示参数SDK配置与前一阶段逐字节相同。手指滚动/撕裂不属于这次自动A/B验收结论，BlueMap不测。

### R53：2026-09-23 设置↔连接局部内容转场实板验收

仅此页面对改为固定360×360背景、(50,28)处250×272裁剪viewport及两块同尺寸内容；标题/返回继续随内容运动，离开恢复原parent/坐标。设置↔显示、其他应用、动画spring参数及驱动/内存/时钟配置均未改。SDK配置与R52逐字节一致。

初次统计暴露静止弹簧尾段没有新RENDER事件，旧观察器缺最后摘要（19条）或误报中断（4条）；失败原始结果保留outputs/local-connection-20260923/initial-observer，不当作有效成绩。补齐只读pending dirty/render及DMA/motion完成判断后，最终400ms节奏OFF/ON各10往返、共40单向，全部零中断。

OFF旧→新，每单向均值：refresh5→5.95，累计render218.70→200.99ms，render均值43.74→33.78ms，累计dirty648000→407680px，平均dirty100→52.87%，flush bytes1296000→815360B；DMA完成区间均值14.25→8.05ms，最差完成帧间隔91.31→69.13ms。119次refresh中首次进入1次全屏、其余118次局部bbox[50,28,299,299]。最大dirty仍100%，不得隐去首帧。CPU1 busy86.60→90.24%，没有CPU占比下降结论。ON每次1个局部refresh，render25.97ms；单帧间隔N/A。

构建28.07s成功、0x10000应用烧录hash verified；viewport生命周期100轮、计时、DMA及显示路径四项代码检查通过。用户本轮明确反馈“看到了，显示正常”，记为当前目视正常，非所有场景或长期无撕裂认证。减少动态/息屏/亮度已读回恢复，COM3已关闭。完整对象树、对比及边界见outputs/local-connection-20260923/REPORT.md，原始results.json/raw.jsonl；已停止，不推广到其他页面。

### R54：2026-09-23 Draw Unit 1/2 单变量实板对照

前置审计发现原LVGL为LV_OS_NONE，数量1来自默认宏，未启用LVGL绘制线程；仅改2会#error。用户明确批准两组统一启用LVGL FreeRTOS及必要编译适配后重新测A。A=FreeRTOS+1、B=FreeRTOS+2，不用R53 OS_NONE数值冒充A。有效compiler预处理宏已归档，两个sdkconfig仅数量1/2不同，UI/Grok/服务及统计源一致；未改驱动/缓存/PSRAM/affinity/动画。

A/B均400ms节奏设置↔连接10往返、20完整单向且零中断，再测Grok。设置平均render22.975→24.449ms，累计render158.525→166.255ms/单向，wall317.602→322.943ms；max render34.335→32.469ms，worst完成帧间隔59.799→57.723ms，平均间隔44.425→45.857ms。平均dirty52.814%→52.819%，实际局部bbox同为250×272；138→136次refresh，各1全屏，其余局部，几何不变。CPU0活动段41.23→52.74%、CPU1 65.82→84.46%。B两个swdraw任务确实参与，优先级3、无绑核、各8192B栈；CPU增多不等于性能提升。

启动后首读internal空闲75775→67395B，设置结束73919→65571B，常驻多占约8.2KiB；整轮heap历史最低49340→27652B（包括启动/预热，非仅转场瞬时值；不将差额全归因栈）。最大连续internal采样仍31744B，PSRAM同阶段基本相同。Grok提交25.687→25.590/s、render5.907→6.093ms，B第二worker在该窗口CPU增量0，未见收益。

A/B完整构建143.61/143.96s成功、应用烧录均hash verified；计时/局部对象/DMA/物理路径四项检查通过。判定不推荐2默认开启，最终恢复已测A（FreeRTOS+1，不是原OS_NONE），恢复烧录hash verified，实板任务表确认仅1 worker；亮度29、减少动态/息屏/壁纸等与测试前一致，COM3释放。无新用户目视防撕裂验收，无长期压力结论。详细审计、表格、有效宏和原始记录：outputs/draw-unit-ab-20260923/REPORT.md、AUDIT.md、unit1/、unit2/。本阶段停止，不继续改其他变量。

### R55：2026-09-23 设置↔连接预生成RGB565缓存转场

保持R54最后FreeRTOS+1 draw worker，不使用更早OS_NONE的33.78ms冒充同配置基线。真实控件A和缓存图片B同源码、同SDK、同250×272区域，仅CABADGE_CONNECTION_BITMAP=0/1不同；同400ms节奏各10往返20单向，全部完成、零中断。两组均空闲预备容器，因此均无首帧全屏差异。未改驱动、XIP/cache/QSPI、动画参数或其他页面。

A→B：avg render22.30→14.20ms、max28.92→22.15ms，累计render157.22→132.10ms/单向；refresh7.05→9.30，dirty同为52.469%，累计pixels479400→632400、flush bytes958800→1264800。DMA均值7.951→7.979ms，平均完成间隔43.65→35.84ms、worst58.55→52.47ms；wall320.22→333.81ms，没有缩短。更多刷新使传输量增加，不能把单帧改善当作全部转场同比加速。CPU0 38.63→36.48%、CPU1 66.67→65.53%。

采用LVGL9.4 snapshot_to_draw_buf，250×272 RGB565 PSRAM每张136000B、共272000B。GUI空闲每次最多生成一张，触摸/运动期间跳过，点击只查READY，MISS沿用真实控件动画；动画时真实两树隐藏、结束恢复，缓存不被写入。预热4次build共76.795ms，单次均值19.199/max19.756ms；正式20转场全命中、0 miss、0 rebuild。结束PSRAM空闲减少272008B，internal减少448B，最大internal块31744B不变。

A构建146.81s成功；首次B CMake复用旧环境开关，预处理检查发现仍为0，未烧录，失败证据保留stale-build。强制重生成后B构建72.98s成功，宏1确认，两版烧录hash verified。代码生命周期检查通过，实板Reduce Motion bypass、状态失效后两张空闲重建、固定缓存大小及退出检查通过；脚本恢复设置并关闭COM3。用户明确反馈“显示和点击正常，没有残影”，记为当前实屏和点击验收，不扩展为长期全场景防撕裂保证。

当前保留缓存B。完整实现/失效范围/测试边界及回退见outputs/bitmap-transition-20260923/REPORT.md，原始widgets/、bitmap/、functional.json，主结果summary.json。当前缓存内标题/按钮静态，未来新增独立动态文本须接入失效判断，不是通用LVGL setter自动拦截。本阶段已停止。

### R56：2026-09-23 缓存转场精确帧流水线（仅观测）

保持R55缓存版共享UI/app哈希与全部sdkconfig不变；未改UI、动效、缓存、QSPI/queue、buffer、draw unit、XIP/cache或调度。新增CABADGE_DISPLAY_PERF条件下内存事件记录，转场结束后批量导出；20次完整单向、400ms节奏、Reduce Motion OFF；185帧、165个同转场连续间隔、零丢失/中断、20缓存命中/零重建。最终构建101.26s成功且无warning/error，烧应用Hash verified，四项软件检查PASS。首次编译的包装器等待参数类型错误已修正，保留失败日志。

原GUI消费完成口径35.803ms复现R55的35.839ms；直接DMA回调完成间隔35.531ms。统一165区间：render13.351ms、render到flush事件0.207ms、flush入口到提交返回9.253ms（前处理3.033+panel提交6.219）、提交后DMA1.772ms、ready开销0.032ms、DMA完成后至下一render10.331ms，总34.945ms/max50.681ms。所有185帧render均值13.841/max21.179ms。原约8ms为draw入口→DMA，包含提交中的等待，不能当提交返回后额外8ms。

间隙主要为service_poll4.482ms、触摸1.820ms、UI tick1.939ms、refresh准备1.744ms；handler外剩余均值0.164ms（含调度，非纯sleep）。最差间隔里service占16.834ms，未进一步拆分或归咎网络。SDK源码按last_run执行起点计period，过期返回0，不存在强制跳到下一16ms格点。Adapter仍夹到1–5ms后等待；216次handler中210次返回0。双PSRAM buf交替但本场景165次render(N+1)/DMA(N)重叠为0；SPI实际两个分块在途、每flush6块；回收描述符等待已含于提交。结论为绘制、flush前处理/分块提交及GUI回调/调度组合，不是单纯LCD速度或额外16ms。

本轮诊断常驻约8KiB内部RAM；结束internal free65271/min29384/largest31744B，PSRAM free5396944/min5395020B；最低值含启动全过程，不把低水位差全部归诊断。保持现有参数，恢复用户设置、返回主页、释放COM3。本轮未新增目视防撕裂验收；完整审计与原始数据：outputs/frame-pipeline-20260923/REPORT.md、connection.json、timeline-summary.json。阶段已停止，未执行任何性能优化。

### R57：2026-09-23 7.7.1-cached 正式包范围说明及复测

7.7.1仅正式集成设置↔连接缓存，并非全局缓存版。outputs/cabadge-v7.7.1-cached/hardware-verification.json记录20次命中、动画中Reduce Motion终态恢复、空闲重建及页面生命周期自动检查通过。第一轮读管理状态过早及亮度恢复断言未完成，保留first-check-inconclusive.log，随后轮询实际状态完成复测。构建与应用烧录hash通过；不将R55的目视确认扩大到其他页面。用户指出覆盖不足，本轮后续按全UI推广处理。

### R58：2026-09-23 通用转场缓存推广（进行中）

新增GUI任务拥有的ui_transition_cache，RGB565 PSRAM懒分配、1.25MiB上限、非活动LRU淘汰、单次空闲最多一张、MISS真实控件回退。诊断7.8.0-cache构建和烧录hash verified；sdkconfig.verified.h与7.7.1逐字一致。初编译两项错误（误导缩进和遗漏lv_cache头文件）已修正，未将失败构建烧录。主机生产逻辑100次缓存生命周期和4页reparent/restore检查、显示完成所有权检查通过。

实板对照先完成控制中心、设置↔连接，各A/B20次完整转场无中断；平均render分别16.64→14.18ms和21.95→13.97ms。功能面板400ms触发在真实控件组中产生10次未结束即反向，保留functions-widgets初始数据，不判通过。下一组统一600ms触发，不改变动画参数。其他页面仍在测量；尚无本轮用户目视/触摸验收。原始数据outputs/global-transition-20260923，对照采用同一固件缓存启用/禁用开关。

### R59：2026-09-23 Direct Compositor 全系统候选（进行中）

在通用缓存基础上新增 direct compositor 与 physical_display 显示权交接；仅暂停显示刷新/失效通知，输入、业务和动画计时继续运行。两个 360×16×2 内部 DMA staging 块仅转场期间分配；缓存同时保留 LVGL/native 字节序，两份总像素上限2MiB。未改变 sdkconfig：与7.8候选逐字相同，分区二进制相同。候选编译成功、烧应用 hash verified。首版 UI_VERSION 仍显示7.8.0-cache（项目/发布版本7.9.0-direct），下一候选修正标识，不能据此误判已回滚。

stride/圆角/块边界生产像素代码检查、缓存生命周期、DMA完成隔离及局部对象层级检查通过。首轮自动探测发现重复调用当前页面时过早结束 compositor，产生63条碎片化转场记录；数据保留 direct-smoke.json，不作为有效A/B。已在源码将接管结束放到页面确实变化之后，待重新编译复测。用户随后明确反馈“目前显示正常”；只记录本次目视反馈，不扩大为全页面点击/撕裂专项通过。全页面对照与动态App恢复测试未完成。

#### R59 续：候选修正与分组复测

初轮还发现两项影响测量的真实路径问题：隐藏的 Wi-Fi 密码框被反复取消导致缓存不断失效；LVGL layout REFR_REQUEST 可重新启动被暂停的 display timer。已分别在共享取消入口与物理显示刷新包装器修正；包装器在 Direct 所有权期间不进入 LVGL renderer。一次编译误用不存在的 lv_timer_get_cb，编译失败未烧录；按本地 LVGL 9.4 私有 timer 结构读取原 callback 后编译通过。

候选5完成连接、显示、设备信息、控制/功能面板、Wi-Fi、BLE等同固件 A/B，但手机管理组发生串口响应超时，不能判全系统通过。审查发现取消时普通排队帧和 STOP 均确认同一 semaphore 的竞态；现仅 STOP 响应确认，并增加生产逻辑回归。不能仅凭源码发现认定该竞态是实板超时唯一原因。候选7重新烧录 hash verified，手机管理、应用列表、名片各完成20次 Direct 转场且无 DMA 错误；名片原40条分裂记录由无位移抽屉误接管造成，亦已修正。壁纸候选7仅10/20 Direct命中，进入时无条件失效已定位，候选8改为实际图片/滚动变化才失效；同指针缩略图更新仍显式失效。

候选8编译31.18秒成功、应用 hash verified，开始13组全覆盖同固件 A/B；每组20次单向、双方统一600ms自动触发，未改动画持续时间/easing。新增功能面板↔设置/连接场景，保留完整设置页缓存并在子树重挂局部viewport时暂停重建，防止误缓存空壳。软件生产逻辑：cache生命周期、100次reparent/restore、stride/圆角分块、STOP单确认、DMA/刷新所有权检查均PASS。完整结果及后续压力测试仍待批次完成。用户的“目前显示正常”只对应其当时看到的候选，不代表本轮所有页面点击、无撕裂已人工通过。

#### R59 暂停点（用户要求“不测了”）

候选8完成13组同固件LVGL Cache/Direct A/B，每组20次单向；Direct总259/260命中，设置↔显示1次回退，汇总无DMA错误。设置↔连接完成间隔33.42→12.75ms，控制中心31.98→20.95ms，手机管理66.45→29.04ms；这些是提交完成间隔，不是面板扫描Hz。完整原始数据和口径见outputs/global-transition-20260923/DIRECT_BENCH.md、direct-summary.json及ab-*.json。

候选9仅追加Direct期间透明输入拦截与既有主页/抽屉手势转交，已烧应用hash verified；当前板上仍为此7.9.0-direct诊断候选。随后压力测试被用户主动停止，不能判冷缓存/Reduce Motion/动态App全套完成。已终止脚本、停止板上自动场景、返回主页(page0)、恢复正常cache模式与400ms诊断默认节奏，compositor active=false，COM3已释放，证据stopped-by-user.json。期间正式包已编译成功（17.38秒），但未烧录、未完成正式包实板验收，工作台默认发布指向未改。后续不继续测试或烧录，等待用户新指示。

## 2026-09-23 R60：7.9.1-prewarm 缓存生命周期优化与 Flash 可用空间

按用户新要求直接优化、编译、烧录，仅做短检查，不再跑 A/B/20次循环。原冷启动原因代码与此前生命周期日志显示：双副本压缩有效容量、子页离开主动 forget、低频页面挤占、状态轮询过度失效。当前改为单份 LCD-native RGB565（构建时原地换字节）；2 MiB 字节预算、优先级/LRU/hot保留、真实导航下一跳预热、visual revision 与 full/local alias。MISS回退真实控件，不在点击中截图；显示参数/Direct renderer/动画参数未改。动态应用暂停预热并按需要回收冷缓存，退出恢复导航预热。

Flash L2未启用，占用0 B：现有壁纸分区保留legacy迁移区及31个槽后仅余68 KiB，不能安全容纳典型136000 B缓存；未改分区/未牺牲用户壁纸。设备信息新增实际Flash总容量与壁纸可用MB/空槽张数，上传/删除后由库发布更新，仅数值变化才失效缓存。可用量是持久壁纸槽的可写像素容量，不把固件占用区算成用户空闲空间。

最终构建33.24秒成功，无编译warning；COM3应用0x10000烧录，esptool hash verified。native-cache/viewport/compositor生产逻辑小检查通过；新增存储API后management_service_test重新编译并通过。最初cmake不在PATH，改用现有绝对路径重新编译，未把旧exe输出作为本轮证据。
短导航检查涵盖主页/控制中心/功能面板/设置/显示/连接/设备信息返回，及Grok、BlueMap入口返回。USB报告版本7.9.1-prewarm，正常uptime递增，Direct命中与MISS回退均出现，DMA errors=0，结束owner回收active=false/page0；COM3释放。没有进行长测或网络地图加载验收。
结束时内部RAM free 88111 B、PSRAM free 5078856 B，历史内部最小15248 B、PSRAM最小3505388 B；这是短检查观测，不代表长时安全余量或无泄漏证明。缓存copies=1/budget=2097152。用户目视无花屏/残影、点击手感、首次进入流畅度待确认，不能沿用旧固件反馈判定本版通过。
证据：outputs/cabadge-v7.9.1-prewarm/basic-check.json、hardware-verification.json；F:/CABadgeBuild/temp/cache-prewarm-storage-build.log、cache-prewarm-flash.log。工作台默认包已指向7.9.1-prewarm。

## 2026-09-23 R61：应用退出后卡顿，短检查定位（未修改/未烧录）

用户反馈奶蛙矿工、MC地图退出后卡顿。按当前不跑大型benchmark的要求，仅短暂进入返回查看资源与缓存事件。矿工退出前后内部RAM可用54283→92339 B，PSRAM同为4288440 B；代码tick在visible=false时返回，clear_panel删除控件。不能据此认定PSRAM泄漏，也未解释矿工全部主观卡顿。
地图clear_panel提前reserve 6 MiB，日志直接出现APP_MEMORY_RESERVE淘汰设备信息/设置/控制中心/主页/功能面板；返回主页出现CACHE_MISS，随后四页分别耗时25.537/34.952/57.388/26.139 ms重建。已证实地图退出后的冷缓存回退与GUI重建，不是已证实内存泄漏。地图已有取消serial、worker释放tiles路径，但网络/PNG进行中的调用不保证立即中断，仍是待定位风险。未修改源码、未重新烧录，设备返回主页、串口释放。证据outputs/cabadge-v7.9.1-prewarm/app-return-inspection.json。

## 2026-09-23 R62：仅RAM审计（7.9.1-prewarm）

本轮用户明确只要RAM数据，不修改代码、不A/B。一次重启，主页/预热/无线/Grok/BlueMap首次请求/退出主页六场景通过既有USB接口采集；地图一次请求短采样，不反复切页。另开关控制中心一次以列出懒创建transition任务。
采样最低PSRAM free729224 B，地图完整请求后历史min697992 B；Internal历史min17088 B、DMA内部min9300 B。地图结果error3/tiles3/players1，不能断言OOM。回主页PSRAM free5078856 B、largest4980736 B，与开机预热一致，未见持续PSRAM泄漏。
报告RAM_AUDIT.md含任务栈余量、分配清单、DRAM64040 B/内部代码120763 B与组件排行。wifi allocated stack仍待核实，表中未猜值；现有capability带8BIT/INTERNAL过滤，min是boot累计，不能误当单场景峰值。
idf.py size/size-components最终返回0（早期依赖/路径错误已记录）；最终ELF与发布包SHA256一致未重链接，未烧录。官方esp_idf_size独立结果及ELF sections交叉证据在outputs/ram-audit-20260923；idf命令存在分类警告，不将其说成无warning。设备回主页、串口释放。未进行优化。

## 2026-09-23 R63：7.9.2-memory 内存架构优化与基本检查

按用户要求不做 A/B/多轮 benchmark。BlueMap 专用解码改用 vendored MIT Pngle，16 KiB HTTP 分块输入、PSRAM 解压窗口/扫描线、直接采样128×128 RGB565；保留全文件完整性/CRC验证，不保存完整RGBA或下半图。其他 LodePNG/JPEG 路径保留。地图 framebuffer 延后到 HTTP/TLS 清理之后分配，保留GUI新旧交接；取消由serial和worker完成状态确认，不用固定延时。后台低内存时延后启动，地图工作未完成不启动Direct返回转场。

清除旧诊断3×2072 B静态数组，最终静态RAM57964 B（旧64040 B）；栈未缩减。内置两张壁纸直接用Flash原图，去掉518400 B常驻复制；名片保留真实控件，统一转场缓存负责唯一快照，去掉独立259200 B副本。用户缩略图为5张LRU+至多1张后台待提交图，三张可见卡片固定，逐两行读Flash并校验整图CRC，generation校验避免删除/替换后的旧图提交。NORMAL转场预算3MiB、HIGH软目标1MiB（保留hot/current，故可略超）、CRITICAL512KiB；低内存停止预热，退出worker完成后恢复导航预热。

中间候选已确认地图4瓦片/1玩家/error0，PSRAM改善，但Internal/DMA历史min仍15248/7460 B，未将其当成安全完成。继续核查发现普通LCD自动PSRAM bounce与Direct staging交接峰值。最终采用两者互斥共用2×11520 B内部DMA staging；普通刷新逐16行copy/submit、真实DMA drain后复用，只有最终块完成通知Adapter/LVGL；Direct不再重复分配。此内存池常驻23040 B，换掉普通路径理论最多49104 B自动bounce；没有改QSPI40MHz、queue2、max_transfer_sz、双PSRAM draw buffer、DRAW_UNIT1、XIP/cache、动画参数。sdkconfig与7.9.1逐字节相同。新分块的实屏撕裂/残影仍需用户目视，不能由软件检查代替。

最终编译SUCCESS（29.73s，构建日志无warning/error），应用区0x10000烧录并哈希校验。主机最小检查：两张真实BlueMap PNG碎片输入/独立采样对照/CRC与截断拒绝通过；生产DMA staging生命周期/单次最终flush_ready/错误排空、compositor stride/clip/取消ACK通过。实板一次基本检查：主页、设置→连接→设置、壁纸列表、Grok、BlueMap→主页；地图4瓦片、1玩家、error0，Wi-Fi已连接/error0、BLE广播/error0，Direct errors0；返回page0，串口释放。8张用户壁纸与selected9/CRC3084797259未变。未进行真实手指滚动、BLE对端连接或目视画面验收，也不把一次检查称作长期无泄漏保证。

| 场景 | Internal free/min B | DMA free/min B | PSRAM free/min B |
|---|---|---|---|
| 主页稳定 | 87815 / 45612 | 80027 / 37824 | 6324092 / 6265916 |
| 地图加载结束 | 69703 / 39828 | 61915 / 32040 | 5782048 / 4219412 |
| 退出地图回主页 | 71915 / 39828 | 64127 / 32040 | 5916080 / 4219412 |

min为本次开机历史低水位，含之前页面/Grok/预热，不能称为PNG函数精确峰值。地图期间1秒级采样当前free最低Internal66215/DMA58427/PSRAM5782048 B。退出PSRAM+transition-cache bytes=7360880 B，主页为7360892 B，相差12 B，当前空闲差异主要是更多导航缓存保留，未见本次地图像素泄漏。SDK能力口径仍INTERNAL|8BIT、DMA|INTERNAL、SPIRAM|8BIT。

发布及证据：outputs/cabadge-v7.9.2-memory（verification.json、basic-check.json、build.log、flash.log）。initial-basic-check.json是中间候选历史，不代表最终版；工作台默认包已切换7.9.2-memory。RAM_AUDIT.md保留旧版原始审计含义。回退可只烧outputs/cabadge-v7.9.1-prewarm/firmware.bin到0x10000，分区和壁纸数据未改。后续由用户实际体验，不再自动长测。

## 2026-09-23 R64：正式发布归档 v1.1.0（无新增实板测试）

用户要求将当前固件作为正式版推送 nbtca/CABadge。检查发现已有v1.0（7.3.7-mem），因此使用v1.1.0，内部固件版本仍7.9.2-memory。复用R63的应用/bootloader/partitions/ELF，逐项SHA256匹配verification.json，记录的关键UI和内存源码哈希匹配当前文件。整理源码快照、安装/旧版分区升级说明、第三方来源、固件与调试ZIP及校验文件。本轮不重新编译、不连接设备、不烧录、不新增功能或测试结论。R63人工目视及长期验证待测项继续保留。发布地址 https://github.com/nbtca/CABadge/releases/tag/v1.1.0 ，附件本地outputs/release-v1.1.0。

## 2026-09-23 R65：复刻仓库精简（仅软件验证，无新增实板结论）

按用户要求删除65个无当前构建依赖的历史报告、旧模拟器、旧投屏界面与废弃测试；保留当前固件、硬件工程/库/模型、完整制造MANIFEST集合、素材来源/许可证和三项内存/DMA/compositor检查。旧资料仍在精简前提交d1fe971及发布标签中。为避免破坏工作台，从旧viewer原样提取packet/Decoder到usb_screen/framing.py；更新导入并通过分包/CRC恢复/边界自检与workbench模块导入检查。

生成器不再读取已删除的simulator/bridge，依赖初始化不再下载SDL2。板端C/H、生成资源、分区及显示参数未改。以现有build.ps1逻辑导出到独立临时目录F:/CABadgeBuild/temp/reproduction-build-check，完整构建SUCCESS（16.65s，静态RAM57964 B）；bootloader、partitions、firmware三BIN与正式7.9.2-memory SHA256全部相同。三个最小宿主检查、仓库链接/语法/制造哈希、23个板端源文件和本地PCB模型引用检查通过。

未烧录、未运行实板probe、未覆盖正式包verification.json；无需给现用设备重复刷入相同BIN。此次只证明精简未破坏上述软件依赖，不新增触控/撕裂/长期稳定性结论。

## 2026-09-23 R66：BlueMap USB运行时诊断（7.9.3-mapdiag）

按用户要求只增加诊断，不优化BlueMap策略、不启用ESP_LOG/UART console、不向USB混入裸文本。现有type41新增0x0a+cursor查询，type42返回协议帧内JSON；64条PSRAM历史保存Tile和完整Refresh记录，GUI结果接收/丢弃均记录。串行Tile下载、每请求close、同刷新仅复用client对象的行为保持不变。PNG/downsample融合，记录合并feed耗时；TTFB为首个已解析header回调近似上界，不伪造DNS/TCP/TLS分阶段数据。

软件：完整编译SUCCESS（157.38s）；补充chunked零字节结束检测后增量构建SUCCESS（28.64s），两份构建日志无warning/error。静态RAM57976 B；CONFIG_ESP_CONSOLE_NONE、LOG_DEFAULT_LEVEL_NONE、DRAW_UNIT_CNT=1核对通过。实际C诊断history的空队列/覆盖/非破坏cursor/输出边界检查通过；PC协议分包/耗时计算/HIT缺失时间/Refresh格式自检通过。未改显示参数、分区或地图算法。

实板：首次烧录因COM3被已有serial.tools.miniterm占用而未开始；仅关闭该串口读取进程后重试，应用写入0x10000、Hash of data verified、复位成功。USB读回firmware=7.9.3-mapdiag；新诊断available=true，旧状态/运行时查询正常。启动约41.8s时Internal free87991/min45356 B，DMA free80203/min37568 B，PSRAM free6312824/min6254648 B，仅启动检查，非性能对照。

PC工具tools/map_perf_monitor.py自动识别COM3，3秒只读检查通过，日志生成F:/CABadgeBuild/logs/bluemap-20260923-224446-896043.log及同名jsonl。此时latest=0，没有自动进入地图，没有模拟Tile数据，没有进行循环benchmark。真实联网Tile耗时、拖动缩放与目视验收由用户手动采集；本轮不预判其结果。结束时串口关闭。

证据：outputs/cabadge-v7.9.3-mapdiag/verification.json与basic-check.json；F:/CABadgeBuild/logs/build-7.9.3-mapdiag.log、build-7.9.3-mapdiag-final.log、flash-7.9.3-mapdiag.log（占用失败）、flash-7.9.3-mapdiag-retry.log（成功）。原v1.1.0/7.9.2-memory发布附件保持不变。

## 2026-09-23 R67：BlueMap有界缓存、持久连接与两路渐进加载（7.9.4-mapfast）

本轮只优化地图加载。原slot顺序覆盖改为world/LOD/X/Z键的9张LRU（仍288 KiB），当前视口pin，60秒有效期保留。旧refresh取消不清空cache，完成HTTP和PNG的Tile仍由协调任务入缓存；退出地图才清理。每个HTTP client仅被其所属任务使用，完整body且服务器允许持久连接时不close，失效空闲socket重连一次；错误/未完成响应关闭。Pngle及16 KiB流式输入保留，不产生完整RGBA。

第一路复用badge_apps；最多新增一个8192 B栈的map_http1，退出释放连接/缓冲及任务。新任务门槛Internal72 KiB/DMA64 KiB/最大Internal块12 KiB/PSRAM1.5 MiB；Internal<40 KiB或DMA<32 KiB触发第二路收缩，未完成Tile可由第一路重试，不强占内存。固定小队列可复用。地图画布仍只有GUI持有的一张259200 B，patch最多16行/11520 B、队列1条；GUI内复制并局部invalidate，不让worker修改GUI正在读取的图片。触摸拖动期间暂停patch接收，旧serial丢弃。

初次基本检查发现badge_apps栈最低余量764 B，因此未直接交付该候选。将新增临时结果移到约3 KiB PSRAM scratch，退出释放，不增大任何任务栈；同时补上第二路完成后的及时派工及闲置低内存清理。最终编译SUCCESS（33.55s），静态RAM58264 B，无新增warning/error；cache的LRU/pin/键隔离、六档zoom/负坐标区域采样、诊断history与PC格式检查通过。普通console/log关闭，显示驱动参数不变。

COM3最终应用烧录0x10000，Hash of data verified，读回7.9.4-mapfast。最终仅一次地图进入/加载/返回：4张HTTP200、2路请求时间区间重叠；两路后续请求connects=0且reused=true，整次2次建连、3次复用（含玩家请求）。加载未完成时apps.loading=1、tiles=1，证明GUI已接受第一张Tile的渐进patch；最终tiles=4/players=1/error=0。初次候选的同一cache实现已在下一次自动刷新得到4 HIT/0 MISS，证据另存mapfast-initial-check.json，不作最终版本速度对照。

最终实板历史最低：Internal39828 B、DMA32040 B、PSRAM5718740 B，未回到旧17 KB/9 KB危险区。加载结束当前free为Internal59803/DMA52015/PSRAM5828520 B。badge_apps栈最低余量2236 B、map_http1为2840 B。返回主页后map_http1消失，free为Internal77371/DMA69583/PSRAM6310776 B；PSRAM回到同轮启动值6310776 B。此为一次基本检查，不是所有场景的最低余量保证；未强制制造低内存，未做长时间采样/A-B/循环压测，触摸目视/撕裂和快速取消的人工验收仍由用户体验。

证据：outputs/cabadge-v7.9.4-mapfast/basic-check.json含最终BIN哈希和少量诊断记录；F:/CABadgeBuild/logs/build-7.9.4-mapfast-release.log、flash-7.9.4-mapfast-final.log。中间候选数据为F:/CABadgeBuild/logs/mapfast-initial-check.json。结束回主页、释放COM3，原v1.1.0/7.9.2-memory产物未覆盖。

## 2026-09-23 R68：BlueMap 第二路重新准入与 Tile 生命周期修复（7.9.5-mapcache）

用户反馈7.9.4首次两路并发后长期max_scheduled=1，首批4张Tile下一次同区域全部MISS。复核bluemap-20260923-232537-389331.log：refresh1完成4张，refresh4请求同world/LOD/坐标时距首次完成不足60秒，排除正常TTL；app_service的world<0取消分支会map_cache_clear，UI退出及show_map重建均可触发。该旧行为修复为仅释放HTTP/worker/scratch和cache pins，成功Tile继续留在9项/288 KiB LRU。60秒地形重新验证不改，新增expired_tiles区别过期重载与无缓存。

第二路旧冷启动门槛72 KiB Internal/64 KiB DMA，存活门槛48/40 KiB，运行回收40/32 KiB；已知安全运行记录39828/32040 B也会撞运行门槛，且回收后已有第一路常驻资源使重建门槛难以达到。旧日志没有降级heap快照，无法逐次追溯当时是哪种门槛触发，以上是源码确认的错误机制。新版按尚未分配资源预留：新任务10 KiB（含8192 B栈/TCB/队列）、新HTTP路径14 KiB；运行安全底线Internal32 KiB/DMA24 KiB，第二路全新启动需要56/48 KiB及最大Internal块12 KiB、PSRAM1.5 MiB。已分配资源不重复预留。运行PSRAM底线512 KiB；真实低水位/分配失败仍回退单路，下一refresh重新判断，不沿用旧低水位标记。

每次refresh的USB二进制诊断新增requested_lanes/actual_lanes/fallback_reason/internal_free/dma_free/psram_free，PC工具转成一行可读摘要；actual_lanes表示准入容量（中途降级后为1），实际Tile重叠看max_scheduled，缓存全命中/单张MISS不等于内存降级。heap记录准入时或协调任务观察降级时的当前值，不是历史最低。没有开启UART/ESP_LOG。Pngle、16 KiB输入、Keep-Alive及显示链路保持不变。

软件检查：真实C缓存LRU/pin与退出解除pin后保留像素、第二路内存准入/低水位/碎片分支、USB诊断JSON与PC格式检查通过。完整编译/烧录与本轮实板结果待下方追加，不预判通过。

## 2026-09-23 R69：BlueMap 冷区下载与拖动缓存（7.9.6-mapcold）

在R68源码上继续修改。已开始的Tile若仍与新视野同world/LOD、距新中心最多2格且PSRAM空闲大于1 MiB，允许旧请求后台完成入缓存；明显远离、切换世界/LOD或内存紧张时仍可取消。所有旧serial结果沿用GUI序列号校验，不将旧patch写到新视野。HTTP读取改为每活动Tile一个PSRAM栈读取任务与两个8 KiB PSRAM槽；Pngle继续消费原16 KiB输入，网络读取可在解码期间进行，读取槽不足时自然背压。申请管线前要求PSRAM至少1.5 MiB，申请失败回退原同步读取。HTTP两路、Keep-Alive、Pngle、Direct Compositor与原内存保护不变。

Tile Cache上限从9增至20张，128×128 RGB565像素最多640 KiB，比原上限多352 KiB；PSRAM低于1 MiB时淘汰未pin旧Tile，退出地图时清理到至少1.5 MiB。两路都活动时双槽及读取栈另增加约44 KiB PSRAM，并增加两个短命读取任务及小队列的内部RAM开销。尚未做长时间或强制低内存验证，不将一次正常拖动推断为没有新增内存风险。

最小软件检查 `python -B firmware-v7/test_map_cache.py` 通过；固件构建SUCCESS（60.31秒，静态RAM 58808 B、Flash 4151795 B）。COM3只写0x10000应用分区，esptool报告`Hash of data verified`，USB状态读回firmware=7.9.6-mapcold。首次冷区refresh1为4 MISS/4下载，max_scheduled=2，建连2次、后续复用3次，result=0。用户按提示在实板打开BlueMap并完成一次快速拖动；诊断中refresh2已被新视野替代（result=-2），但2张已完成Tile进入缓存，下一次refresh4命中其中Tile，6张需求为4 HIT/2 MISS、result=0。refresh2与refresh4新增建连均为0，相关HTTP请求显示reused=true；本次可确认取消后未出现重连，不能从单次检查量化相对旧版的整体提速或长期取消率。

读取和解码独立任务实际运行：例如refresh1两路Tile的download_complete分别早于png_complete约226 ms、421 ms，期间累计解码时间各约2.43 s、3.08 s；这是重叠流水线证据，不把download_wall与decode耗时相加。refresh4准入快照Internal 54763 B、DMA 46975 B、PSRAM 5762912 B，未触发降级；这些是该时刻空闲值，不是历史最低值。用户只回复“完成”，未提供屏幕目视质量或长期稳定性结论。

证据：`outputs/cabadge-v7.9.6-mapcold/verification.json`、`F:/CABadgeBuild/build-7.9.6-mapcold.log`、`F:/CABadgeBuild/flash-7.9.6-mapcold.log`、`F:/CABadgeBuild/logs/bluemap-20260923-235421-978398.jsonl`。本轮未做A/B、循环压测或模拟器检查；v1.1.0/7.9.2-memory发布附件未动。

## 2026-09-24 R70：BlueMap LOD2/3 大PNG失败分类与接收吞吐（7.9.7-maplod）

先复核旧版USB日志：LOD2多张HTTP 200 Tile在只收到约300～490 KiB、`download_complete_us=0`且`png_complete_us=0`时以`result=-1`结束，网络API累计约11～16秒，失败字节数常是8 KiB整数倍。源码在读完HTTP body前有12秒整Tile墙钟限制，却把超时、读取、PNG和尺寸错误全部并为`-1`。这批有证据的LOD2失败主因是慢速接收撞总时限；旧记录无法证明历史上每一个`-1`都同因。服务器当前同坐标LOD2完整文件580446/607470 B，电脑直连下载分别约1.69/0.55秒、HTTP 200且Transfer-Encoding: chunked，排除这两个样本在服务器端只发送部分PNG。设备旧配置lwIP TCP接收窗口5760 B、接收邮箱6、HTTP client内部接收缓冲2048 B；TLS输入缓冲16384 B。

新版Tile结果拆为-10 HTTP、-11 READ、-12 TIMEOUT、-13 CONNECTION、-14 PNG_PARSE、-15 CRC、-16 DECODE、-17 SIZE、-18 OTHER，JSON另带静态错误说明和HTTP errno；-2取消、-3第二路内存回退、-4分配失败保留。整Tile总时限12→30秒；TCP接收窗口5760→11520 B、邮箱6→10、HTTP client接收缓冲2048→4096 B。现有每路8 KiB读取槽、16 KiB Pngle输入、两路并发、Keep-Alive、Tile Cache、Direct Compositor及内存降级逻辑未改。Pngle仍逐像素解码501×1002源图并采样到128×128；压缩文件只有100～300 KiB也不能省去约50万源像素的inflate、滤波、CRC及回调CPU成本。

最小离线检查：原有流式PNG碎片/CRC测试、诊断JSON字段测试与PC诊断格式自检通过。完整构建成功，导出`outputs/cabadge-v7.9.7-maplod`，核对实际`sdkconfig.verified.h`窗口11520 B、邮箱10、TLS输入16384 B。COM3仅写0x10000应用，esptool报告`Hash of data verified`；USB状态读回7.9.7-maplod。用户在同一次实板会话按提示切到LOD2与LOD3并回复“完成”。LOD2四张冷Tile全部`result=1`、刷新`result=0`，分别420978～607470 B、单张总7.53～9.75秒、Pngle累计3.05～3.67秒；LOD3四张冷Tile也全部`result=1`、刷新`result=0`，分别91019～331753 B、单张总3.25～6.38秒、Pngle累计1.97～3.41秒。两次刷新均保持2 lane、后续请求复用连接，未出现新的Tile负码。此次只能验证这些坐标，不能据此保证所有世界和坐标都无失败。

冷Tile接收已改善：同坐标LOD2 `x=-1,z=-1` 旧记录曾在约13.37秒HTTP API时间只收到368640 B并失败；本轮收到完整580446 B，HTTP API累计8.77秒、整Tile9.10秒。服务器状态/无线条件不受控，这不是严格A/B。新版LOD2/3网络HTTP调用仍占约1.2～9.4秒，Pngle约2～4秒，二者在双任务流水线中重叠，不能简单相加。LOD2准入快照Internal54791 B、DMA47003 B、PSRAM5823264 B；LOD3为54475/46687/5692176 B，均非历史最低。增大TCP窗口/邮箱可能让活动连接多占RAM，运行低水位回退保留；没有做长测或强制低内存测试。

证据：`outputs/cabadge-v7.9.7-maplod/verification.json`、`F:/CABadgeBuild/build-7.9.7-maplod-final.log`、`F:/CABadgeBuild/flash-7.9.7-maplod.log`、`F:/CABadgeBuild/logs/bluemap-20260924-001418-060408.jsonl`；旧失败参照`F:/CABadgeBuild/logs/bluemap-20260923-235750-586312.jsonl`。本轮只做一次基本实板会话，v1.1.0/7.9.2-memory正式发布附件未动。

## 2026-09-24 R71：BlueMap ESP32 接收和 PNG 采样优化（7.9.8-maprx）

用户确认7.9.7的LOD2/LOD3冷Tile全成功，要求直接优化并编译烧录，自行上手判断，不做复杂A/B。检查ESP-IDF 6.1实际源码与已验证配置：原TCP接收窗口11520 B、邮箱10、Wi-Fi静态RX缓冲10、动态RX缓冲32、AMPDU RX BA窗口6、HTTP client接收缓冲4096 B；Tile读取每次8192 B。ESP-IDF的HTTP读取路径先读入内部接收缓冲，再解析/复制给调用方；双槽PSRAM读取后还复制到Pngle输入缓冲。后两处复制为现有双任务解耦与PNG碎片解析服务，本轮保留，避免改动已稳定流水线。

本版TCP窗口改14360 B、接收邮箱12、Wi-Fi RX BA窗口8、HTTP client接收缓冲8192 B，与8192 B读取块对齐。Wi-Fi静态RX缓冲保持10，动态RX上限保持32，未增加常驻DMA静态缓冲；网络窗口/邮箱与BA增量仍可能提高峰值内部RAM占用。Pngle针对BlueMap实际501×1002、非交错8-bit RGBA Tile，在解压和PNG滤波之后用PSRAM中两个500项采样表跳过不会进入128×128输出的颜色转换/回调，并将采样点直接写RGB565；交错或其他色型仍走原路径。源图仍完整解压及CRC检查，所以不能把减少回调等同于跳过全部解码成本。Tile Cache 20张、2 lane、Keep-Alive、16 KiB Pngle输入、Direct Compositor、LVGL/QSPI/动画、内存压力降级逻辑均未改。

最小软件检查：真实LOD2 PNG（501×1002、561796 B）在碎片输入下与既有128×128 RGB565采样逐像素一致；截断/CRC损坏被拒绝。ESP-IDF编译SUCCESS，应用静态RAM 58792 B、Flash 4153699 B；构建导出配置确认窗口14360、邮箱12、RX BA 8、静态RX 10。COM3仅写0x10000应用分区，`Hash of data verified`，USB状态读回`firmware=7.9.8-maprx`且Wi-Fi已连接。未自动进入BlueMap、未执行拖动、冷Tile下载或低内存实板压力测试；新版本速度、解码耗时和持续内存余量等待用户上手反馈，不能把离线检查当作实板性能改善结论。首次错误的烧录调用所用Python环境缺少esptool，未写入任何数据；改用已安装的esptool 5.4.0后成功。

证据：`outputs/cabadge-v7.9.8-maprx/verification.json`、`F:/CABadgeBuild/build-7.9.8-maprx.log`、`F:/CABadgeBuild/flash-7.9.8-maprx.log`、`F:/CABadgeBuild/temp/map-stream-test/`。v1.1.0/7.9.2-memory正式发布附件及工作台默认包未动。
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

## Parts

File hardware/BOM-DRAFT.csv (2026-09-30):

Reference | Value | MPN | LCSC | Footprint | DNP | Datasheet
AE1 | RFANT5220110A0T | RFANT5220110A0T | C127611 | JXBadge:RFANT5220110A0T_C127611 |  | datasheets/RFANT5220110A0T.pdf
C1 | 24p 50V C0G | 0603CG240J500NT | C1654 | JXBadge:0603CG240J500NT_C1654
C2 | 24p 50V C0G | 0603CG240J500NT | C1654 | JXBadge:0603CG240J500NT_C1654
C3 | 10u 10V X5R | CL10A106KP8NNNC | C19702 | JXBadge:CL10A106KP8NNNC_C19702 |  | https://product.samsungsem.com/mlcc/CL10A106KP8NNN.do
C4 | 1u 25V X7R | CL10B105KA8NNNC | C29936 | JXBadge:CL10B105KA8NNNC_C29936
C5 | 100n 50V X7R | CC0603KRX7R9BB104 | C14663 | JXBadge:CC0603KRX7R9BB104_C14663
C6 | 100n 50V X7R | CC0603KRX7R9BB104 | C14663 | JXBadge:CC0603KRX7R9BB104_C14663
C7 | 100n 50V X7R | CC0603KRX7R9BB104 | C14663 | JXBadge:CC0603KRX7R9BB104_C14663
C8 | 100n 50V X7R | CC0603KRX7R9BB104 | C14663 | JXBadge:CC0603KRX7R9BB104_C14663
C9 | 1u 25V X7R | CL10B105KA8NNNC | C29936 | JXBadge:CL10B105KA8NNNC_C29936
C10 | 100n 50V X7R | CC0603KRX7R9BB104 | C14663 | JXBadge:CC0603KRX7R9BB104_C14663
C11 | 100n 50V X7R | CC0603KRX7R9BB104 | C14663 | JXBadge:CC0603KRX7R9BB104_C14663
C12 | DNP RF tune | DNP RF tune |  | Capacitor_SMD:C_0201_0603Metric | 不作装配 (DNP)
C13 | DNP RF tune | DNP RF tune |  | Capacitor_SMD:C_0201_0603Metric | 不作装配 (DNP)
C14 | 100n 50V X7R | CC0603KRX7R9BB104 | C14663 | JXBadge:CC0603KRX7R9BB104_C14663
C15 | 1u 25V X7R | CL10B105KA8NNNC | C29936 | JXBadge:CL10B105KA8NNNC_C29936
C16 | 100n 50V X7R | CC0603KRX7R9BB104 | C14663 | JXBadge:CC0603KRX7R9BB104_C14663
C17 | 100n 50V X7R | CC0603KRX7R9BB104 | C14663 | JXBadge:CC0603KRX7R9BB104_C14663
C18 | 1u 25V X7R | CL10B105KA8NNNC | C29936 | JXBadge:CL10B105KA8NNNC_C29936
C19 | 10u 10V X5R | CL10A106KP8NNNC | C19702 | JXBadge:CL10A106KP8NNNC_C19702
C20 | 100n 50V X7R | CC0603KRX7R9BB104 | C14663 | JXBadge:CC0603KRX7R9BB104_C14663
C21 | 10u 10V X5R | CL10A106KP8NNNC | C19702 | JXBadge:CL10A106KP8NNNC_C19702
C22 | 10u 25V X5R | CL21A106KAYNNNE | C15850 | JXBadge:CL21A106KAYNNNE_C15850
C23 | 100n 50V X7R | CC0603KRX7R9BB104 | C14663 | JXBadge:CC0603KRX7R9BB104_C14663
C24 | 22u 6.3V X5R | CL10A226MQ8NRNC | C59461 | JXBadge:CL10A226MQ8NRNC_C59461
C25 | 22u 6.3V X5R | CL10A226MQ8NRNC | C59461 | JXBadge:CL10A226MQ8NRNC_C59461
C26 | 100n 50V X7R | CC0603KRX7R9BB104 | C14663 | JXBadge:CC0603KRX7R9BB104_C14663
C27 | 1u 25V X7R | CL10B105KA8NNNC | C29936 | JXBadge:CL10B105KA8NNNC_C29936
C28 | 100n 50V X7R | CC0603KRX7R9BB104 | C14663 | JXBadge:CC0603KRX7R9BB104_C14663
C29 | 10u 25V X5R | CL21A106KAYNNNE | C15850 | JXBadge:CL21A106KAYNNNE_C15850
D1 | SMF5.0A | SMF5.0A | C151296 | JXBadge:SMF5_0A_C151296 |  | datasheets/SMF-Littelfuse.pdf
D2 | DSK34 | DSK34 | C727076 | JXBadge:DSK34_C727076_C727076 |  | datasheets/DSK34.pdf
D3 | CHARGE red | KT-0603R | C2286 | JXBadge:KT-0603R_C2286
D4 | FULL green | 19-217/GHC-YR1S2/3T | C72043 | JXBadge:19-217_GHC-YR1S2_3T_C72043
FB1 | 600R@100MHz >=500mA | BLM18AG601SN1D | C19330 | JXBadge:BLM18AG601SN1D_C19330
J1 | FFC/FPC 0.5mm 18P 抽屉式上接触（当前装配规格） | 未提供厂家型号 |  | JXBadge:FPC-05F-18PH20_C2856802 |  | ../docs/J1-CONNECTOR.md
J2 | TYPE-C-31-M-12 | TYPE-C-31-M-12 | C165948 | JXBadge:TYPE-C-31-M-12_C165948 |  | datasheets/TYPE-C-31-M-12.pdf
J3 | 1.0-2P WT（不装；电池正负线直焊） | 1.0-2P WT | C2906268 | JXBadge:1_0-2P_WT_C2906268 | 不作装配 (DNP) | README.md#电池与屏幕连接器
BAT_EXT | 电池 450mAh 42x30x4mm（1只；正负双线直焊） | 未提供厂家型号 |  | 外接电池；非PCB位号 |  | README.md#电池与屏幕连接器
L1 | 24nH | LQG15WZ24NH02D | C1012734 | JXBadge:LQG15WZ24NH02D_C1012734
L2 | 2nH RF tune | LQP03TN2N0B02D | C86125 | JXBadge:LQP03TN2N0B02D_C86125
L3 | 0.47uH Isat=4.8A | DFE201610E-R47M=P2 | C269773 | JXBadge:DFE201610E-R47M_P2_C269773 |  | datasheets/DFE201610E-R47M.pdf
Q1 | AO3401A | AO3401A | C15127 | JXBadge:AO3401A_C15127 |  | datasheets/AO3401A.pdf
Q2 | MMBT3904 | MMBT3904,215 | C426835 | JXBadge:MMBT3904_215_C426835 |  | datasheets/MMBT3904.pdf
Q3 | AO3401A | AO3401A | C15127 | JXBadge:AO3401A_C15127 |  | datasheets/AO3401A.pdf
Q4 | AO3401A | AO3401A | C15127 | JXBadge:AO3401A_C15127 |  | datasheets/AO3401A.pdf
Q5 | MMBT3904 | MMBT3904,215 | C426835 | JXBadge:MMBT3904_215_C426835 |  | datasheets/MMBT3904.pdf
Q6 | MMBT3904 | MMBT3904,215 | C426835 | JXBadge:MMBT3904_215_C426835 |  | datasheets/MMBT3904.pdf
Q7 | MMBT3904 | MMBT3904,215 | C426835 | JXBadge:MMBT3904_215_C426835 |  | datasheets/MMBT3904.pdf
R1 | 0 | 0603WAF0000T5E | C21189 | JXBadge:0603WAF0000T5E_C21189
R2 | 0 | 0603WAF0000T5E | C21189 | JXBadge:0603WAF0000T5E_C21189
R3 | 0 | 0603WAF0000T5E | C21189 | JXBadge:0603WAF0000T5E_C21189
R4 | 0 | 0603WAF0000T5E | C21189 | JXBadge:0603WAF0000T5E_C21189
R5 | 0 | 0603WAF0000T5E | C21189 | JXBadge:0603WAF0000T5E_C21189
R6 | 0 | 0603WAF0000T5E | C21189 | JXBadge:0603WAF0000T5E_C21189
R7 | 10k | 0603WAF1002T5E | C25804 | JXBadge:0603WAF1002T5E_C25804
R8 | 10k | 0603WAF1002T5E | C25804 | JXBadge:0603WAF1002T5E_C25804
R9 | 10k | 0603WAF1002T5E | C25804 | JXBadge:0603WAF1002T5E_C25804
R10 | 100k | 0603WAF1003T5E | C25803 | JXBadge:0603WAF1003T5E_C25803
R11 | 10k | 0603WAF1002T5E | C25804 | JXBadge:0603WAF1002T5E_C25804
R12 | 100k | 0603WAF1003T5E | C25803 | JXBadge:0603WAF1003T5E_C25803
R13 | 5.1 | 0603WAF510KT5E | C25197 | JXBadge:0603WAF510KT5E_C25197
R14 | 4.7k | 0603WAF4701T5E | C23162 | JXBadge:0603WAF4701T5E_C23162
R15 | 4.7k | 0603WAF4701T5E | C23162 | JXBadge:0603WAF4701T5E_C23162
R16 | 10k | 0603WAF1002T5E | C25804 | JXBadge:0603WAF1002T5E_C25804
R17 | 10k | 0603WAF1002T5E | C25804 | JXBadge:0603WAF1002T5E_C25804
R18 | 5.1k | 0603WAF5101T5E | C23186 | JXBadge:0603WAF5101T5E_C23186
R19 | 5.1k | 0603WAF5101T5E | C23186 | JXBadge:0603WAF5101T5E_C23186
R20 | 22 | 0603WAF220JT5E | C23345 | JXBadge:0603WAF220JT5E_C23345
R21 | 22 | 0603WAF220JT5E | C23345 | JXBadge:0603WAF220JT5E_C23345
R22 | 100k | 0603WAF1003T5E | C25803 | JXBadge:0603WAF1003T5E_C25803
R23 | 4.02k 1% | 0603WAF4021T5E | C23040 | JXBadge:0603WAF4021T5E_C23040_C23040
R26 | 560k 1% | 0603WAF5603T5E | C23203 | JXBadge:0603WAF5603T5E_C23203
R27 | 100k 1% | 0603WAF1003T5E | C25803 | JXBadge:0603WAF1003T5E_C25803
R28 | 100k | 0603WAF1003T5E | C25803 | JXBadge:0603WAF1003T5E_C25803
R29 | 10k | 0603WAF1002T5E | C25804 | JXBadge:0603WAF1002T5E_C25804
R30 | 10k | 0603WAF1002T5E | C25804 | JXBadge:0603WAF1002T5E_C25804
R31 | 2.2k | 0603WAF2201T5E | C4190 | JXBadge:0603WAF2201T5E_C4190
R32 | 2.2k | 0603WAF2201T5E | C4190 | JXBadge:0603WAF2201T5E_C4190
R33 | 100k | 0603WAF1003T5E | C25803 | JXBadge:0603WAF1003T5E_C25803
R34 | 100k | 0603WAF1003T5E | C25803 | JXBadge:0603WAF1003T5E_C25803
R35 | 100k | 0603WAF1003T5E | C25803 | JXBadge:0603WAF1003T5E_C25803
R36 | 200k 1% | 0603WAF2003T5E | C25811 | JXBadge:0603WAF2003T5E_C25811
R37 | 100k 1% | 0603WAF1003T5E | C25803 | JXBadge:0603WAF1003T5E_C25803
R38 | 47k | 0603WAF4702T5E | C25819 | JXBadge:0603WAF4702T5E_C25819
R39 | 47k | 0603WAF4702T5E | C25819 | JXBadge:0603WAF4702T5E_C25819
R40 | 10k | 0603WAF1002T5E | C25804 | JXBadge:0603WAF1002T5E_C25804
R41 | 100k | 0603WAF1003T5E | C25803 | JXBadge:0603WAF1003T5E_C25803
SW1 | POWER | JS102011SAQN | C221660 | JXBadge:JS102011SAQN_C221660
SW2 | BOOT | HX-2X4X3.5CA-2.5N | C49234137 | JXBadge:HX-2X4X3_5CA-2_5N_C49234137 |  | datasheets/HX-2X4X3.5CA-2.5N.pdf
SW3 | RESET | HX-2X4X3.5CA-2.5N | C49234137 | JXBadge:HX-2X4X3_5CA-2_5N_C49234137 |  | datasheets/HX-2X4X3.5CA-2.5N.pdf
U1 | ESP32-S3R8 | ESP32-S3R8 | C2913194 | JXBadge:ESP32-S3_R8__C2913194 |  | ../CDA236FFCB3F25B7D5220D2CA9867287.pdf
U2 | W25Q128JVSIQ | W25Q128JVSIQ | C97521 | JXBadge:W25Q128JVSIQTR_C97521 |  | datasheets/W25Q128JV.pdf
U3 | SC7A20TR | SC7A20TR | C5126709 | JXBadge:SC7A20TR_C5126709_C5126709 |  | datasheets/SC7A20.pdf
U4 | USBLC6-2SC6 | USBLC6-2SC6 | C7519 | JXBadge:USBLC6-2SC6_C7519 |  | datasheets/USBLC6-2SC6.pdf
U5 | TP4056-MS | TP4056-MS | C7473158 | JXBadge:TP4056-MS_C7473158 |  | datasheets/TP4056-MS.pdf
U6 | SGM62117XTGH10G/TR | SGM62117XTGH10G/TR | C5152031 | JXBadge:SGM62117XTGH10G_TR_C5152031 |  | datasheets/SGM62117.pdf
Y1 | 40MHz CL15pF | TAXM40M4ZHBCDT2T | C424432 | JXBadge:TAXM40M4ZHBCDT2T_C424432 |  | datasheets/TAXM40M4ZHBCDT2T.pdf

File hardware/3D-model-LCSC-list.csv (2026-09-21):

Reference | Part | LCSC code | Status | Source
AE1 | RFANT5220110A0T | C127611 | Part number verified; 3D availability unchecked | https://www.lcsc.com/product-detail/C127611.html
J1 | FPC-05F-18PH20 | C2856802 | Part number verified; 3D availability unchecked | https://www.lcsc.com/product-image/C2856802.html
J2 | TYPE-C-31-M-12 | C165948 | Part number verified; 3D availability unchecked | https://jlcpcb.com/partdetail/C165948
J3 | 1.0-2P WT | C2906268 | Part number verified; 3D availability unchecked | https://item.szlcsc.com/3178978.html
U3 | SC7A20TR | C5126709 | Part number verified; 3D availability unchecked | https://www.lcsc.com/product-detail/C5126709.html
U5 | TP4056-MS | C7473158 | Part number verified; 3D availability unchecked | https://item.szlcsc.com/8533532.html
U6 | SGM62117XTGH10G/TR | C5152031 | Verified on JLCPCB; 3D availability unchecked | https://jlcpcb.com/partdetail/SGMICRO-SGM62117XTGH10GTR/C5152031
Y1 | TAXM40M4ZHBCDT2T | C424432 | Part number verified; 3D availability unchecked | https://item.szlcsc.com/417823.html
SW1 | JS102011SAQN | C221660 | Part number verified; 3D availability unchecked | https://item.szlcsc.com/222090.html
SW2/SW3 | SKRTLBE010 | C127481 | Part number verified; import once | https://www.lcsc.com/product-detail/Tactile-Switches_ALPS-Electric-SKRTLBE010_C127481.html
L3 | 744383560047HT |  | No verified LCSC code found; do not substitute a similar part

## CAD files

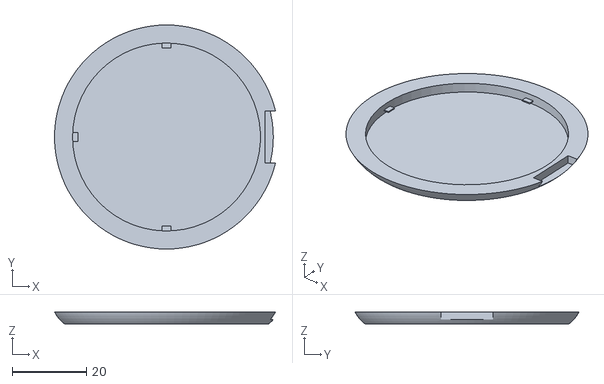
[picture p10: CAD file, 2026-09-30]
hardware/enclosure/releases/V6_20260930/V6_Lower.STL
59.5 x 60.3 x 3.30

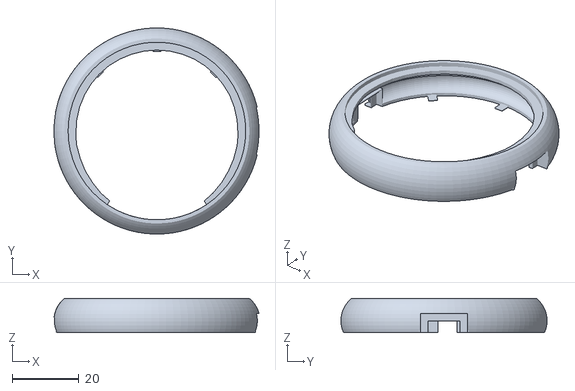
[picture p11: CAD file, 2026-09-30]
hardware/enclosure/releases/V6_20260930/V6_Upper.STL
61.6 x 62.0 x 10.3

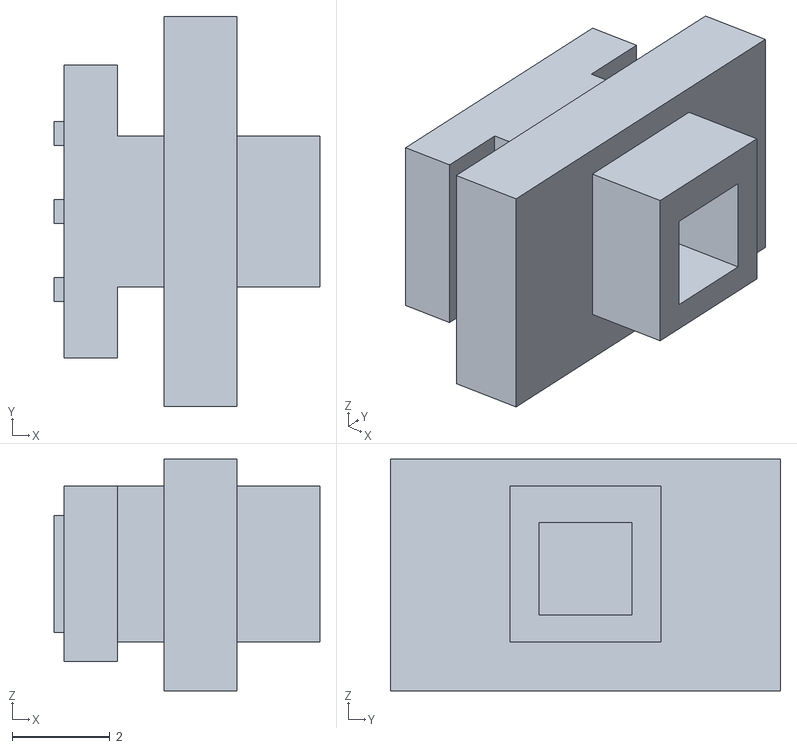
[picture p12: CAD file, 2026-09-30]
hardware/enclosure/releases/V6_20260930/V6_Slider.STL
5.45 x 8.00 x 4.75

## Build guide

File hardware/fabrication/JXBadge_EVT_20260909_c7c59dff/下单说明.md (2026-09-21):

# 计协电子吧唧首板打样文件

本次唯一打板包：**JXBadge_EVT_20260909_c7c59dff_PCB.zip**。

可以把这个 ZIP 上传到嘉立创进行文件解析和报价。下单时核对下面的层数、板厚、叠层及孔工艺；文件导出并不代表板厂已确认订单工艺。本次没有上传工程或代下单。

## 来源与版本

- 来源：`F:/计协吧唧/hardware/JXBadge_V1.kicad_pcb`。
- PCB SHA-256：`c7c59dff5e6f2065a2157a81414d9d21c5cb1196a7b277656e15007753801a8d`。
- 2026-09-09 晚按 ESP32/USB 两份规则优化后的版本，保持 V1.1 充电/烧录架构。
- 导出前后源 PCB 未变化；导出快照在 `verification/source/`。这是导出核验快照，不是包含全部外部 3D 模型的完整项目备份。

## 下单参数

| 项目 | 本版要求 / 说明 |
|---|---|
| 用途 | EVT 首板功能验证，裸 PCB；元件自行采购焊接 |
| 材料 | FR-4 |
| 层数 | **4 层** |
| 板厚 | **名义 1.6 mm** |
| 板形 / 尺寸 | 圆板，铣边中心线直径 **50.00 mm**，按 Edge.Cuts 加工 |
| 层序 | F.Cu → In1.Cu（GND）→ In2.Cu（电源/信号）→ B.Cu |
| 目标叠层 | **JLC04161H-7628**；外层至相邻内层介质厚 0.2104 mm |
| 铜厚基线 | 外层名义 1 oz / 0.035 mm；内层名义 0.5 oz，叠层铜厚 0.0152 mm |
| 最小钻孔 | 0.20 mm；另有 0.25 mm 过孔、0.8 mm 宽镀槽孔 |
| 最小局部铜间距 | QFN 出线局部 0.11 mm；默认网络 0.127 mm |
| 丝印 | 双面丝印；背面保留用户确认的满幅 Logo |
| 阻焊 / 颜色 | 文件包含双面阻焊开窗；现有预览为绿油白字，订单中选择相应颜色 |
| 表面处理 | 源工程未指定，需在订单里选择；Gerber 本身不决定表面处理 |
| 数量 / 交期 | 由订单选择，未在本包中指定 |

**叠层须在付款前确认。** 本版 USB/RF 计算采用上述 7628 叠层；不能无复核地替换为 3313/1080 等介质厚度不同的叠层。若国内下单页面不展示此编号，可将外层介质厚度 0.2104 mm、铜厚和层序交给嘉立创确认。官方叠层参考：[JLCPCB Controlled Impedance Stackup](https://jlcpcb.com/impedance)。

USB 均匀主干目标 90 Ω 差分、RF 均匀馈线目标 50 Ω 单端。既有计算约为 89.34 Ω 和 49.58 Ω，但不代表实测或板厂承诺；焊盘扇出不属于均匀传输线。需要阻抗控制服务时，将这两个目标及既有线宽/间距交给板厂确认，不能只依靠 ZIP 自动推断。

## ZIP 内容

PCB ZIP 只包含下列 **11 个制造文件**，文件直接位于 ZIP 根目录：

| 文件 | 用途 |
|---|---|
| JXBadge_V1-F_Cu.gtl | 顶层铜 L1 |
| JXBadge_V1-In1_Cu.g1 | 内层铜 L2，GND |
| JXBadge_V1-In2_Cu.g2 | 内层铜 L3 |
| JXBadge_V1-B_Cu.gbl | 底层铜 L4 |
| JXBadge_V1-F_Mask.gts / B_Mask.gbs | 顶/底阻焊 |
| JXBadge_V1-F_Silkscreen.gto / B_Silkscreen.gbo | 顶/底丝印 |
| JXBadge_V1-Edge_Cuts.gm1 | 闭合圆形板框 |
| JXBadge_V1-PTH.drl | 镀孔及镀槽孔 |
| JXBadge_V1-NPTH.drl | 非镀孔 |

格式为 Gerber X2、毫米绝对坐标、6 位小数精度；Excellon 使用毫米显式小数、同一绝对原点，未额外镜像。钻孔的负 Y 坐标与 Gerber 一致，不要手动翻转或另设原点。

展开目录中还保留 KiCad `.gbrjob` 元数据供核查，但不放入上传 ZIP。其尺寸 50.05 mm 包含板框绘图笔宽 0.05 mm；真正加工轮廓是两段半径 25 mm 的圆弧中心线，直径 50.00 mm。

## 可选钢网

`JXBadge_EVT_20260909_c7c59dff_TOP_STENCIL.zip` 是**单独的顶层钢网文件**，只有 F.Paste 和板框。购买钢网时使用，不要当作裸 PCB 文件上传。钢网厚度、外框尺寸及定位方案在钢网订单中另选；本包保留当前设计的锡膏开窗。

## 导出验收

- 源板检查：DRC 0 错误、0 未连接、0 原理图一致性问题；7 条既有背面 Logo 警告。ERC 0 错误、1 条既有 RF_STUB 警告。源板哈希与上一轮验收一致。
- 独立回读确认 4 个铜层、2 个阻焊层、2 个丝印层、闭合板框及两份钻孔文件齐全。
- **246 个钻孔/槽孔逐一匹配源 PCB**：238 个镀孔（234 个过孔 + 4 个 Type-C 镀槽孔）、8 个非镀孔。中心最大导出取整误差 0.000641 mm，孔径/槽长匹配；无遗漏或多余孔。
- **340 个带编号的顶层焊盘**：Gerber X2 引脚标识、坐标与网络均匹配源 PCB。
- 圆板框由两段首尾相接的半圆组成，圆心一致、半径 25 mm、闭合。
- 四层铜已通过 Gerbonara 独立解析，并生成、查看回读图 `verification/gerber-readback.png`。没有以 PCB 3D 渲染冒充 Gerber 回读。
- ZIP CRC 与每个压缩文件的原始字节一致性检查通过。文件哈希清单为 `MANIFEST.json`。

检查脚本的 3 条报告项已逐条复核：圆板被“矩形至少需四条边”的启发式误报为未闭合；不同铜层有不同铜覆盖范围被误报为层错位。原始报告保留在 `verification/gerber-analysis.json`，处理依据在 `verification/export-checks.json`。Gerbonara 的 G90 位置/宏多余参数提示不影响本次读取，钻孔及焊盘坐标已另行逐项核对。

本轮是制造文件导出与回读核验，没有重新进行完整电气、SPICE、EMC、热或器件生命周期评审。首板仍需验证供电、充电、USB 枚举/烧录、屏幕、触摸/传感器和无线性能。

导出流程参考：[嘉立创 KiCad Gerber/Drill 指南](https://jlcpcb.com/help/article/how-to-generate-gerber-and-drill-files-in-kicad-7)。

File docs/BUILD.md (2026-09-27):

# v1.1.0 安装与构建

内部固件版本：7.9.2-memory。下载与烧录地址、旧版分区升级方法见 [发布说明](RELEASE-v1.1.0.md)。发布 ZIP 解压到 `outputs/cabadge-v7.9.2-memory/`，使三个 BIN 与 verification.json 直接位于该目录。设备已运行本版时无需重刷。

## Windows 工作台

系统 Python 需含 Tkinter、pyserial、esptool；运行 `firmware-v7/run.cmd`，使用当前固件安装与诊断入口。壁纸管理使用设备本地网页。当前没有 USB 实板画面镜像；直接看 LCD。`tools/flasher/app.py` 的校验/烧录逻辑仍被复用，但旧独立窗口的诊断预设不是当前安装入口。

## 板端构建

现有环境使用 Windows、F 盘与 PlatformIO。未验证全新机器一键构建或字节级复现；下面是实际脚本约定。

1. 用 Python 3.10 创建 `firmware/bringup/.venv` 并安装 PlatformIO 6.2.0；只需这个虚拟环境，不需要旧 firmware 源码。构建脚本固定调用其中的 Python。
2. 用支持 tarfile 安全解包的 Python 运行 `firmware-v7/setup_deps.py`，获取 LVGL 9.4.0 与字体到 vendor。不再下载已删除模拟器使用的 SDL2；现有生成资源已入库，板端构建不必重新生成图片/字库。
3. 在仓库根目录运行：

```powershell
$env:TEMP = $env:TMP = 'F:\CABadgeBuild\temp'
$env:CABADGE_DISPLAY_PERF = '0'
$env:CABADGE_TRANSITION_CACHE_DEBUG = '1'
powershell -NoProfile -ExecutionPolicy Bypass -File firmware-v7/usb_screen/build.ps1
```

脚本固定 PlatformIO 核心目录 `F:/CABadgeBuild/platformio/idf61`、暂存 `F:/CABadgeBuild/staging/usb-screen-v7-idf61`。`platformio.ini` 固定 espressif32 7.1.3、framework-espidf 4.60100.0（ESP-IDF 6.1.0）；组件清单固定 LVGL 9.4.0、Adapter 0.7.1、ST77916 2.0.2，锁定信息在 `device/dependencies.lock`。

当前源码导出到 `outputs/cabadge-v7.9.16-eaf-transition/`（v1.1.0 发布附件仍为 7.9.2-memory），会覆盖同名本地产物，先另存发布附件。详细显示诊断开关为 1 时导出 diagnostic 后缀目录，不与正式包混用。

## 检查边界

可单独运行 `python firmware-v7/test_physical_display.py`、`python firmware-v7/test_transition_compositor.py`、`python firmware-v7/test_map_stream.py`；这些宿主检查依赖脚本所示的本地 Zig 工具，不启动 UI 模拟器。首次恢复环境需按各脚本路径安装工具。

旧桌面 CMake、模拟器、像素投屏和过时测试已删除，板端唯一构建入口是 `firmware-v7/usb_screen/build.ps1`。现有工作台使用 `usb_screen/framing.py` 的 USB 编解码；`python firmware-v7/usb_screen/framing.py` 可运行无设备自检。实体画面验收仍需要实际烧录版本。

项目源码/附件放 F:/计协吧唧，工具缓存与 TEMP/TMP 放 F:/CABadgeBuild。未上传的 outputs、vendor、虚拟环境不会随 GitHub 源码 ZIP 提供。

## BlueMap USB 耗时诊断（7.9.3-mapdiag 起）

在项目根目录运行 `python tools/map_perf_monitor.py`。使用现有 pyserial；自动识别 CABadge USB，必要时加 `--port COM3`。先关闭工作台的连接、miniterm 等占用串口的程序。工具不会切页面；手动打开地图，等待加载，拖动一次，再缩放一次。Ctrl+C 停止。

日志保存在 `F:/CABadgeBuild/logs/bluemap-时间.log`，同名 `.jsonl` 保留原始记录。设备保留最近64条 Tile/Refresh 记录，读取不清空；历史覆盖会报告 lost。调试存储约14 KiB PSRAM，无逐帧或逐chunk输出，不启用 ESP_LOG/UART console。

协议复用 JXUI 帧：BR_READY capability 32；query type41 的 payload 为 `0x0a + uint32_le(after_seq)`；type42 返回带 map_perf=1 的 JSON 记录封装。原有诊断接口不变。`available=false` 表示诊断存储分配失败。

计时口径：
- first_byte 是 IDF 第一个已解析 HTTP header 回调，TTFB 是近似上界，不是线上首字节时间；不拆 DNS/TCP/TLS。
- bytes 是 HTTP body 回调实际交付字节，不含响应头；错误/取消请求也记录已收到数据。
- PNG与RGB565采样在同一次feed中完成，decode/downsample统计feed调用累计墙钟耗时。两个complete时间都表示decoder确认输出有效的时刻，不伪装成两个独立阶段。
- download_wall 包含其间穿插的decode，不能把两者简单相加。7.9.4的http_api_sum累加两路HTTP调用时间，可能互相重叠；network_phase_wall是整段下载调度的墙钟区间，含穿插的解码和渐进更新交接。players_wall含玩家HTTP及JSON解析，不能重复相加。
- refresh total从GUI接受地图请求到GUI接收结果，另列启动等待、worker_wall、GUI排队和GUI更新调用耗时（7.9.4累计本次刷新所有patch及最终状态更新）。GUI submit不代表LCD已显示。取消/过期结果为-2，未发生的里程碑为N/A。
- 7.9.3原版为串行且每次close。7.9.4最多两路独立HTTP连接；完整响应后按服务器keep-alive保留连接，损坏的空闲连接只重连一次。connects记录真正的新连接事件，reused记录本次请求是否实际复用了已有socket，不能仅凭配置开关判断。
- 7.9.7起Tile失败有独立错误码：-10 HTTP、-11 READ、-12 TIMEOUT、-13 CONNECTION、-14 PNG_PARSE、-15 CRC、-16 DECODE、-17 SIZE、-18 OTHER；JSON另带`error_category`、`error_detail`和`http_errno`。-2仍是取消，-3是第二路内存回退，-4是分配失败。完整HTTP body后才允许Keep-Alive复用。

最小离线检查：`python tools/map_perf_monitor.py --self-test`；`python firmware-v7/test_map_perf.py` 验证实际C端历史队列、覆盖与JSON边界。

### 7.9.6 BlueMap加载与内存边界

- Tile最多20张128×128 RGB565、上限640 KiB，key含world/LOD/X/Z；按访问更新LRU，当前视口命中项固定。跨refresh及退出地图保留，保留原60秒地形有效期。PSRAM低于1 MiB时回收未固定的旧Tile，退出地图时回收到至少1.5 MiB。
- 第一路复用已有badge_apps任务；第二路仅在余量充足时创建8192 B栈的map_http1，退出后释放。每路最多一个HTTP client、一份16 KiB流式解码输入、一份Pngle工作区和32 KiB输出Tile。每个活动Tile另有PSRAM双8 KiB接收槽与6144 B读取任务栈，网络读取与Pngle解码并行；PSRAM低于1.5 MiB或分配失败时回到同步读取。
- 新建第二路时按尚未分配的任务/HTTP资源预留，最严门槛Internal≥56 KiB、DMA≥48 KiB、Internal最大块≥12 KiB、PSRAM≥1.5 MiB；运行安全底线Internal32 KiB/DMA24 KiB。低内存时停止额外请求并可回退单路。已开始的旧Tile若仍在同world/LOD、距新视野中心不超过2格且PSRAM大于1 MiB，就允许下载完成并入缓存；旧serial的patch不会写入当前画布。
- GUI继续持有原有一张360×360画布；下载线程只传最多16行RGB565 patch（≤11520 B），队列1条，不分配第二张完整地图。GUI修改像素并invalidate局部区域；按住拖动时暂停接收，序列号丢弃旧视口patch。
- 协调任务的临时结果移到约3 KiB PSRAM，避免在HTTP/解码调用栈中叠加大结构；退出释放。保留小队列用于下次复用。
- 附加最小检查：`python firmware-v7/test_map_cache.py`，覆盖LRU/pin和六档缩放、负坐标的区域采样。

7.9.7仅调整地图HTTP链路：大Tile总时限从12秒改为30秒并单独报告TIMEOUT；lwIP TCP接收窗口5760→11520 B、接收邮箱6→10，HTTP client内部接收缓冲2048→4096 B，读取任务仍按8 KiB送入双槽，Pngle仍使用16 KiB输入。TLS输入缓冲保持16 KiB。一次实板LOD2/3检查见主记录R70；全局TCP缓冲增加可能占用额外内存，原低水位单路降级仍在。

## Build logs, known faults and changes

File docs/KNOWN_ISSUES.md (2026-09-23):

# v1.1.0 已知限制与待验证

- 无 TE：软件 DMA 完成不等于屏幕扫描同步，实屏撕裂/残影仍需目视。
- 当前包完成一次基本检查；真实手指滑动、BLE 对端连接、长时间无线并发及异常断电恢复未全量验收。
- 旧 v1.0 到本版的扩大壁纸分区迁移代码存在，本轮未重测该升级路径；保留图片原文件/设备备份。
- 手机管理按现有产品行为使用开放热点、无访问码，仅在可信近距离环境开启。
- BlueMap 依赖现有远端服务器；网络不可用不等同于本地 renderer 失败。
- 构建仍依赖 Windows/F 盘路径；无 OTA、BLE 传图功能承诺。
- 第三方游戏素材的独立授权范围待核实，见 THIRD_PARTY.md。

历史失败与版本证据保留在首板测试记录.md；不能据新版本基本检查宣称所有旧问题已关闭。

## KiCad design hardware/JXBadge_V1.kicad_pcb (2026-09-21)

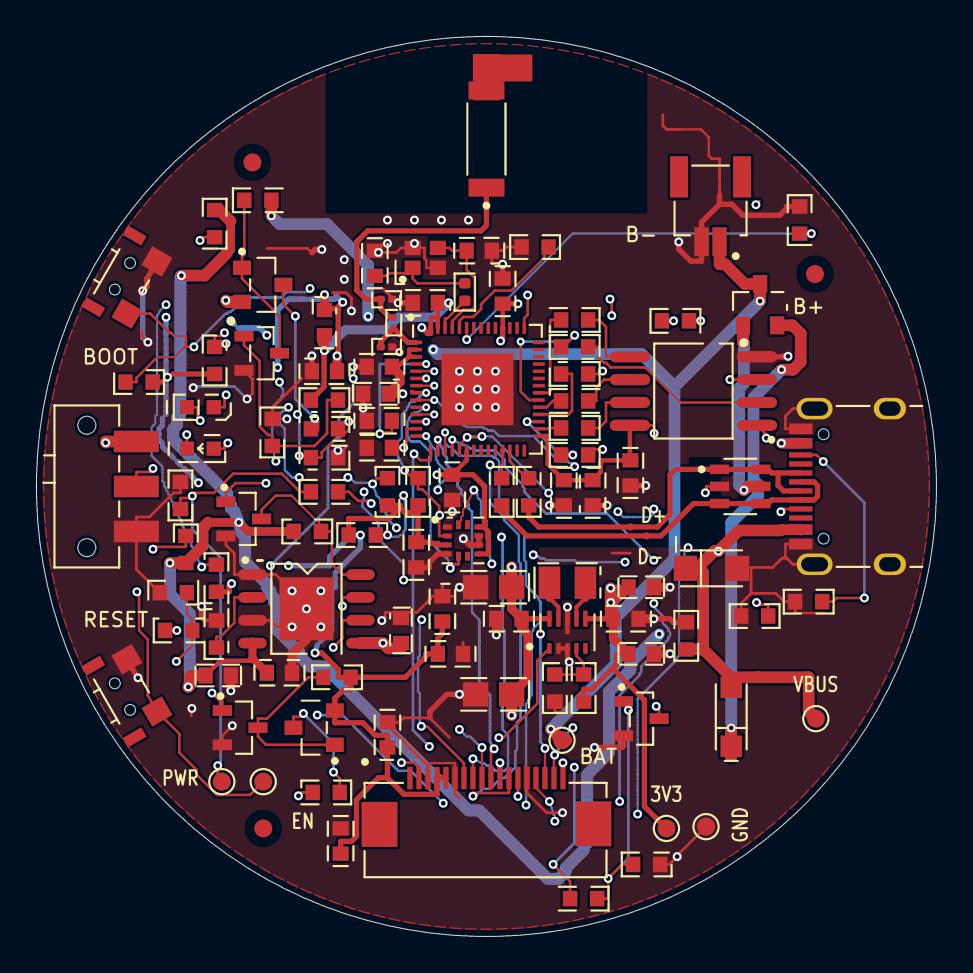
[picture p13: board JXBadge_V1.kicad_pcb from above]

Board: 4 copper layers, 50.0 x 50.0 mm, 108 parts (0 on the bottom side), 68 nets.

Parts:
AE1: RFANT5220110A0T; RFANT5220110A0T_C127611
C1, C2: 24p 50V C0G; 0603CG240J500NT_C1654
C3, C19, C21: 10u 10V X5R; CL10A106KP8NNNC_C19702
C4, C9, C15, C18, C27: 1u 25V X7R; CL10B105KA8NNNC_C29936
C5, C6, C7, C8, C10, C11, C14, C16, C17, C20, C23, C26, C28: 100n 50V X7R; CC0603KRX7R9BB104_C14663
C12, C13: DNP RF tune; C_0201_0603Metric
C22, C29: 10u 25V X5R; CL21A106KAYNNNE_C15850
C24, C25: 22u 6.3V X5R; CL10A226MQ8NRNC_C59461
D1: SMF5.0A; SMF5_0A_C151296
D2: DSK34; DSK34_C727076_C727076
D3: CHARGE red; KT-0603R_C2286
D4: FULL green; 19-217_GHC-YR1S2_3T_C72043
FB1: 600R@100MHz >=500mA; BLM18AG601SN1D_C19330
FID1, FID2, FID3: Fiducial; Fiducial_1mm_Mask2mm
J1: W180TE010I-18Z(CTP-A1); FPC-05F-18PH20_C2856802
J2: TYPE-C-31-M-12; TYPE-C-31-M-12_C165948
J3: 1.0-2P WT; 1_0-2P_WT_C2906268
L1: 24nH; LQG15WZ24NH02D_C1012734
L2: 2nH RF tune; LQP03TN2N0B02D_C86125
L3: 0.47uH Isat=4.8A; DFE201610E-R47M_P2_C269773
Q1, Q3, Q4: AO3401A; AO3401A_C15127
Q2, Q5, Q6, Q7: MMBT3904; MMBT3904_215_C426835
R1, R2, R3, R4, R5, R6: 0; 0603WAF0000T5E_C21189
R7, R8, R9, R11, R16, R17, R29, R30, R40: 10k; 0603WAF1002T5E_C25804
R10, R12, R22, R28, R33, R34, R35, R41: 100k; 0603WAF1003T5E_C25803
R13: 5.1; 0603WAF510KT5E_C25197
R14, R15: 4.7k; 0603WAF4701T5E_C23162
R18, R19: 5.1k; 0603WAF5101T5E_C23186
R20, R21: 22; 0603WAF220JT5E_C23345
R23: 4.02k 1%; 0603WAF4021T5E_C23040_C23040
R26: 560k 1%; 0603WAF5603T5E_C23203
R27, R37: 100k 1%; 0603WAF1003T5E_C25803
R31, R32: 2.2k; 0603WAF2201T5E_C4190
R36: 200k 1%; 0603WAF2003T5E_C25811
R38, R39: 47k; 0603WAF4702T5E_C25819
SW1: POWER; JS102011SAQN_C221660
SW2: BOOT; HX-2X4X3_5CA-2_5N_C49234137
SW3: RESET; HX-2X4X3_5CA-2_5N_C49234137
TP1: +3V3; TestPoint_Pad_D1.0mm
TP2: GND; TestPoint_Pad_D1.0mm
TP3: CHIP_EN; TestPoint_Pad_D1.0mm
TP4: USB_D+; USB_TestPoint_D0.4mm
TP5: USB_D-; USB_TestPoint_D0.4mm
TP6: VBUS; TestPoint_Pad_D1.0mm
TP7: BAT; TestPoint_Pad_D1.0mm
TP8: PWR_EN; TestPoint_Pad_D1.0mm
U1: ESP32-S3R8; ESP32-S3_R8__C2913194
U2: W25Q128JVSIQ; W25Q128JVSIQTR_C97521
U3: SC7A20TR; SC7A20TR_C5126709_C5126709
U4: USBLC6-2SC6; USBLC6-2SC6_C7519
U5: TP4056-MS; TP4056-MS_C7473158
U6: SGM62117XTGH10G/TR; SGM62117XTGH10G_TR_C5152031
Y1: 40MHz CL15pF; TAXM40M4ZHBCDT2T_C424432

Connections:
+3V3: C6.1, C7.1, C8.1, C14.1, C15.1, C16.1, C17.1, C18.1, C24.1, C25.1, C26.1, FB1.1, J1.4, J1.5, Q1.2, R10.1, R14.1, R15.1, R16.1, R17.1, R26.1, R29.1, R30.1, R34.1, TP1.1, U1.20, U1.46, U1.55, U1.56, U3.3, U3.7, U3.10, U6.6
BAT: C21.1, J3.1, Q3.3, Q4.2, R33.1, TP7.1, U5.5
BAT_ADC: C28.1, R36.2, R37.1, U1.13
BAT_SENSE: Q4.3, R36.1
BL_BASE: Q2.1, R11.2, R12.1
BL_GATE: Q1.1, Q2.3, R10.2
BL_PWM: R11.1, U1.6
BL_SOURCE: Q1.3, R13.1
BOOT: R29.2, SW2.1, U1.5
CC1: J2.A5, R18.1
CC2: J2.B5, R19.1
CHG_ALLOW: R40.1, U1.43
CHG_ALLOW_BASE: Q7.1, R40.2, R41.1
CHG_CE: Q6.3, R38.2, U5.8
CHG_INHIBIT: Q6.1, Q7.3, R39.2
CHG_PROG: R23.1, U5.2
CHIP_EN: C27.1, R30.2, SW3.1, TP3.1, U1.4
CHRG_N: D3.1, U5.7
CTP_INT: J1.18, R17.2, U1.9
CTP_RST: J1.17, R16.2, U1.11
DCDC_FB: R26.2, R27.1, U6.4
DONE_N: D4.1, U5.6
FLASH_CLK: R4.2, U2.6
FLASH_CLK_MCU: R4.1, U1.33
FLASH_CS: R3.2, R7.2, U2.1
FLASH_CS_MCU: R3.1, U1.32
FLASH_D: R6.2, U2.5
FLASH_D_MCU: R6.1, U1.35
FLASH_HD: R1.2, U2.7
FLASH_HD_MCU: R1.1, U1.30
FLASH_Q: R5.2, U2.2
FLASH_Q_MCU: R5.1, U1.34
FLASH_WP: R2.2, U2.3
FLASH_WP_MCU: R2.1, U1.31
GND: C1.2, C2.2, C3.2, C4.2, C5.2, C6.2, C7.2, C8.2, C9.2, C10.2, C11.2, C12.2, C13.2, C14.2, C15.2, C16.2, C17.2, C18.2, C19.2, C20.2, C21.2, C22.2, C23.2, C24.2, C25.2, C26.2, C27.2, C28.2, C29.2, D1.2, J1.3, J1.6, J1.14, J2.A1, J2.A12, J2.B1, J2.B12, J2.SH, J3.2, Q2.2, Q5.2, Q6.2, Q7.2, R8.2, R9.2, R12.2, R18.2, R19.2, R22.2, R23.2, R27.2, R28.2, R35.2, R37.2, R41.2, SW1.3, SW2.2, SW3.2, TP2.1, U1.57, U2.4, U3.1, U3.4, U3.8, U3.9, U4.2, U5.1, U5.3, U5.9, U6.2, U6.3, U6.8, Y1.2, Y1.4
I2C_SCL: J1.15, R14.2, U1.7, U3.12
I2C_SDA: J1.16, R15.2, U1.8, U3.2
IMU_INT: U1.10, U3.5
LCD_CS: J1.13, U1.15
LCD_D0: J1.10, U1.16
LCD_D1: J1.9, U1.18
LCD_D2: J1.8, U1.19
LCD_D3: J1.7, U1.14
LCD_RST: J1.12, U1.12
LCD_SCK: J1.11, U1.17
LEDA: J1.2, R13.2
LED_CHG_A: D3.2, R31.2
LED_DONE_A: D4.2, R32.2
PWR_EN: R28.1, R39.1, SW1.2, TP8.1, U6.1
RF_ANT: AE1.1, C13.1, L2.2
RF_CHIP: C12.1, L2.1, U1.1
SENSE_BASE: Q5.1, R34.2, R35.1
SENSE_GATE: Q4.1, Q5.3, R33.2
STRAP45: R8.1, U1.51
STRAP46: R9.1, U1.52
SW1: L3.1, U6.9
SW2: L3.2, U6.7
USB_D+: J2.A6, J2.B6, R20.1, TP4.1, U4.1, U4.6
USB_D-: J2.A7, J2.B7, R21.1, TP5.1, U4.3, U4.4
USB_MCU_D+: R20.2, U1.26
USB_MCU_D-: R21.2, U1.25
VBUS: C19.1, C20.1, D1.1, D2.2, J2.A4, J2.A9, J2.B4, J2.B9, Q3.1, R22.1, R31.1, R32.1, R38.1, TP6.1, U4.5, U5.4
VDD_RF: C3.1, C4.1, C5.1, FB1.2, U1.2, U1.3
VDD_SPI: C9.1, C10.1, C11.1, R7.1, U1.29, U2.8
VSYS: C22.1, C23.1, C29.1, D2.1, Q3.2, SW1.1, U6.10
XTAL_N: C2.1, U1.53, Y1.3
XTAL_P: L1.1, U1.54
XTAL_P_LOAD: C1.1, L1.2, Y1.1

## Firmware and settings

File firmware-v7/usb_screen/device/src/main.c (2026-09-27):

#include "ui/badge_ui.h"
#include "ui/ui_transition_cache.h"
#include "ui/ui_transition_compositor.h"
#include "ui/apps.h"
#include "physical_display.h"
#include "esp_lv_adapter.h"
#include "protocol.h"
#include "bridge_protocol.h"
#include "perf_stats.h"
#include "runtime_monitor.h"
#include "display_perf.h"
#include "frame_trace.h"
#include "map_perf.h"
#include "wallpaper_service.h"
#include "management.h"
#include "driver/gpio.h"
#include "driver/usb_serial_jtag.h"
#include "esp_timer.h"
#include "esp_heap_caps.h"
#include "esp_psram.h"
#include "esp_adc/adc_oneshot.h"
#include "esp_adc/adc_cali.h"
#include "esp_adc/adc_cali_scheme.h"
#include "nvs_flash.h"
#include "nvs.h"
#include "freertos/FreeRTOS.h"
#include "freertos/task.h"
#include "freertos/semphr.h"

/* Official adapter is the sole lv_timer_handler owner. Link wrapper retains
 * whole-handler wall time without changing the upstream component. */
static uint64_t service_poll_us;
uint32_t __real_lv_timer_handler(void);
uint32_t __wrap_lv_timer_handler(void){
    frame_trace(11,0);int64_t start=runtime_begin();uint64_t before=service_poll_us;uint32_t delay=__real_lv_timer_handler();frame_trace(12,delay);
    if(start)runtime_end(MON_GUI,start+(service_poll_us-before));
    return delay;
}

static badge_state_t state={.brightness=70,.wallpaper_index=-1,.battery_mv=-1,.wifi_rssi=-127,.live=true,.wifi_enabled=true};
void wifi_service_init(badge_state_t *state);
void wifi_service_poll(void);
void ble_service_init(badge_state_t *state);
void ble_service_poll(void);
void motion_service_init(void);
void motion_service_poll(void);
static jx_parser_t *parser;
static uint8_t *packet;
static char *usb_snapshot;
static bool attached;
static bool bridge;
static int monitor_scene=-1,monitor_remaining;
static unsigned monitor_period=400;
static uint32_t monitor_epoch;
static uint32_t tick(void);
static bool probing,probe_reduced,probe_sleep,probe_lcd;
static bool flush_pending,flush_content,flush_last;
static lv_display_t *lcd_display;
static void flush_wait(lv_display_t *display);
static void flush_poll(void);
#if CABADGE_DISPLAY_PERF
static unsigned probe_count=3;
static int probe_scene;
static uint32_t probe_epoch,probe_internal,probe_psram,probe_copy_time,probe_max_frame_gap,probe_last_frame;
#endif
static bool probe_manual;
static struct {perf_stats_t dma,wait,touch;uint32_t loop_max;uint32_t queue_us,wire_us,wait_us,submitted,scanning_ms;int scan_result;uint32_t last_loop;int64_t touch_at;} *extra;
static int probe_page;
static uint32_t probe_frame_bytes;
static int64_t probe_start_us;
#if CABADGE_DISPLAY_PERF
static perf_stats_t probe_stats,probe_flush_stats,probe_frame_stats;
#endif
static uint32_t probe_flush_time,probe_wait_time;
static void probe_stop(void){
    if(!probing)return;
    flush_wait(lcd_display);
    probing=false;free(extra);extra=NULL;lv_obj_invalidate(lv_screen_active());state.reduced_motion=probe_reduced;
    badge_ui_probe_restore(probe_page);badge_ui_sleep(probe_sleep);badge_ui_refresh();
}
static void probe_event(lv_event_t *e){
    /* Detailed legacy probe fences the frame; normal UI/runtime sampling does not. */
    switch(lv_event_get_code(e)){
    case LV_EVENT_RENDER_START:frame_trace(1,0);break;
    case LV_EVENT_FLUSH_START:frame_trace(2,0);break;
    case LV_EVENT_RENDER_READY:frame_trace(7,0);break;
    case LV_EVENT_REFR_READY:frame_trace(8,0);break;
    case LV_EVENT_FLUSH_WAIT_START:frame_trace(9,0);break;
    case LV_EVENT_FLUSH_WAIT_FINISH:frame_trace(10,0);break;
    case LV_EVENT_INVALIDATE_AREA:frame_trace(22,0);break;
    default:break;
    }
    flush_poll();
    if(probing&&lv_event_get_code(e)==LV_EVENT_RENDER_READY)flush_wait(lv_event_get_target(e));
    display_perf_event(e);
    runtime_event(e);
#if CABADGE_DISPLAY_PERF
    if(!probing||tick()-probe_epoch<500)return;
    if(lv_event_get_code(e)==LV_EVENT_RENDER_START){probe_start_us=esp_timer_get_time();probe_frame_bytes=0;probe_flush_time=0;probe_copy_time=0;probe_wait_time=0;if(extra){extra->queue_us=extra->wire_us=extra->wait_us=0;}}
    else if(lv_event_get_code(e)==LV_EVENT_RENDER_READY&&probe_start_us){
        uint32_t frame_us=(uint32_t)(esp_timer_get_time()-probe_start_us);
        perf_add(&probe_stats,frame_us>probe_wait_time?frame_us-probe_wait_time:0,probe_frame_bytes);
        perf_add(&probe_flush_stats,probe_flush_time,probe_copy_time);
        perf_add(&probe_frame_stats,frame_us,0);
        if(extra){
            perf_add(&extra->dma,extra->queue_us,extra->wire_us);perf_add(&extra->wait,extra->wait_us,0);
            if(extra->touch_at){perf_add(&extra->touch,(uint32_t)(esp_timer_get_time()-extra->touch_at),0);extra->touch_at=0;}
        }
        probe_start_us=0;
        uint32_t now=tick();if(probe_last_frame&&now-probe_last_frame>probe_max_frame_gap)probe_max_frame_gap=now-probe_last_frame;probe_last_frame=now;
        uint32_t n=heap_caps_get_free_size(MALLOC_CAP_INTERNAL|MALLOC_CAP_8BIT);if(n<probe_internal)probe_internal=n;
        n=heap_caps_get_free_size(MALLOC_CAP_SPIRAM|MALLOC_CAP_8BIT);if(n<probe_psram)probe_psram=n;
    }
#endif
}

static uint32_t bridge_seen,bridge_request,bridge_request_crc;
static uint8_t bridge_result;
static esp_err_t settings_result;
static void save_settings(void);
static nvs_handle_t settings;
static adc_oneshot_unit_handle_t adc;
static adc_cali_handle_t calibration;
static adc_channel_t adc_channel;
static uint32_t tick(void){return (uint32_t)(esp_timer_get_time()/1000);}

static bool send_packet(uint8_t type,const void *data,size_t n){
    size_t count=jx_packet(packet,type,data,n);
    int written=usb_serial_jtag_write_bytes(packet,count,pdMS_TO_TICKS(150));
    if(written!=(int)count){attached=false;return false;}
    return true;
}
#if CABADGE_TRANSITION_COMPOSITOR_PERF
void ui_transition_compositor_report(const char *json){if(attached)send_packet(46,json,strlen(json));}
#endif

#if CABADGE_DISPLAY_PERF
static void probe_begin_scene(void){
    probe_epoch=tick();probe_start_us=0;memset(&probe_stats,0,sizeof(probe_stats));
    memset(&probe_flush_stats,0,sizeof(probe_flush_stats));memset(&probe_frame_stats,0,sizeof(probe_frame_stats));probe_max_frame_gap=probe_last_frame=0;
    probe_internal=heap_caps_get_free_size(MALLOC_CAP_INTERNAL|MALLOC_CAP_8BIT);
    probe_psram=heap_caps_get_free_size(MALLOC_CAP_SPIRAM|MALLOC_CAP_8BIT);
    if(extra){memset(extra,0,sizeof(*extra));extra->last_loop=tick();extra->scan_result=-1;}
    badge_ui_page(0,false);if(!probe_manual)badge_ui_probe_scene(probe_scene,0);
    if(probe_scene==5){uint8_t cmd[]={MG_VERSION,MG_WIFI_SCAN};extra->scan_result=wifi_service_control(cmd,sizeof(cmd));}
}
static void probe_poll(void){
    if(!probing)return;
    if(probe_lcd&&physical_display_error()){
        const char *error="{\"schema\":1,\"error\":\"lcd_transfer_failed\"}";send_packet(BR_PERF_RESULT,error,strlen(error));probe_stop();return;
    }
    if(!attached||!bridge||wallpaper_busy()){
        const char *error="{\"schema\":1,\"error\":\"interrupted\"}";
        if(attached)send_packet(BR_PERF_RESULT,error,strlen(error));
        probe_stop();return;
    }
    uint32_t elapsed=tick()-probe_epoch;
    if(extra){
        bool scanning,connecting;int error,count;badge_wifi_ap_t aps[12];
        wifi_service_snapshot(&scanning,&connecting,&error,aps,&count);
        if(scanning)extra->scanning_ms+=tick()-extra->last_loop;
        extra->last_loop=tick();
    }
    if(elapsed>=(probe_manual?8500:4500)){
        char result[4600];badge_ble_info_t radio={0};ble_service_snapshot(&radio);
        snprintf(result,sizeof(result),"{\"schema\":1,\"timing_mode\":\"adapter_frame_fence\",\"dma_subphase_available\":false,\"scene\":%d,\"firmware\":\"" UI_VERSION "\",\"pcb\":\"c7c59dff\",\"elapsed_ms\":%lu,\"frames\":%u,\"samples\":%u,\"render_us_p50\":%lu,\"render_us_p95\":%lu,\"render_us_total\":%llu,\"flush_bytes_p95\":%lu,\"flush_bytes_total\":%llu,\"internal_free_min\":%lu,\"psram_free_min\":%lu,\"wifi_enabled\":%s,\"wifi_connected\":%s,\"ble_enabled\":%s,\"ble_inbound\":%s,\"ble_outbound\":%s,\"lcd_connected\":true,\"lcd_transfer\":%s,\"flush_us_p95\":%lu,\"copy_us_p95\":%lu,\"frame_us_p95\":%lu,\"frame_gap_ms_max\":%lu,\"lcd_qspi_hz\":%d,\"cpu_mhz\":240,\"done\":%s}",
            probe_scene,(unsigned long)(elapsed-500),probe_stats.total,probe_stats.count,
            (unsigned long)perf_percentile(&probe_stats,50,0),(unsigned long)perf_percentile(&probe_stats,95,0),(unsigned long long)probe_stats.us,
            (unsigned long)perf_percentile(&probe_stats,95,1),(unsigned long long)probe_stats.bytes,(unsigned long)probe_internal,(unsigned long)probe_psram,
            state.wifi_enabled?"true":"false",state.wifi_connected==1?"true":"false",radio.enabled?"true":"false",radio.inbound?"true":"false",radio.outbound?"true":"false",probe_lcd?"true":"false",
            (unsigned long)perf_percentile(&probe_flush_stats,95,0),(unsigned long)perf_percentile(&probe_flush_stats,95,1),
            (unsigned long)perf_percentile(&probe_frame_stats,95,0),(unsigned long)probe_max_frame_gap,physical_display_clock_hz(),probe_scene==(int)probe_count-1?"true":"false");
        if(extra){
            size_t used=strlen(result)-1;
            snprintf(result+used,sizeof(result)-used,",\"audit\":true,\"scene_count\":%u,\"manual\":%s,\"queue_us_p95\":%lu,\"wire_us_p95\":%lu,\"dma_wait_us_p95\":%lu,\"touch_samples\":%u,\"touch_to_flush_us_p95\":%lu,\"gui_loop_us_max\":%lu,\"scanning_ms\":%lu,\"scan_result\":%d,\"lcd_updates\":%lu,\"internal_largest\":%u,\"psram_largest\":%u}",
                probe_count,probe_manual?"true":"false",(unsigned long)perf_percentile(&extra->dma,95,0),(unsigned long)perf_percentile(&extra->dma,95,1),
                (unsigned long)perf_percentile(&extra->wait,95,0),extra->touch.total,(unsigned long)perf_percentile(&extra->touch,95,0),
                (unsigned long)extra->loop_max,(unsigned long)extra->scanning_ms,extra->scan_result,(unsigned long)extra->submitted,
                (unsigned)heap_caps_get_largest_free_block(MALLOC_CAP_INTERNAL|MALLOC_CAP_8BIT),(unsigned)heap_caps_get_largest_free_block(MALLOC_CAP_SPIRAM|MALLOC_CAP_8BIT));
        }
        if(extra){
            size_t used=strlen(result)-1;used+=snprintf(result+used,sizeof(result)-used,",\"frame_bytes\":[");
            for(unsigned i=0;i<probe_stats.count;i++)used+=snprintf(result+used,sizeof(result)-used,"%s%lu",i?",":"",(unsigned long)probe_stats.values[i].bytes);
            snprintf(result+used,sizeof(result)-used,"]}");
        }
        send_packet(BR_PERF_RESULT,result,strlen(result));
        if(++probe_scene==(int)probe_count){probe_stop();return;}probe_begin_scene();
    }
    if(!probe_manual)badge_ui_probe_scene(probe_scene,tick()-probe_epoch);
}
#else
static void probe_poll(void){}
#endif
/* The official panel IO ISR releases LVGL only after its final DMA chunk.
 * Accounting is consumed here in the adapter's GUI task, never in the ISR. */
static void flush_poll(void){
    uint32_t us;
    if(flush_pending&&physical_display_complete(&us)){
        flush_pending=false;
        display_perf_complete(us,flush_last,!physical_display_error());
        runtime_flush(us,0,flush_last,!physical_display_error(),flush_content);
        if(probing&&probe_start_us){probe_flush_time+=us;if(extra&&flush_last&&!physical_display_error())extra->submitted++;}
    }
}
static void flush_wait(lv_display_t *display){
    (void)display;if(!flush_pending)return;
    int64_t at=esp_timer_get_time();physical_display_wait();
    uint32_t blocked=(uint32_t)(esp_timer_get_time()-at);
    runtime_flush(0,blocked,false,true,false);probe_wait_time+=blocked;flush_poll();
}
static esp_err_t adapter_draw(lv_display_t *display,esp_lcd_panel_handle_t panel,int x1,int y1,int x2,int y2,const void *pixels,void *ctx){
    frame_trace(3,(uint32_t)pixels);(void)panel;(void)ctx;
    if(flush_pending)flush_wait(display);
    if(probing&&probe_start_us)probe_frame_bytes+=(x2-x1)*(y2-y1)*2;
    if(probing&&!probe_lcd)return ESP_ERR_NOT_ALLOWED;
    configASSERT(!flush_pending);flush_pending=true;flush_content=runtime_content_frame();flush_last=lv_display_flush_is_last(display);
    esp_err_t err=physical_display_draw(x1,y1,x2,y2,pixels);
    if(err!=ESP_OK){flush_pending=false;uint32_t ignored;physical_display_complete(&ignored);}
    return err;
}
static void physical_pointer_read(lv_indev_t *indev,lv_indev_data_t *data){
    if(probing&&!probe_manual){data->state=LV_INDEV_STATE_RELEASED;return;}
    physical_touch_read(indev,data);
    static int x,y;static bool down;
    bool changed=data->point.x!=x||data->point.y!=y||down!=(data->state==LV_INDEV_STATE_PRESSED);
    if(extra&&probe_manual&&changed&&!extra->touch_at)extra->touch_at=esp_timer_get_time();
    x=data->point.x;y=data->point.y;down=data->state==LV_INDEV_STATE_PRESSED;
}
static lv_indev_t *physical_input;
static esp_lcd_touch_t touch_handle={.config={.x_max=360,.y_max=360,.rst_gpio_num=GPIO_NUM_NC,.int_gpio_num=GPIO_NUM_NC}};
static esp_err_t adapter_touch(esp_lcd_touch_handle_t tp,esp_lcd_touch_point_data_t *points,uint8_t *count,uint8_t capacity,void *ctx){
    (void)tp;(void)ctx;*count=0;if(!capacity||!physical_input)return ESP_OK;
    lv_indev_data_t data={0};physical_pointer_read(physical_input,&data);
    if(data.state==LV_INDEV_STATE_PRESSED){points[0]=(esp_lcd_touch_point_data_t){.x=data.point.x,.y=data.point.y,.strength=1};*count=1;}
    return ESP_OK;
}
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
void app_main(void){
    gpio_set_level(GPIO_NUM_1,0);gpio_set_direction(GPIO_NUM_1,GPIO_MODE_OUTPUT);
    gpio_set_level(GPIO_NUM_38,0);gpio_set_direction(GPIO_NUM_38,GPIO_MODE_OUTPUT);
    if(!esp_psram_is_initialized())return;
    if(nvs_flash_init()==ESP_OK&&nvs_open("badge_ui",NVS_READWRITE,&settings)==ESP_OK){
        int32_t value;
        if(nvs_get_i32(settings,"brightness",&value)==ESP_OK&&value>=10&&value<=100)state.brightness=value;
        if(nvs_get_i32(settings,"reduced",&value)==ESP_OK&&(value==0||value==1))state.reduced_motion=value;
        if(nvs_get_i32(settings,"wallpaper",&value)==ESP_OK&&value>=0&&value<33)state.wallpaper_index=value;
    }
    usb_serial_jtag_driver_config_t usb={.tx_buffer_size=16384,.rx_buffer_size=4096};
    if(usb_serial_jtag_driver_install(&usb)!=ESP_OK)return;
    /* USB protocol storage never goes to LCD DMA; reserve internal RAM for radio/DMA. */
    parser=heap_caps_calloc(1,sizeof(*parser),MALLOC_CAP_SPIRAM|MALLOC_CAP_8BIT);
    packet=heap_caps_malloc(JX_HEADER+JX_MAX_PAYLOAD,MALLOC_CAP_SPIRAM|MALLOC_CAP_8BIT);
    usb_snapshot=heap_caps_malloc(8192,MALLOC_CAP_SPIRAM|MALLOC_CAP_8BIT);
    ESP_ERROR_CHECK(parser&&packet&&usb_snapshot?ESP_OK:ESP_ERR_NO_MEM);
    physical_display_init();
    esp_lv_adapter_config_t adapter=ESP_LV_ADAPTER_DEFAULT_CONFIG();
    adapter.task_stack_size=12288;adapter.task_core_id=1;adapter.task_priority=4;
    adapter.task_min_delay_ms=1;adapter.task_max_delay_ms=5;
    ESP_ERROR_CHECK(esp_lv_adapter_init(&adapter));
    ESP_ERROR_CHECK(esp_lv_adapter_set_default_display_idf_callback_registration_enabled(false));
    esp_lv_adapter_display_config_t config=ESP_LV_ADAPTER_DISPLAY_SPI_WITH_PSRAM_DEFAULT_CONFIG(
        physical_display_panel(),physical_display_io(),360,360,ESP_LV_ADAPTER_ROTATE_0);
    lv_display_t *display=esp_lv_adapter_register_display(&config);lcd_display=display;
    ESP_ERROR_CHECK(display?ESP_OK:ESP_ERR_NO_MEM);
    physical_display_bind(display);
    /* LVGL 9.4 otherwise busy-spins here; drain official SPI transactions to sleep until DMA completes. */
    lv_display_set_flush_wait_cb(display,flush_wait);
    esp_lv_adapter_draw_bitmap_callbacks_t draw={.custom_draw_bitmap=adapter_draw};
    ESP_ERROR_CHECK(esp_lv_adapter_set_draw_bitmap_callbacks(display,&draw,NULL));
    lv_timer_set_period(lv_display_get_refr_timer(display),16);
    lv_display_add_event_cb(display,probe_event,LV_EVENT_ALL,NULL);
    lv_obj_remove_style_all(lv_screen_active());lv_obj_remove_flag(lv_screen_active(),LV_OBJ_FLAG_SCROLLABLE);
    badge_ui_create(lv_screen_active(),&state,save_settings);management_init(&state);battery_init();motion_service_init();wifi_service_init(&state);ble_service_init(&state);wallpaper_service_init();app_service_init();
    physical_touch_init();
    esp_lv_adapter_touch_config_t input=ESP_LV_ADAPTER_TOUCH_DEFAULT_CONFIG(display,&touch_handle);
    input.callbacks.custom_touch_read=adapter_touch;
    physical_input=esp_lv_adapter_register_touch(&input);
    ESP_ERROR_CHECK(physical_input?ESP_OK:ESP_ERR_NO_MEM);
    lv_timer_set_period(lv_indev_get_read_timer(physical_input),10);lv_indev_set_scroll_limit(physical_input,10);
    badge_ui_control_bind(local_control);badge_ui_connected(true);
    lv_timer_create(service_poll,5,NULL);
    ESP_ERROR_CHECK(esp_lv_adapter_start());
}

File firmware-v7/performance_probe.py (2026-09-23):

"""Board rendering / physical LCD probe. USB transports results, never timed pixels."""
from pathlib import Path
import datetime
import json
import math
import struct
import sys
import threading
import time
import serial

ROOT = Path(__file__).resolve().parent
sys.path.insert(0, str(ROOT / 'usb_screen'))
from framing import packet, Decoder

LATEST = ROOT / 'build' / 'probe-latest.json'
SCENES = ('Carousel', '抽屉', '蓝色名片', '静态壁纸', '菜单切换', 'Wi-Fi 扫描期间 Carousel')


def check_ready(data, lcd=False):
    if len(data) != 12 or data[0] != 1 or data[1] != 16 or struct.unpack_from('<HH', data, 2) != (360, 360) or struct.unpack_from('<I', data, 8)[0] != 0xc7c59dff:
        raise ValueError('设备协议或 PCB 不匹配')
    if lcd and not struct.unpack_from('<H', data, 6)[0] & 8:
        raise ValueError('实屏采样需要 7.1.2-lcd 或更新固件')
    if not struct.unpack_from('<H', data, 6)[0] & 4:
        raise ValueError('当前板端固件不支持性能采样，请先安装 7.1.0-preview')


def summarize(rows, lcd=False):
    audit=bool(rows and rows[0].get("audit")); count=rows[0].get("scene_count",3) if audit else 3
    if count not in (1,3,6) or len(rows) != count or [r.get('scene') for r in rows] != list(range(count)):
        raise ValueError('采样场景不完整，未更新校准')
    for row in rows:
        if row.get('schema') != 1 or row.get('pcb') != 'c7c59dff' or row.get('firmware') not in ('7.1.0-preview', '7.1.1-lcd', '7.1.2-lcd', '7.1.3-lcd', '7.1.4-profile', '7.1.5-usb', '7.1.6-memory', '7.1.7-ram', '7.1.8-partial', '7.1.9-async', '7.2.0-monitor', '7.2.1-monitor', '7.2.2-monitor', '7.2.3-monitor','7.3.3-fluid','7.3.4-async','7.3.5-refresh16','7.3.6-anim16','7.3.7-mem','7.3.8-mem','7.3.9-mem','7.3.10-mem','7.4.0-idf61','7.4.1-idf61','7.4.2-idf61','7.4.3-idf61','7.5.0-library','7.5.1-direct','7.5.2-web','7.5.3-http','7.5.4-upload','7.6.0-apps','7.9.0-direct') or row.get('lcd_transfer', False) is not lcd:
            raise ValueError('采样版本不匹配')
        if row['firmware'] == '7.1.0-preview':
            if row.get('lcd_connected') is not False:
                raise ValueError('旧版无屏采样标记无效')
        elif row.get('lcd_connected') is not True or type(row.get('lcd_transfer')) is not bool:
            raise ValueError('缺少显示采样模式标记')
        for key in ('frames', 'samples', 'elapsed_ms', 'render_us_p50', 'render_us_p95', 'flush_bytes_p95', 'render_us_total', 'flush_bytes_total'):
            if type(row.get(key)) is not int or row[key] < (0 if audit else 1):
                raise ValueError('采样字段无效')
        if not (0 if audit else 10) <= row['frames'] == row['samples'] <= 256 or not 3900 <= row['elapsed_ms'] <= (35000 if row.get('manual') else 20000) or row['render_us_p50'] > row['render_us_p95'] or row['render_us_p95'] > 500000 or row['flush_bytes_p95'] > 259200*32:
            raise ValueError('有效帧不足、缓冲已满或数据超界，未更新校准')
        if lcd:
            if row.get('firmware') not in ('7.1.2-lcd', '7.1.3-lcd', '7.1.4-profile', '7.1.5-usb', '7.1.6-memory', '7.1.7-ram', '7.1.8-partial', '7.1.9-async', '7.2.0-monitor', '7.2.1-monitor', '7.2.2-monitor', '7.2.3-monitor','7.3.3-fluid','7.3.4-async','7.3.5-refresh16','7.3.6-anim16','7.3.7-mem','7.3.8-mem','7.3.9-mem','7.3.10-mem','7.4.0-idf61','7.4.1-idf61','7.4.2-idf61','7.4.3-idf61','7.5.0-library','7.5.1-direct','7.5.2-web','7.5.3-http','7.5.4-upload','7.6.0-apps','7.9.0-direct') or row.get('lcd_transfer') is not True or row.get('lcd_qspi_hz') != 40000000:
                raise ValueError('缺少实体输出测量')
            for key in ('flush_us_p95', 'copy_us_p95', 'frame_us_p95', 'frame_gap_ms_max'):
                if type(row.get(key)) is not int or row[key] < 0:
                    raise ValueError('实屏测量字段无效')
            if (row['frames'] and row['flush_us_p95'] <= 0) or row['frame_us_p95'] < row['flush_us_p95']:
                raise ValueError('实屏传输计时无效')
            row['completed_fps'] = round(row.get('lcd_updates',row['frames']) * 1000 / row['elapsed_ms'], 2)
            row['render_fps'] = round(row['frames'] * 1000 / row['elapsed_ms'],2)
            row['panel_scan_hz'] = None
            if audit: row['touch_response_ms'] = row.get('touch_to_flush_us_p95',0)/1000 if row.get('touch_samples') else None
            if audit:
                if row.get('scene_count')!=count or row.get('lcd_updates')!=row['frames'] or len(row.get('frame_bytes',[]))!=row['samples'] or sum(row['frame_bytes'])!=row['flush_bytes_total']:
                    raise ValueError('逐帧传输数据不完整')
        if not lcd:
            row['headless_present_fps'] = round(row['frames'] * 1000 / row['elapsed_ms'], 2)
            # Sequential estimate; real DMA overlap, panel scan and bus gaps are unmeasured.
            row['estimated_qspi40_p95_frame_ms'] = round(max(1000 / 30, row['render_us_p95'] / 1000 + row['flush_bytes_p95'] / 20000), 3)
    return {'schema': 1, 'lcd_transfer': lcd, 'firmware': rows[0]['firmware'], 'pcb': 'c7c59dff',
            'captured_at': datetime.datetime.now().astimezone().isoformat(),
            'measurement': 'Detailed probe fences each frame; render excludes GUI wait only; worker transfer overlaps rendering; use runtime_probe for normal pipeline FPS' if lcd and rows[0]['firmware'] in ('7.3.4-async','7.3.5-refresh16','7.3.6-anim16','7.3.7-mem','7.3.8-mem','7.3.9-mem','7.3.10-mem','7.4.0-idf61','7.4.1-idf61','7.4.2-idf61','7.4.3-idf61','7.5.0-library','7.5.1-direct','7.5.2-web','7.5.3-http','7.5.4-upload','7.6.0-apps','7.9.0-direct') else 'ESP32 render excludes LCD flush; completed SPI frame rate is not panel scan rate' if lcd else 'ESP32 LVGL render wall-time, no LCD transfer; radio state unchanged; not a radio load test',
            'calibration': 'Physical measurement only; PC calibration unchanged' if lcd else 'Worst scene render P95 + current PC dirty bytes / ideal QSPI bandwidth; 30 FPS cap; not LCD FPS',
            'render_ms': max(r['render_us_p95'] for r in rows) / 1000, 'scenes': rows}
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

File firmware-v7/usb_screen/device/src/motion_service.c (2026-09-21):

#include "ui/badge_ui.h"
#include "shake_detector.h"
#include "driver/i2c_master.h"
#include "esp_timer.h"

static i2c_master_dev_handle_t accel;
static bool ready;
static shake_detector_t detector;
static esp_err_t read_reg(uint8_t reg,void *data,size_t size){return i2c_master_transmit_receive(accel,&reg,1,data,size,20);}
static esp_err_t write_reg(uint8_t reg,uint8_t value){uint8_t data[]={reg,value};return i2c_master_transmit(accel,data,2,20);}
void motion_service_init(void){
    /* Fabricated c7c59dff: SCL GPIO2, SDA GPIO3, SC7A20 SA0 tied to GND. */
    i2c_master_bus_handle_t bus;
    i2c_master_bus_config_t cfg={.i2c_port=I2C_NUM_0,.sda_io_num=3,.scl_io_num=2,
        .clk_source=I2C_CLK_SRC_DEFAULT,.glitch_ignore_cnt=7,.flags.enable_internal_pullup=false};
    if(i2c_new_master_bus(&cfg,&bus)!=ESP_OK)return;
    i2c_device_config_t dev={.dev_addr_length=I2C_ADDR_BIT_LEN_7,.device_address=0x18,.scl_speed_hz=100000};
    if(i2c_master_bus_add_device(bus,&dev,&accel)!=ESP_OK)return;
    uint8_t id=0,ctrl1=0,ctrl4=0;
    if(read_reg(0x0f,&id,1)!=ESP_OK||id!=0x11)return;
    if(write_reg(0x23,0x88)!=ESP_OK||write_reg(0x20,0x47)!=ESP_OK)return;
    ready=read_reg(0x20,&ctrl1,1)==ESP_OK&&read_reg(0x23,&ctrl4,1)==ESP_OK&&ctrl1==0x47&&ctrl4==0x88;
}
void motion_service_poll(void){
    if(!ready)return;
    if(!badge_ui_is_asleep()){detector=(shake_detector_t){0};return;}
    static uint32_t previous;
    uint32_t now=(uint32_t)(esp_timer_get_time()/1000);
    if(now-previous<20)return;
    previous=now;
    uint8_t status,bytes[6];
    if(read_reg(0x27,&status,1)!=ESP_OK){detector=(shake_detector_t){0};return;}
    if(!(status&8))return; /* Wait for a new XYZ sample. */
    if(read_reg(0x28|0x80,bytes,sizeof(bytes))!=ESP_OK){detector=(shake_detector_t){0};return;}
    int16_t xyz[3];for(int i=0;i<3;i++)xyz[i]=(int16_t)(bytes[i*2]|((uint16_t)bytes[i*2+1]<<8))/16;
    if(shake_detect(&detector,true,now,xyz))badge_ui_motion();
}

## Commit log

2026-09-21 release: CABadge v1.0 with firmware 7.3.7-mem
    [3D-model-LCSC-list.csv, BOM-DRAFT.csv, Controls_Test.kicad_sch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]
2026-09-21 docs: correct J1 replacement connector procurement
    [BOM-DRAFT.csv, LCSC_IMPORT_LIST.csv]
2026-09-23 release: CABadge v1.1.0 firmware 7.9.2-memory
    [partitions.csv]
2026-09-23 docs: rewrite current design architecture and handoff guides
2026-09-27 feat: integrate EAF direct wallpapers and frozen-frame transitions
    Include per-wallpaper timing and upload support, conversion documentation, unified wallpaper resources, BlueMap cache/network fixes, battery UI, and verification notes. Conversion tools remain local and are not distributed.
2026-09-30 docs(hardware): add three V6 printable models and prototype photos
    [V6_Lower.STL, V6_Slider.STL, V6_Upper.STL]
2026-09-30 docs(bom): specify 450mAh battery and upper-contact drawer FPC connector
    [BOM-DRAFT.csv, LCSC_IMPORT_LIST.csv]
2026-10-20 feat(hardware): publish V2.1 in both CAD formats
2026-10-20 fix(hardware): refresh EDA schematic snapshot
2026-10-20 feat(hardware): release V11 matching enclosure
2026-10-20 docs(hardware): sync V2.1 BOM variants
2026-10-21 docs(hardware): update V2.1 soldering guide
2026-10-27 refactor(hardware): organize board sources
    Keep V2.1 KiCad and replace its converted EDA with the native redraw. Archive V1 KiCad; preserve firmware and frozen fabrication files.
2026-10-28 fix(enclosure): publish the R2 button
2026-10-28 fix(enclosure): match Cup and Button assembly
2026-10-28 docs(enclosure): describe only fitted parts
2026-10-31 fix(firmware): pin esp_lv_decoder to 0.4.3 (#1)
    Release 0.5.0 looks for lv_version.h in the LVGL component root, so the staged build fails at CMake configure.
2026-11-01 perf(firmware): poll heap usage every 100 ms
    app_service_poll runs every 5 ms and called heap_caps_get_largest_free_block on each pass, although the result only matters while maps download. Over a 1.33 s transition window, this group's GUI task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
2026-11-01 perf(firmware): read the accelerometer at 400 kHz
    The 100 Hz SC7A20 read is a blocking I2C transaction on the GUI task. Its time per transition window fell from 268 ms to 174 ms. A 10 s check read 93 samples/s with no errors. Touch stays at 100 kHz.
2026-11-01 perf(firmware): stream transition frames with RAMWRC
    Each 16-row block went through draw_bitmap, which re-sent CASET and RASET. The compositor now sets the window once per frame, writes RAMWR then RAMWRC chunks, and waits for chunk k to finish before r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
